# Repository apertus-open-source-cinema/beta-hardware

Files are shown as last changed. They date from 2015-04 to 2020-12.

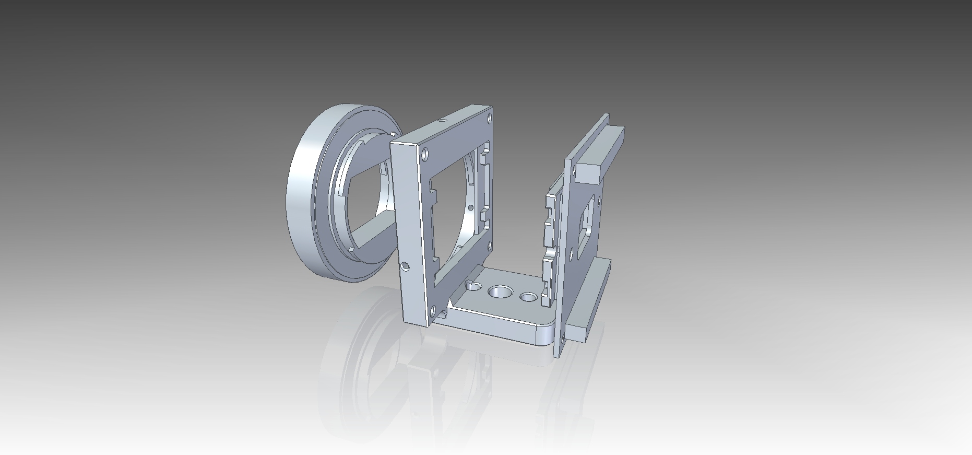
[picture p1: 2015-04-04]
Enclosure/Skeleton_E-mount/CMV12000_E-Mount_03.jpg

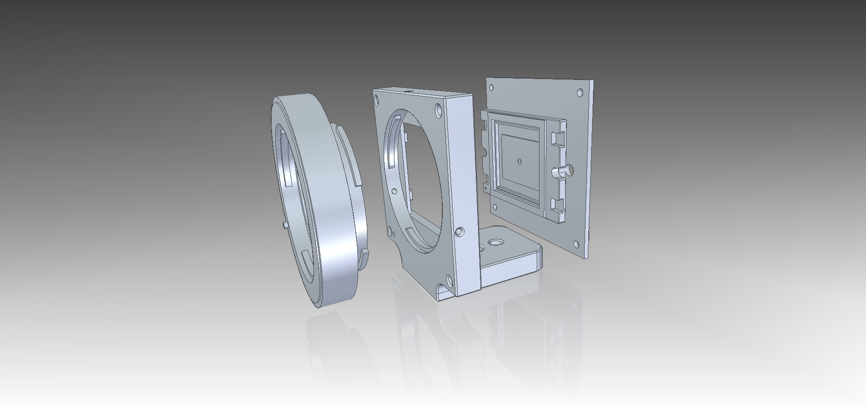
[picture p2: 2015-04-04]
Enclosure/Skeleton_E-mount/CMV12000_E-Mount_02.jpg

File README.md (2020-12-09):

View this project on [CADLAB.io](https://cadlab.io/project/23633). 

# AXIOM Beta Hardware
axiom beta enclosure concept art

This repository contains all the information and files related to the hardware of the AXIOM Beta.

The [AXIOM Beta](https://www.apertus.org/axiom-beta) is an open source, open hardware, professional-grade digital film camera made by [apertus°](https://www.apertus.org/). It is designed to be modular e.g. interchangeable sensor front end etc. and supports recording at 4K resolution.

Introduction to [camera structure](https://www.apertus.org/axiom-beta-modularity).

## Contributing
If you would like to participate in this project, please see the following links:

[apertus° Labs](https://lab.apertus.org/project/view/4/) - Tasks, discussions, etc.
Project [Wiki](https://wiki.apertus.org/index.php/Main_Page) - User manuals, BOMs etc.
Programming languages and contact [methods](https://wiki.apertus.org/index.php/How_to_Contribute).
Useful [Links](https://wiki.apertus.org/index.php/Useful_Links).

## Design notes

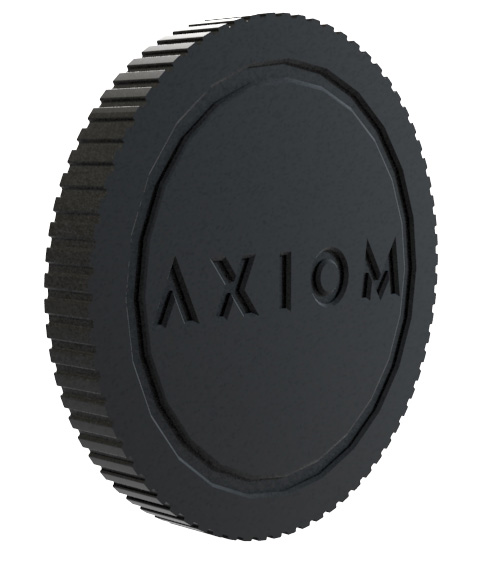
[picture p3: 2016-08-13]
E-Mount Cap/AXIOM E-Mount Cap V01 R01.jpg

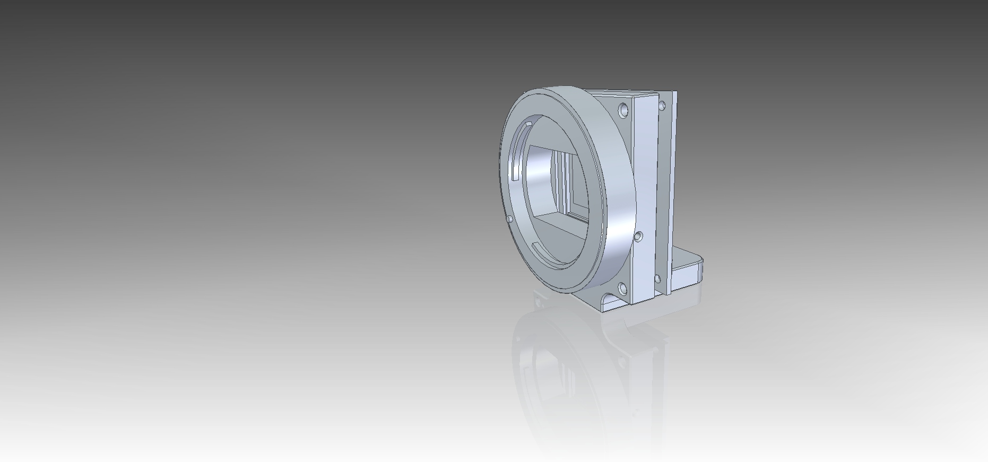
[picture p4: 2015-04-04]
Enclosure/Skeleton_E-mount/CMV12000_E-Mount_01.jpg

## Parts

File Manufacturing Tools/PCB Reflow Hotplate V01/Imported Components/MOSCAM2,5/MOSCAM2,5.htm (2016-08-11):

Autodesk Inventor Translation Report | Donnerstag, 11. August 2016 ( 20:25)
Source File: | C:\Users\spichelh\Documents\GitHub\beta-hardware\Manufacturing Tools\PCB Reflow Hotplate V01\MOSCAM2,5.SLDPRT
Translator Type: | SolidWorks | Sending System: | SolidWorks 2013
Author: |  | Translation Time: | 00:00:00
Options
Import Type: | N/A
Entity Types to Import: | Solids, Surfaces, Wires
Import into Repair Environment: | Yes
Import Assembly as Single Part: | No
Create Surfaces As: | Single Composite Feature
Check Parts during Load: | No
Auto Stitch: | No
Enable Advanced Healing: | N/A
+/- | Name | Inventor File | Status
[ ] | MOSCAM2,5.ipt | C:\Users\spichelh\Documents\GitHub\beta-hardware\Manufacturing Tools\PCB Reflow Hotplate V01\Imported Components\MOSCAM2,5\MOSCAM2,5.ipt | Successful

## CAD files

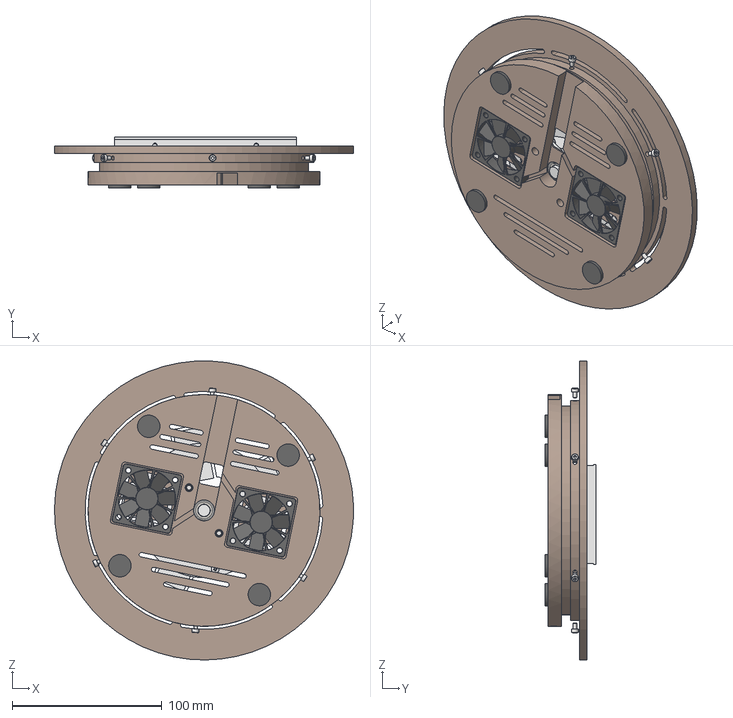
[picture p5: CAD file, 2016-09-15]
Manufacturing Tools/PCB Reflow Hotplate V01/Hotplate Assembly V01 02.stp
199.9 x 34.0 x 199.9 mm

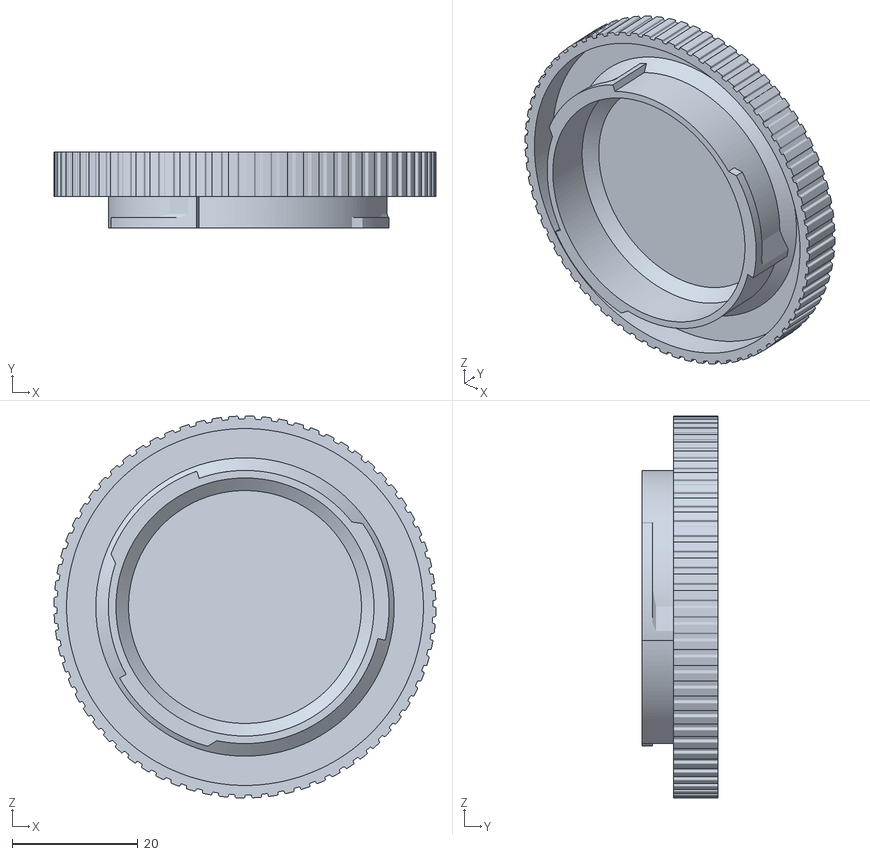
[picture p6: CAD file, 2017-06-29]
E-Mount Cap/AXIOM E-Mount Cap V01 R02.stl
60.7 x 12.0 x 60.7

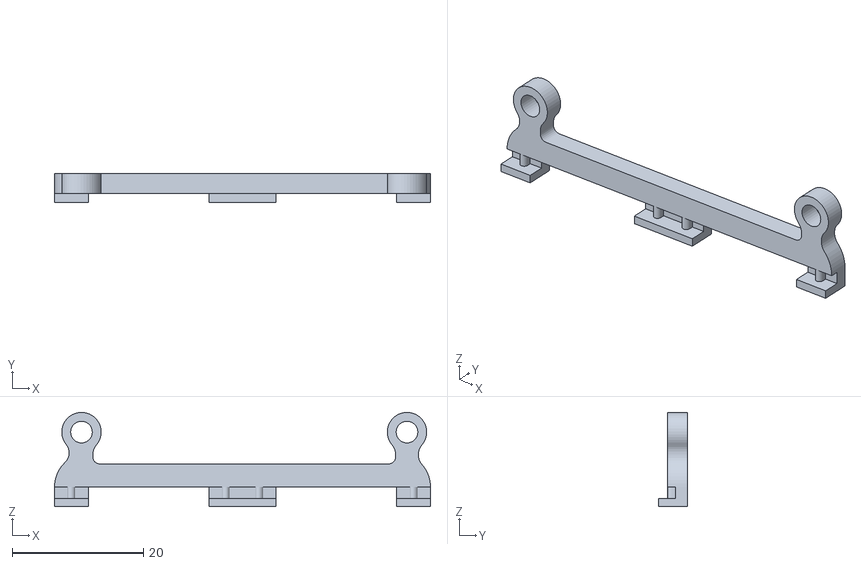
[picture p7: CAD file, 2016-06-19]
Enclosure/3D-Print-Parts/HDMIPluginModuleHolder04.stl
57.2 x 4.37 x 14.3

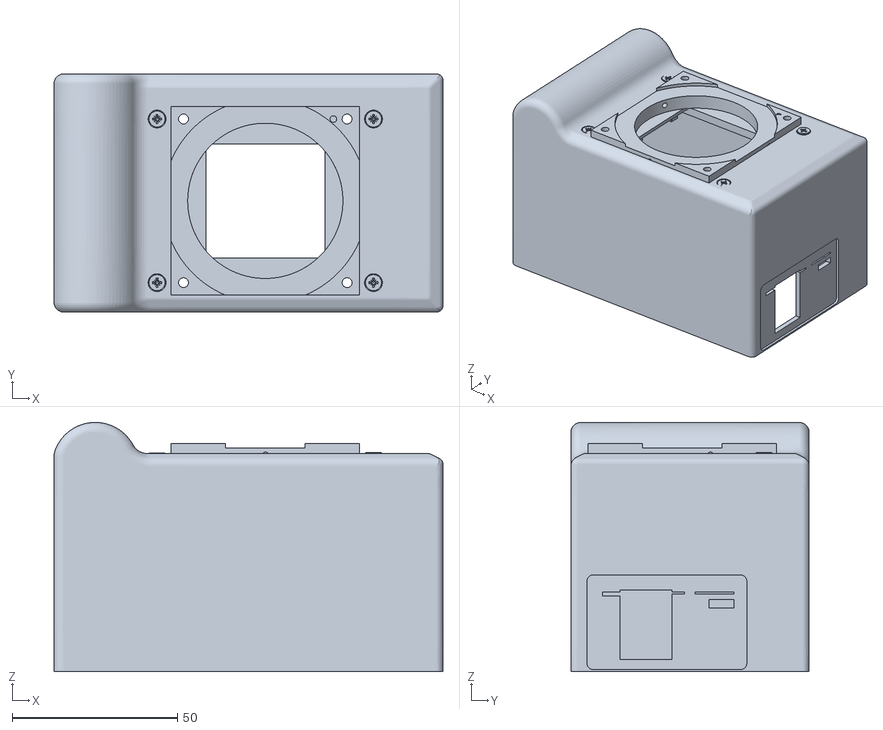
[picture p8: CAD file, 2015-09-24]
Enclosure/SimpleDesign01/SimpleDesignV2 - 01.stl
117.8 x 72.2 x 75.4

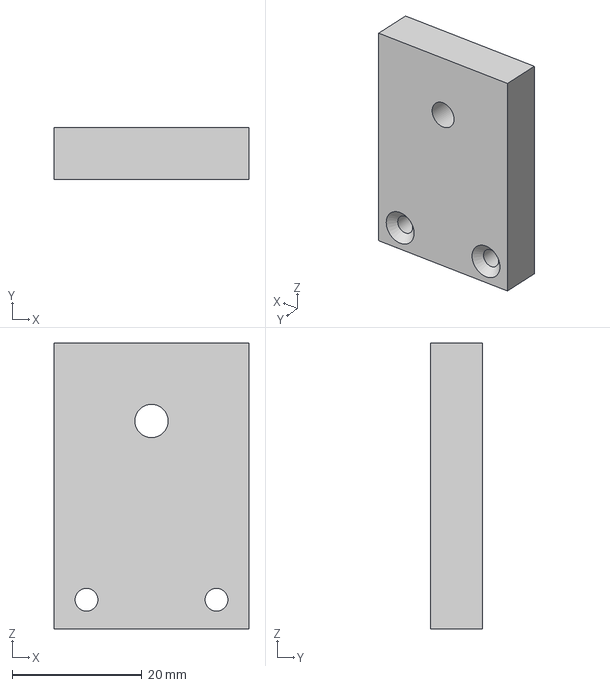
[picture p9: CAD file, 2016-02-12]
Enclosure/Skeleton_E-mount/tripod_foot_plate_150928.step
30.0 x 8.00 x 44.0 mm

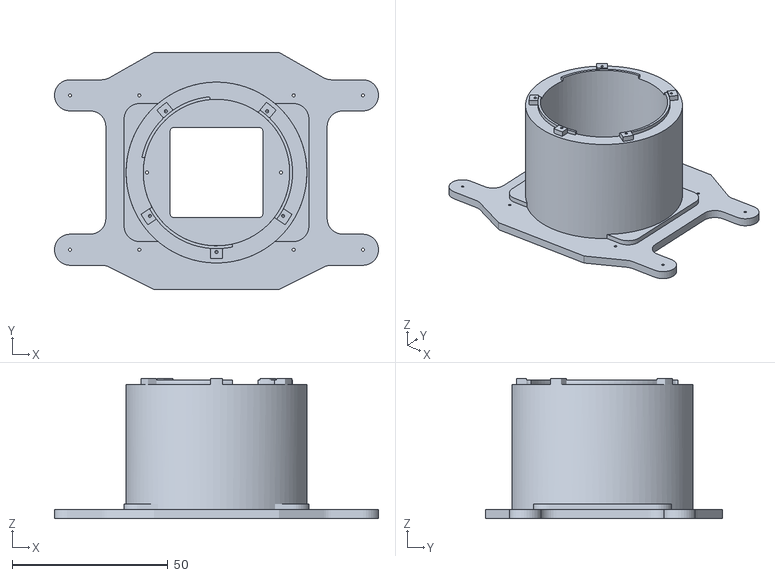
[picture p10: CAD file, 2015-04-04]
Enclosure/SkeletonV03/Skeleton V03fix-rotated.stl
103.9 x 76.1 x 45.0

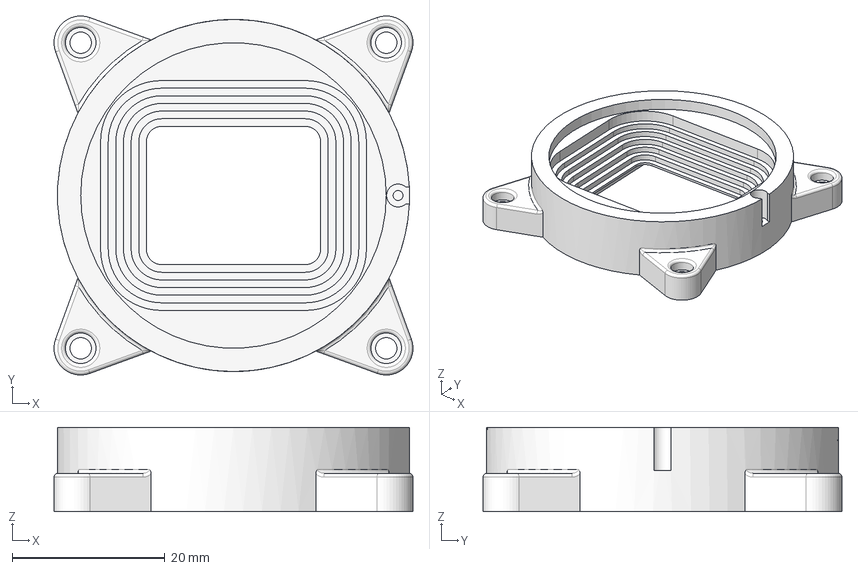
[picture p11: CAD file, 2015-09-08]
Enclosure/Version 002/E Mount.stp
47.0 x 47.0 x 11.0 mm

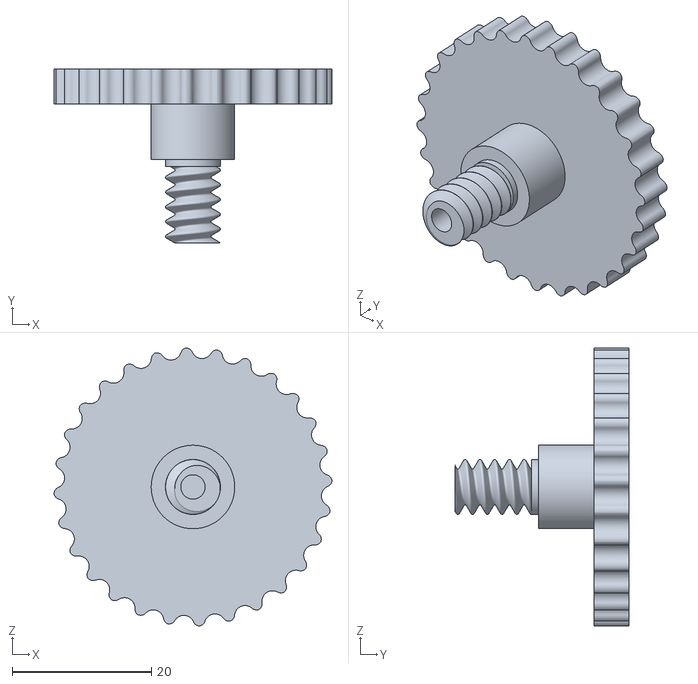
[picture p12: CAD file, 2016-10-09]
Manufacturing Tools/CMV12000 Extraction Tool V01/3d print/Knob02.stl
40.0 x 25.0 x 40.0

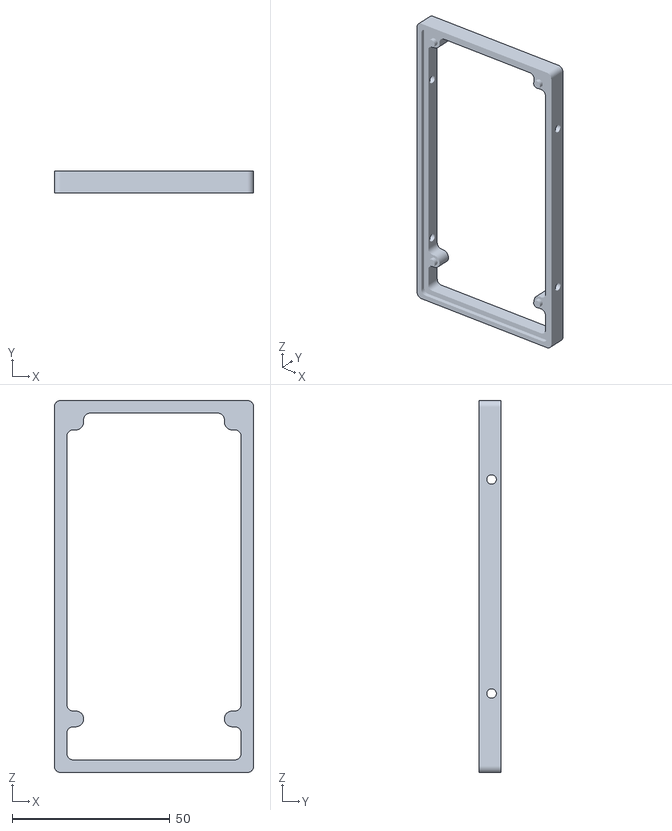
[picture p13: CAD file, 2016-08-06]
Manufacturing Tools/PCB Reflow Bracket V01/Bracket_BOT_V05.stl
63.2 x 7.00 x 117.8

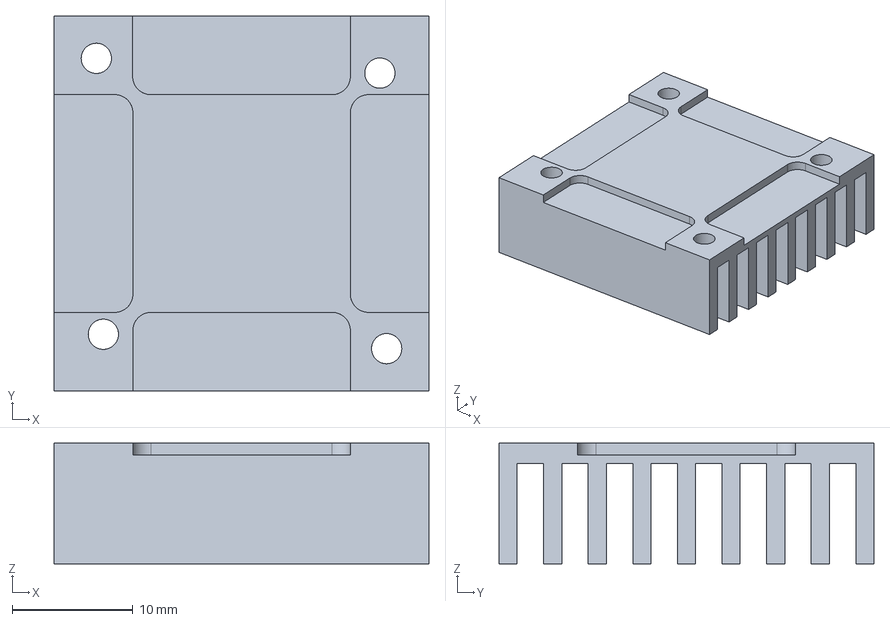
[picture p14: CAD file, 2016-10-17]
Microzed-Heatsink/Heatsink_31x31x10.stp
31.0 x 31.0 x 10.0 mm

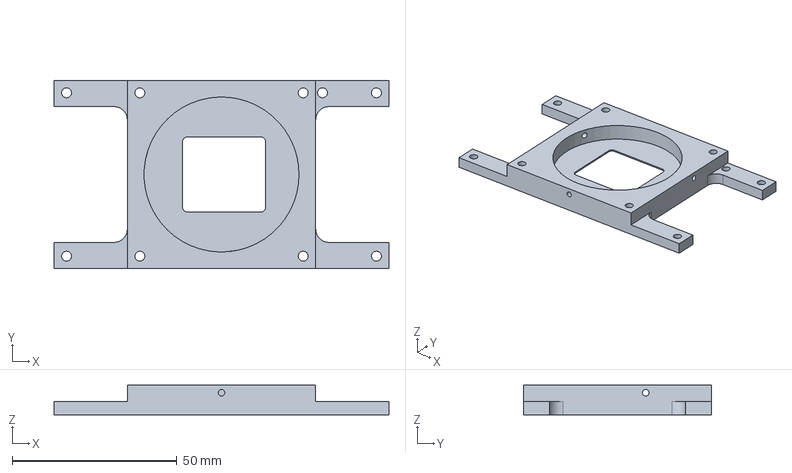
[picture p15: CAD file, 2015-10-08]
Enclosure/Skeleton_E-mount/Skeleton-Emount.stp
101.6 x 57.2 x 9.00 mm

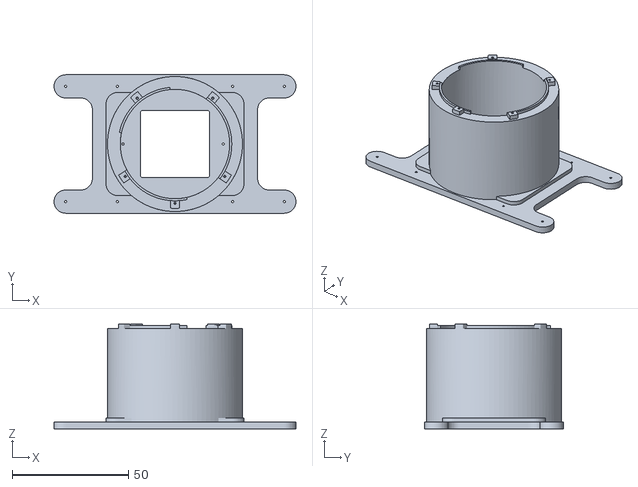
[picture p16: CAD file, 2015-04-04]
Enclosure/SkeletonV03/Skeleton V03fix-nose-cut.stl
104.0 x 59.5 x 45.0

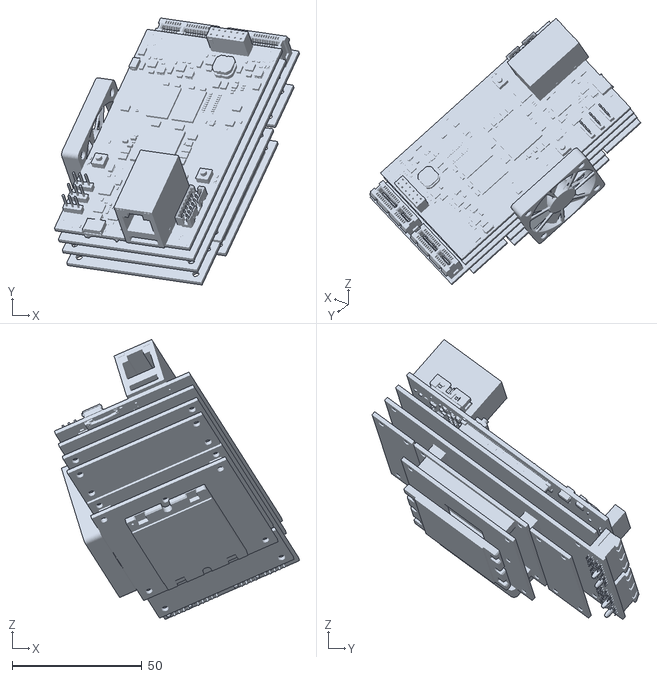
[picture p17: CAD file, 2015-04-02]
Enclosure/Version 002/PCB Stack Concept V03 02.stl
94.6 x 103.0 x 108.0

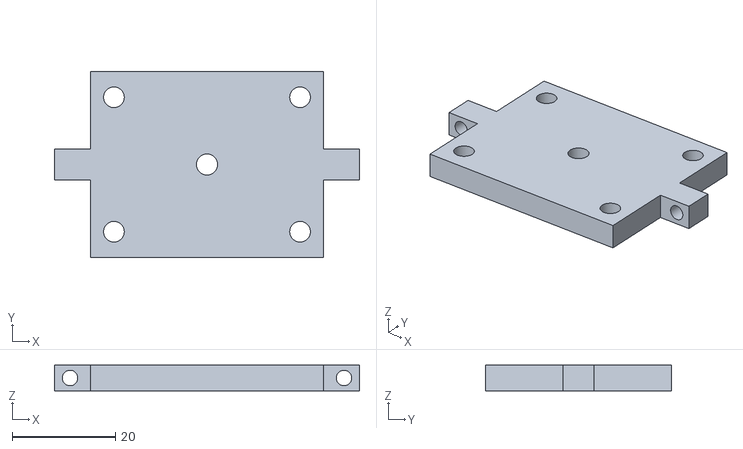
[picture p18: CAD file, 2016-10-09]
Manufacturing Tools/CMV12000 Extraction Tool V01/3d print/mover02.stl
59.0 x 35.9 x 5.00

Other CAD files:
Enclosure/SimpleDesign02/HDMI Plugin Module-Export1.dwg
E-Mount Cap/AXIOM E-Mount Cap V01 R01.step
Enclosure/3D-Print-Parts/HDMIPluginModuleHolder03.stl
Enclosure/SimpleDesign02/HDMI Plugin Module-1.dwg
E-Mount Cap/AXIOM E-Mount Cap V01 R01.3dm
E-Mount Cap/AXIOM E-Mount Cap V01 R01.sldprt
E-Mount Cap/AXIOM E-Mount Cap V01 R01.stl
E-Mount Cap/AXIOM E-Mount Cap V01 R01.x_t
Enclosure/3D-Print-Parts/Archived/HDMIPluginModuleHolder01.stl
Enclosure/3D-Print-Parts/Archived/SimpleDesignV2-R01-Back.stl
Enclosure/3D-Print-Parts/Archived/SimpleDesignV2-R01-Front.stl
Enclosure/3D-Print-Parts/HDMIPluginModuleHolder01.stl
Enclosure/3D-Print-Parts/HDMIPluginModuleHolder02.stl
Enclosure/3D-Print-Parts/PCB-Separator-Tool-V01.stl
Enclosure/3D-Print-Parts/SimpleDesignV2 - Front.stl
Enclosure/3D-Print-Parts/SimpleDesignV2-R02-Back.stl
Enclosure/3D-Print-Parts/SimpleDesignV2-R02-Front.stl
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

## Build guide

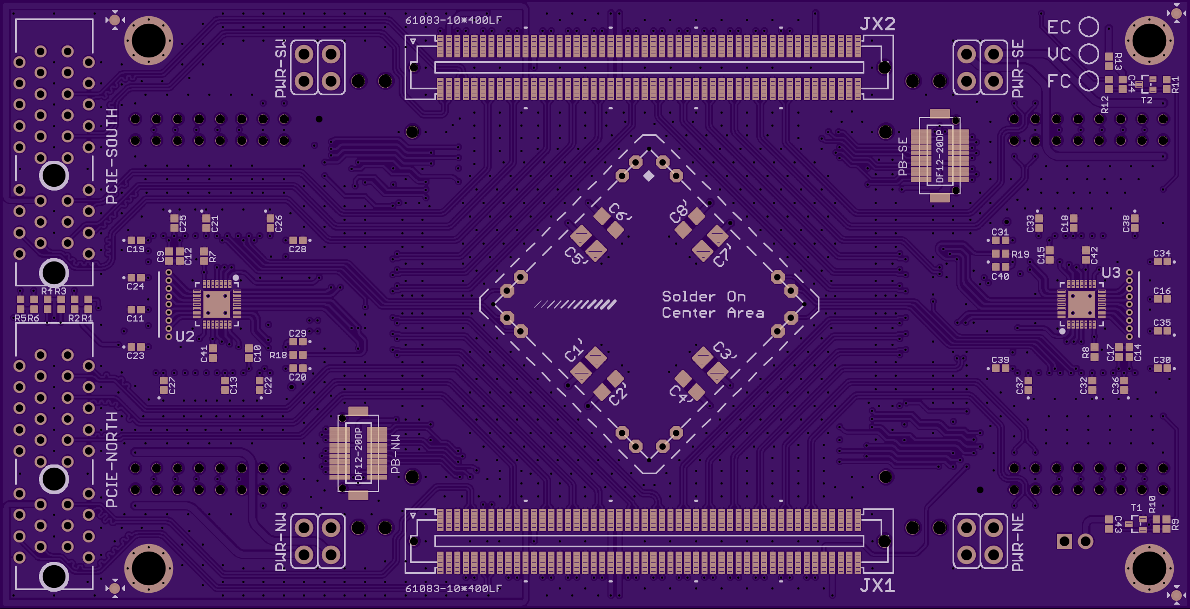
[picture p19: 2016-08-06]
Manufacturing Tools/PCB Reflow Bracket V01/Top.png

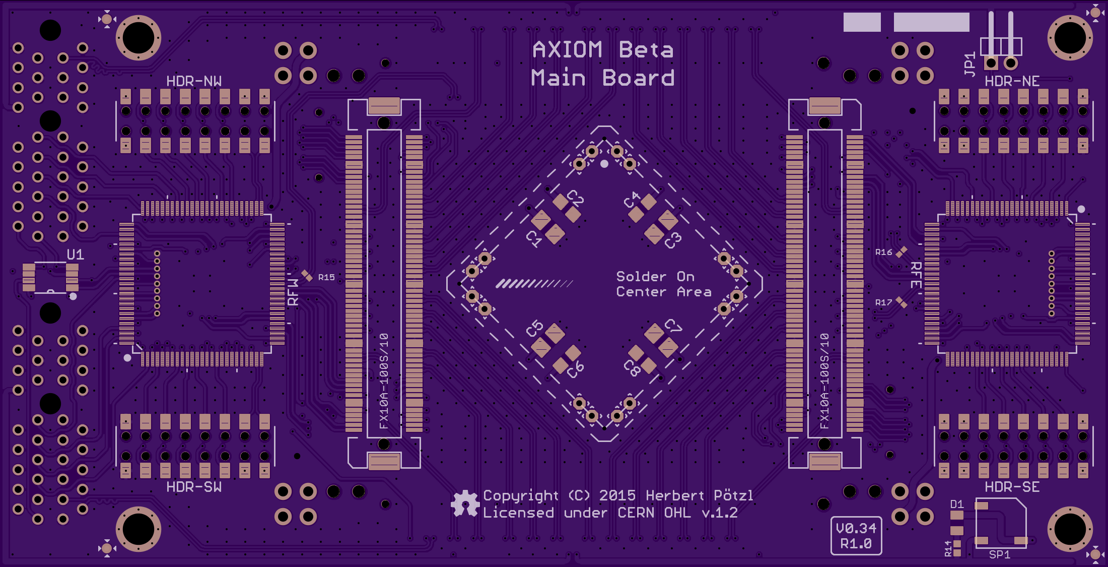
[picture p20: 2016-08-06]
Manufacturing Tools/PCB Reflow Bracket V01/Bottom.png

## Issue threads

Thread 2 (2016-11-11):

Scematics and Board Layout files are missing

jatha, 2016-11-11:

sp-apertus, 2016-11-11:
collect and commit them to github from here: https://wiki.apertus.org/index.php/AXIOM_Beta/AXIOM_Beta_Hardware#Printed_Circuit_Boards

davidak, 2017-11-12:
@herbertp will do it: https://lab.apertus.org/T827

jatha, 2017-11-13:
moved to the lab

Closed 2017-11-13.

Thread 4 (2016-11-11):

Split repository up

jatha, 2016-11-11:
Maybe it would be better to have more small repositorys with a single part instead of one big.
For examlpe an extra repo for the Lenscap, one for the Enclosure and so on...

sp-apertus, 2016-11-11:
I think it would negatively affect overview.

jatha, 2017-11-12:
ok

Closed 2017-11-12.

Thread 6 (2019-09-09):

Any interest in providing FreeCAD files?

luzpaz, 2019-09-09:
I do reach out for the FreeCAD community. In the past we've helped Open Source projects with their CAD design. Would you be interested in such a thing? It would also provide a good exercise for folks who want to learn how to use FC to create FreeCAD files for you. Let me know if you're interested?

Cheers

luzpaz, 2019-09-09:
Example: https://forum.freecadweb.org/viewtopic.php?f=8&t=38643

sp-apertus, 2019-09-10:
Hi there

I am currently doing most CAD work in the project in onshape so a FOSS alternative would be great indeed, I tried FreeCAD already for a bit but without someone helping/answering questions I did not get far unfortunately. So any help on this front would be much appreciated, I can dedicate some, not a whole lot of time to this but it would be great to get more people from our community and maybe even the outside interested.

Regards Sebastian

luzpaz, 2019-09-10:
@sp-apertus Nice! Please feel free to post on our forum when you feel ready. If you can provide proper measurements and non-proprietary files (that we can open and inspect) that would definitely facilitate the process, for sure!

sp-apertus, 2019-09-16:
What file format do you recommend?

luzpaz, 2019-09-16:
@sp-apertus well for the measurements maybe a screenshot of the technical drawings ? I recommend asking on the forum.

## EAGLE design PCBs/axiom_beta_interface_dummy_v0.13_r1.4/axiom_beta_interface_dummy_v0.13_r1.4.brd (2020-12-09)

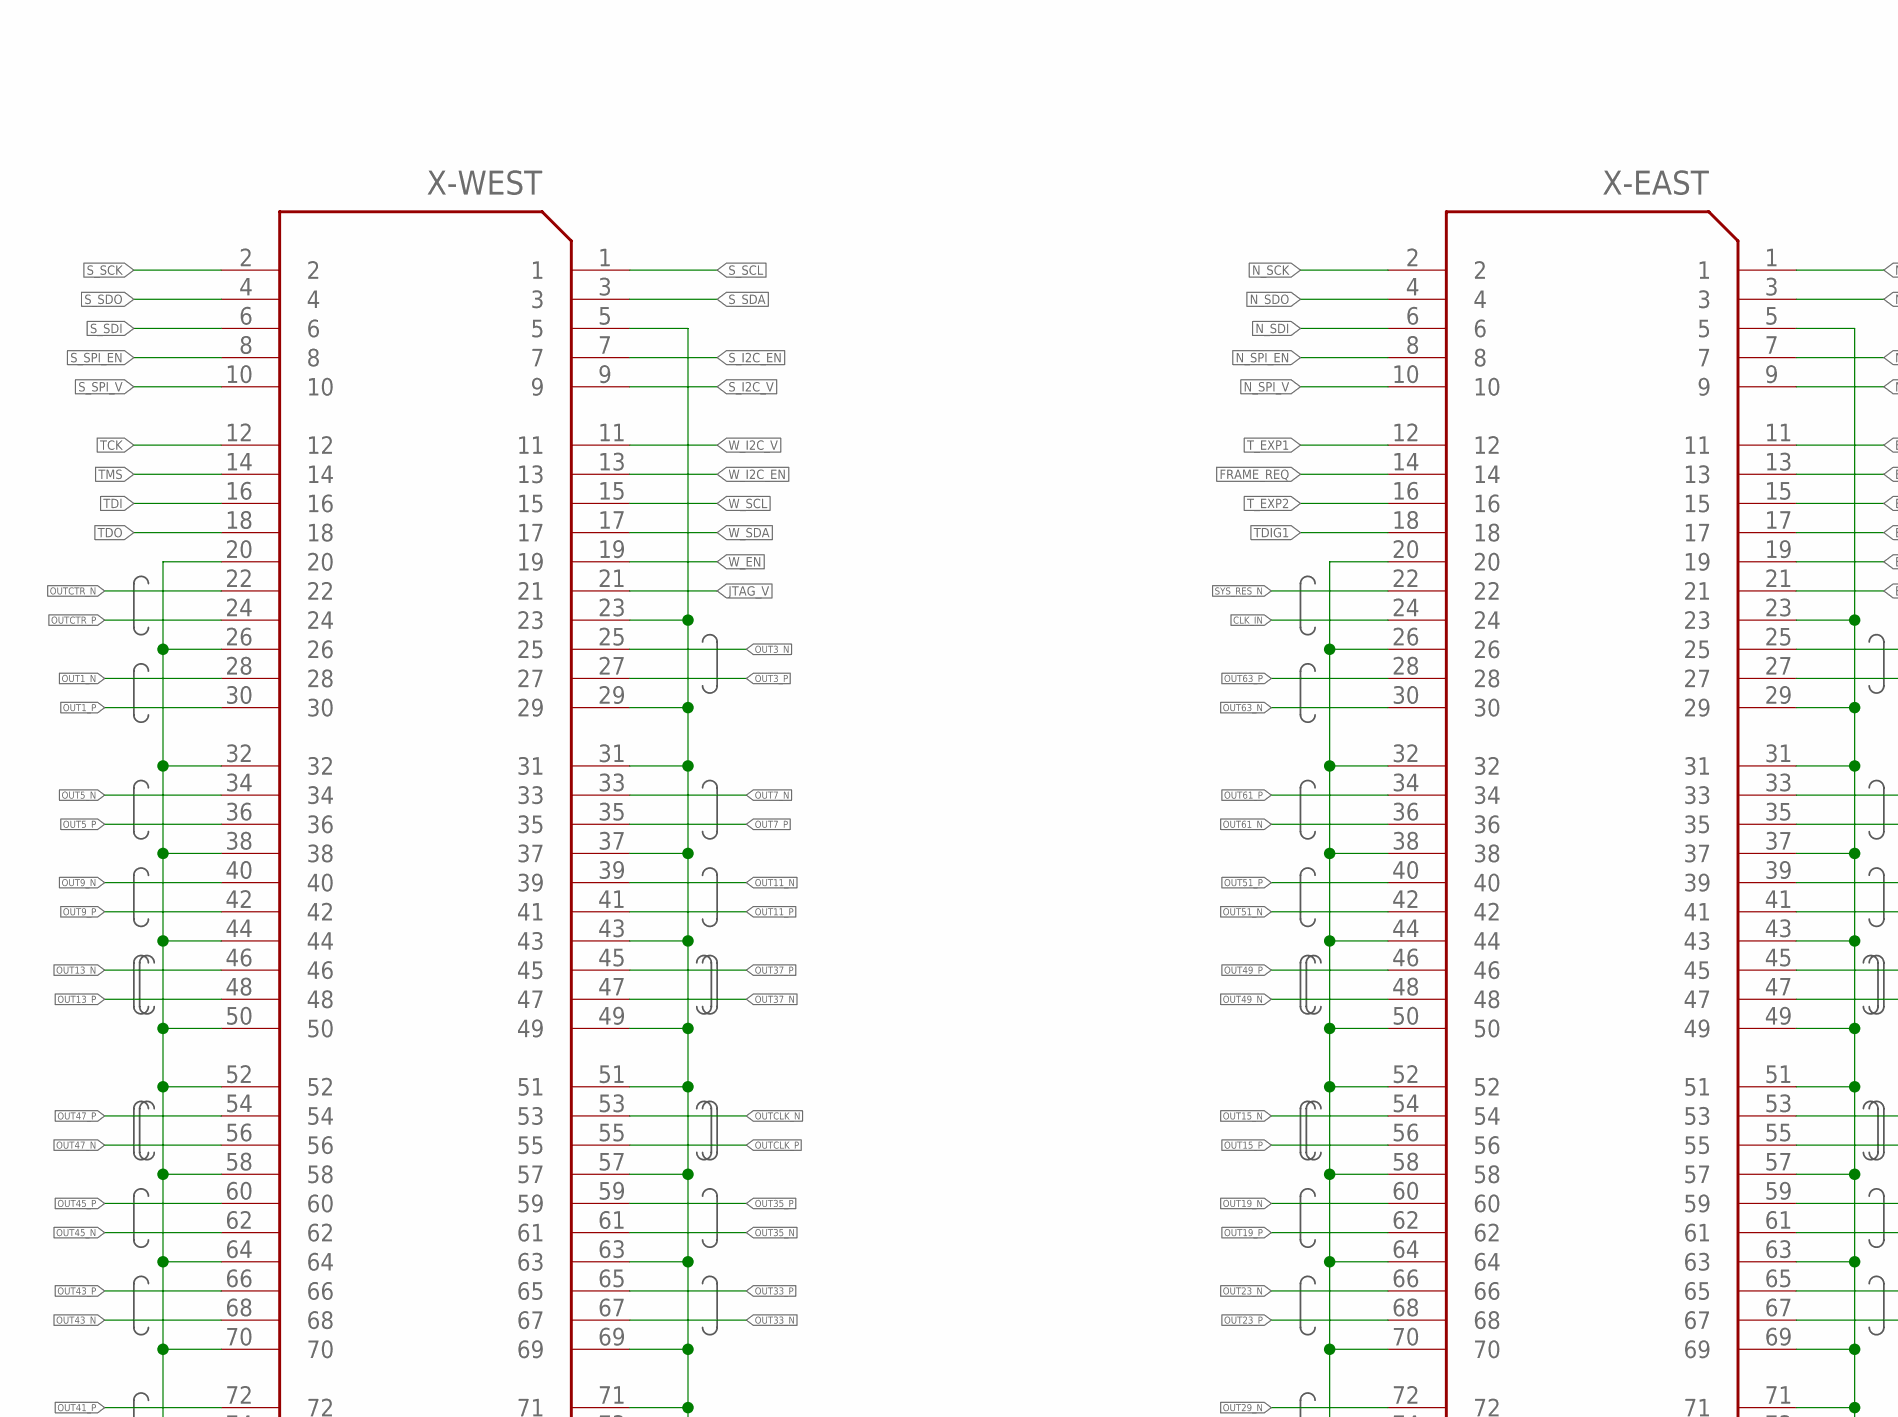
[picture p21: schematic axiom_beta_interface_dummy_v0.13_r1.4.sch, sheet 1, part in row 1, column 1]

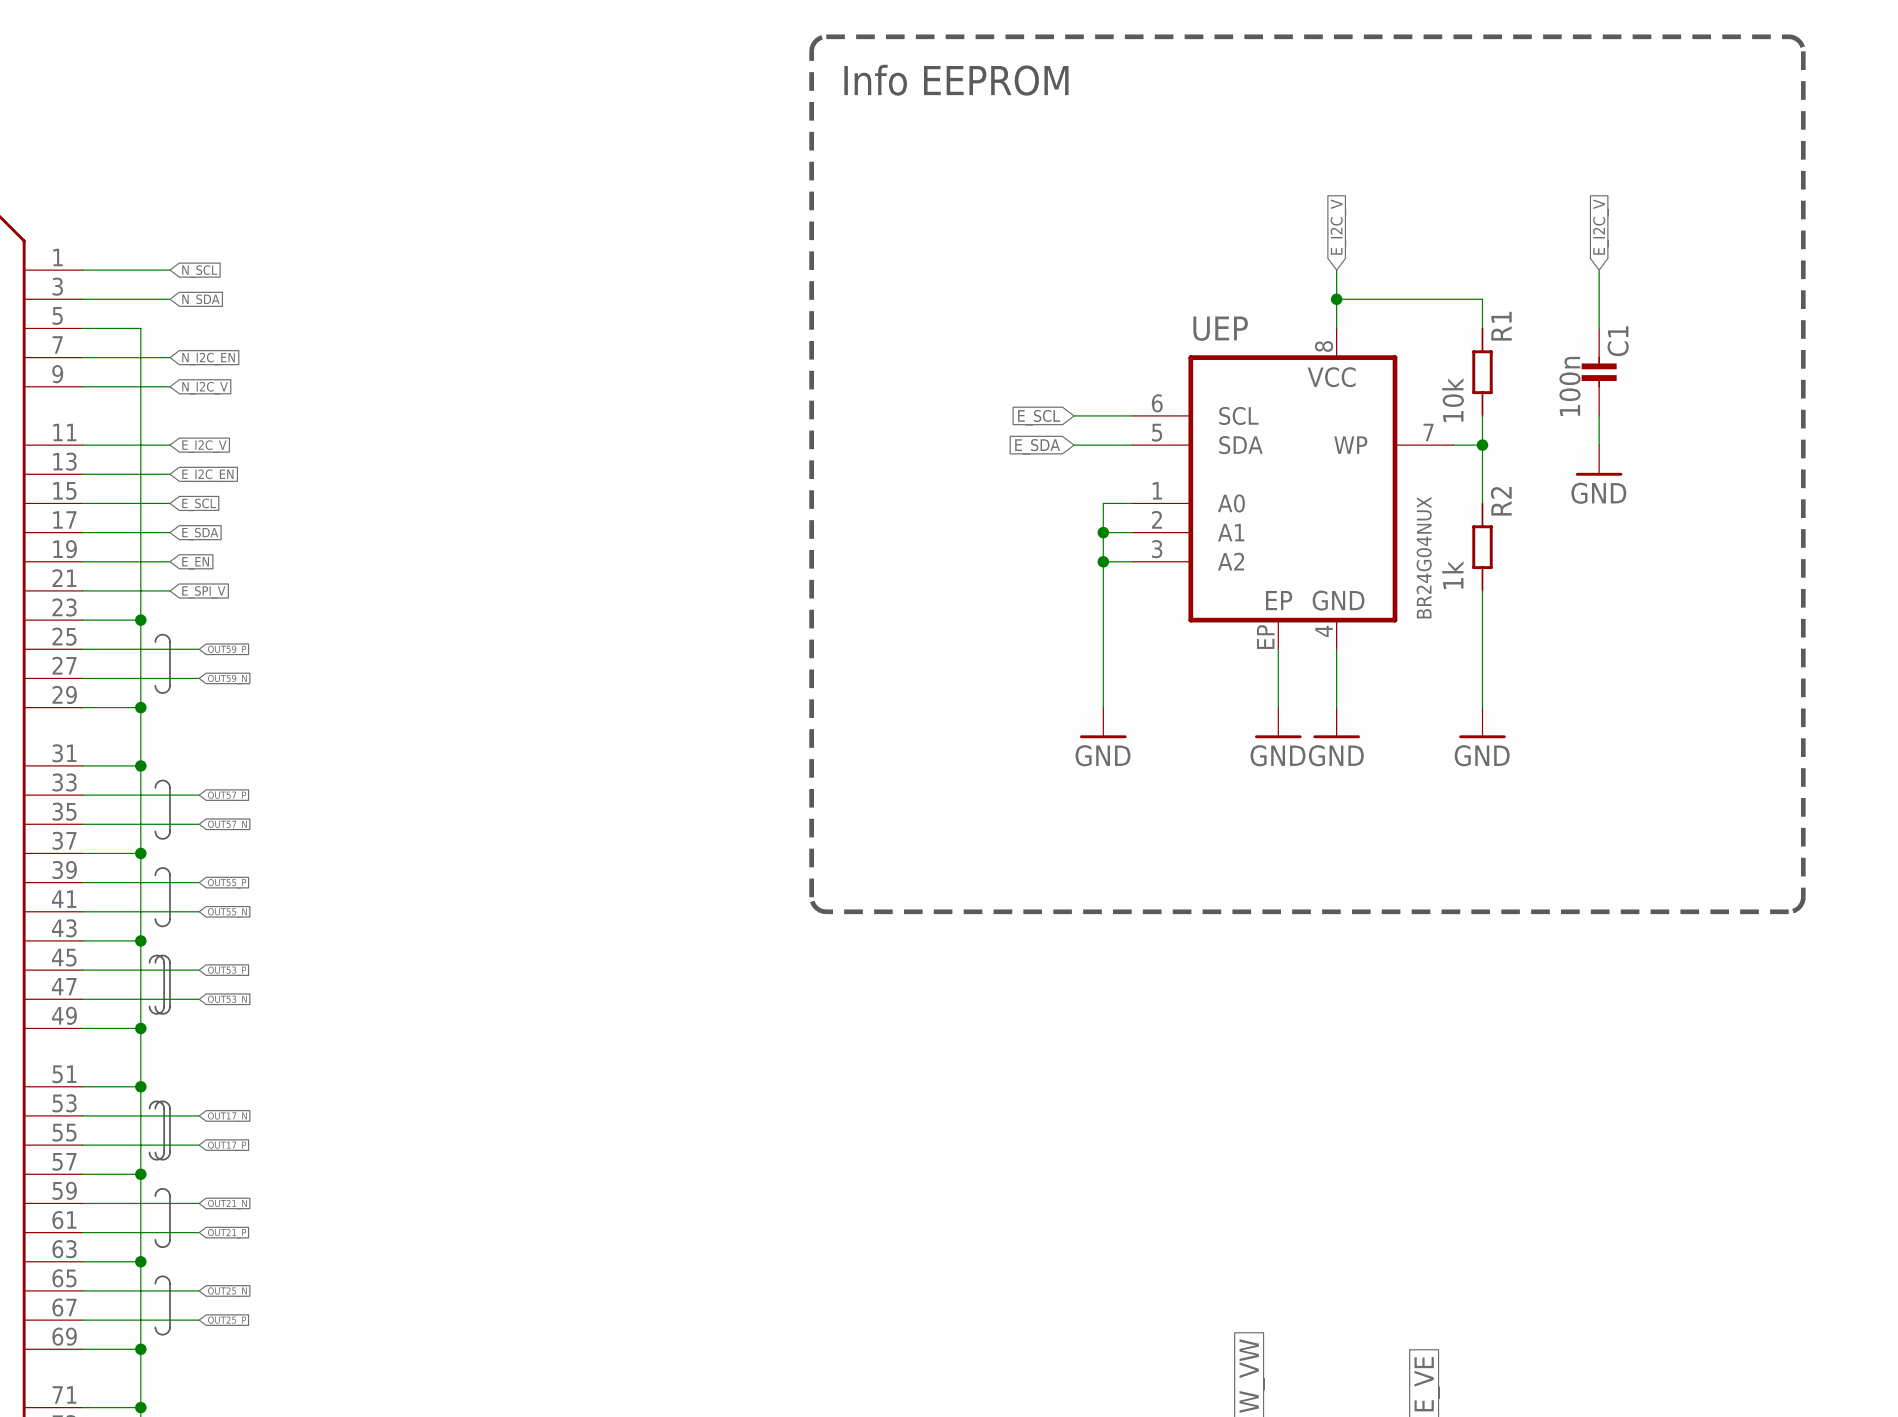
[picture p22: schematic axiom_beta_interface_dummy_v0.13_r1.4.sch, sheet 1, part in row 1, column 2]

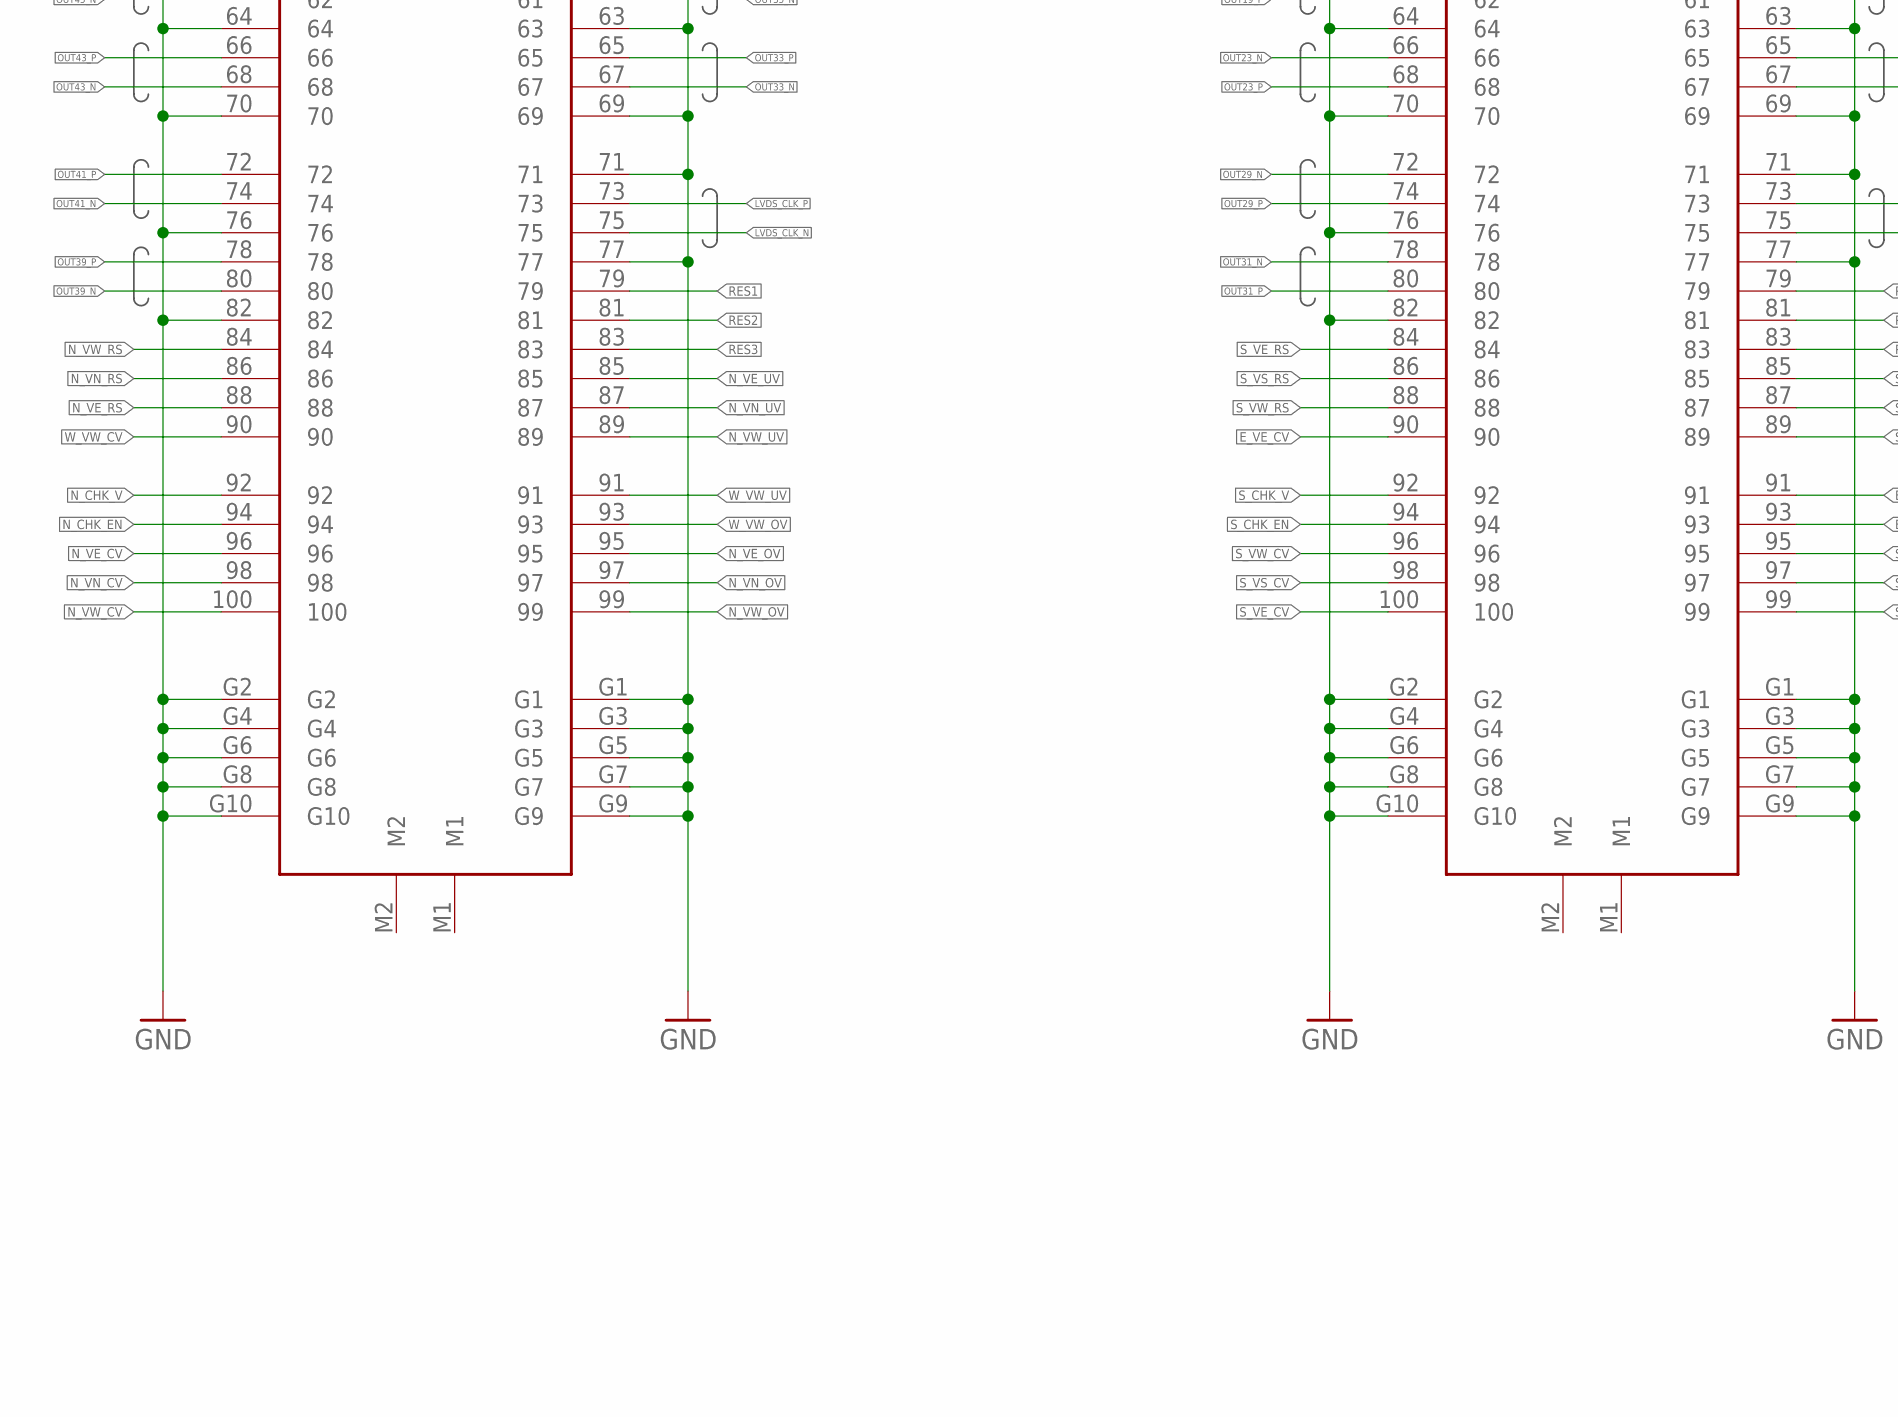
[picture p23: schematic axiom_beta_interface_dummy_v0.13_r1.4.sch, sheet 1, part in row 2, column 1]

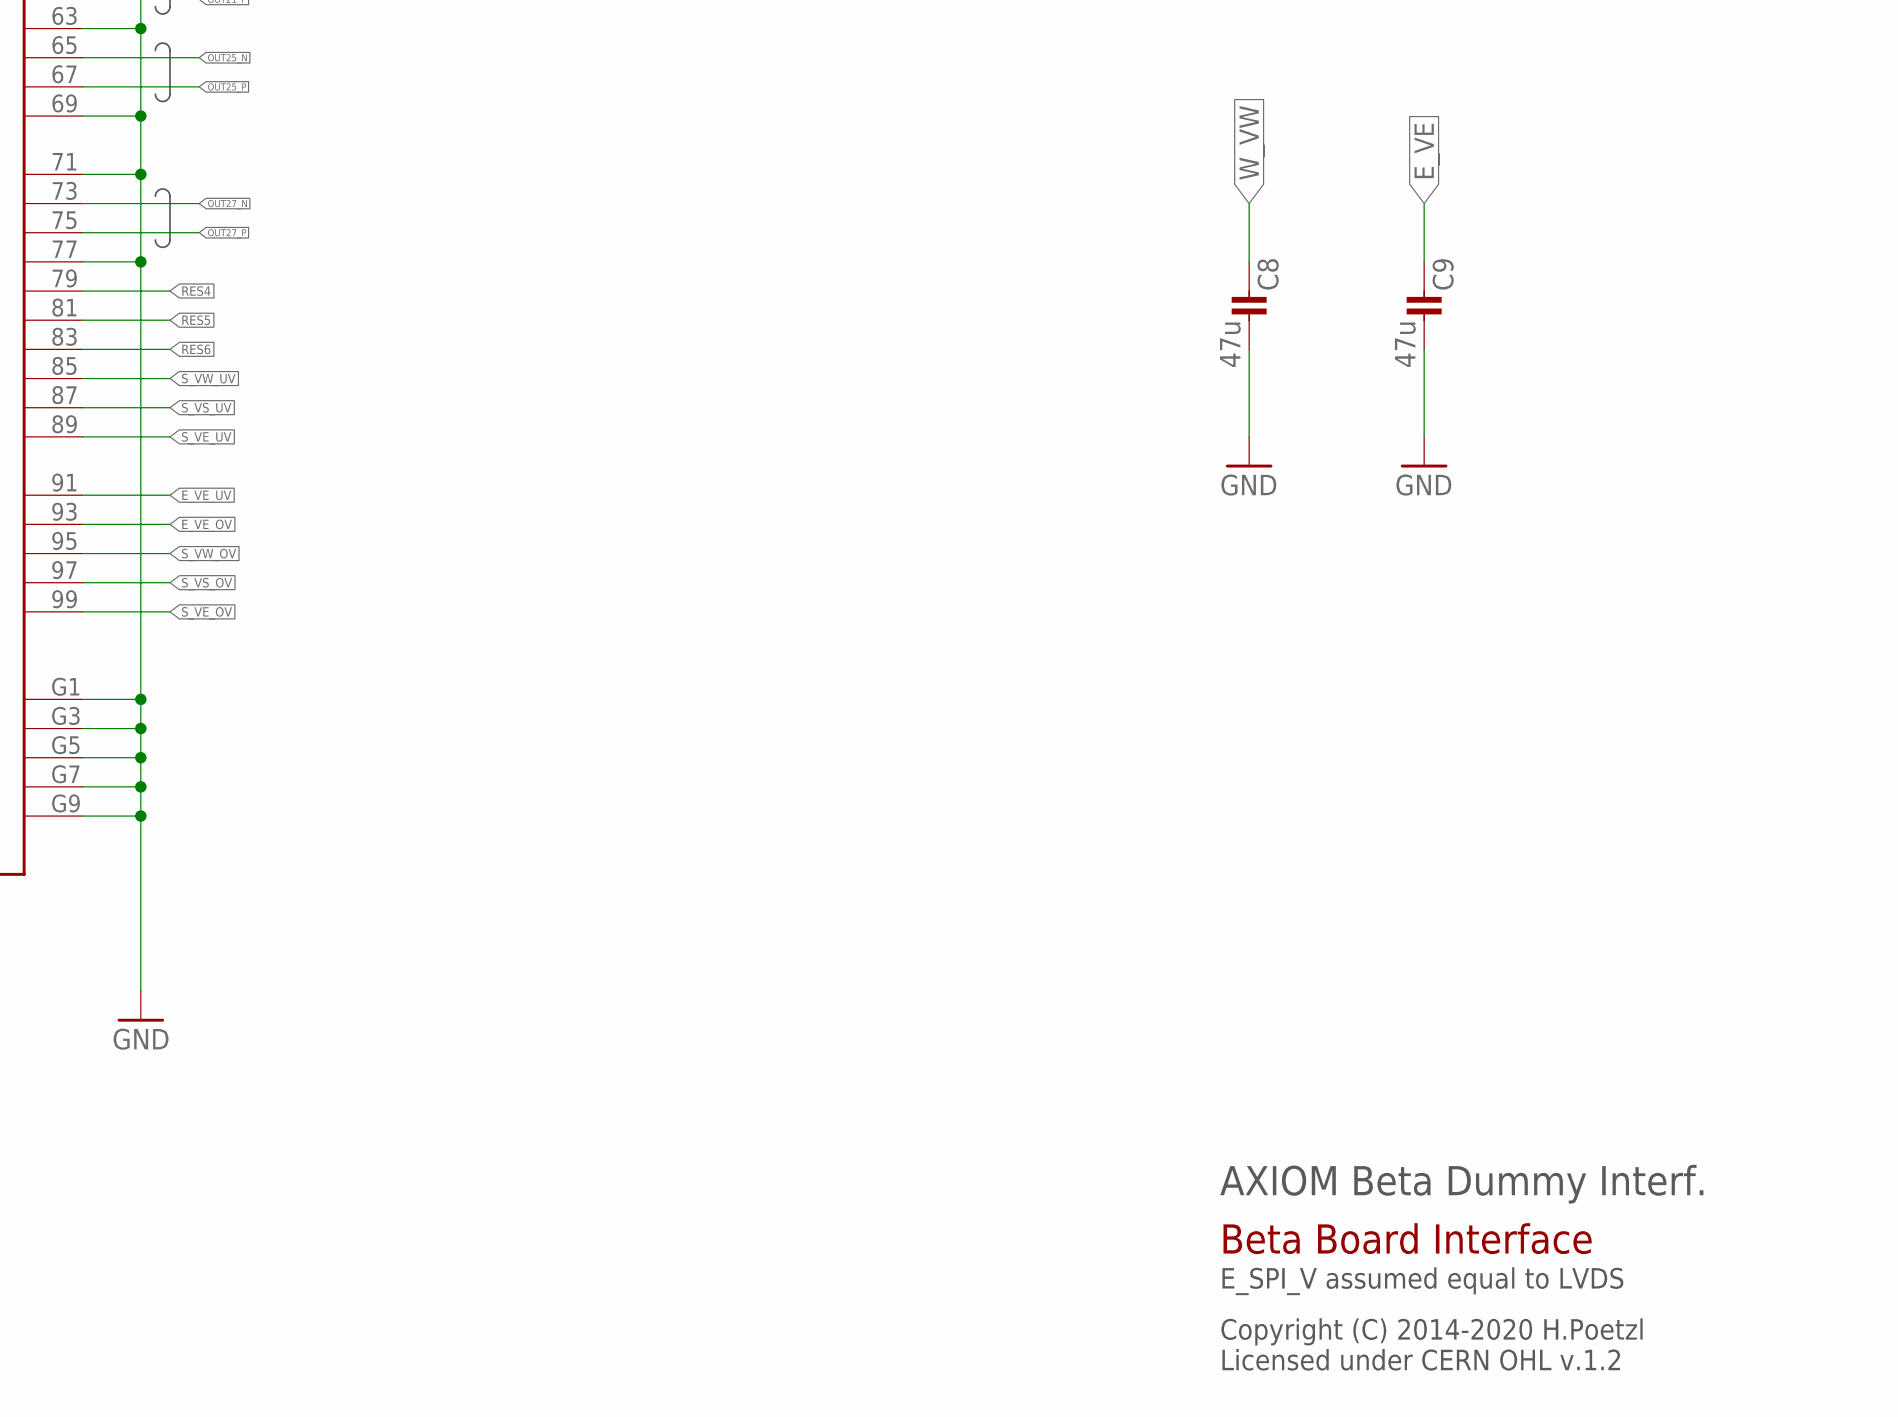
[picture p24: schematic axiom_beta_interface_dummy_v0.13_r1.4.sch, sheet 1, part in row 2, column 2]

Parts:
C1: 100n; 0402-B
C8, C9: 47u; 0805-B
R1: 10k; 0402-B
R2: 1k; 0402-B
UEP: BR24G04NUX; DFN200X300X100-9N
X-EAST: FX10-100/10P; FX10A-100P/10
X-WEST: FX10-100/10P; FX10A-100P/10

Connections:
CLK_IN: X-EAST.24; also elsewhere on the board
E_EN: X-EAST.19
E_I2C_EN: X-EAST.13
E_I2C_V: C1.1, R1.1, UEP.8 (VCC), X-EAST.11
E_SCL: UEP.6 (SCL), X-EAST.15
E_SDA: UEP.5 (SDA), X-EAST.17
E_SPI_V: X-EAST.21
E_VE: C9.1; also elsewhere on the board
E_VE_CV: X-EAST.90
E_VE_OV: X-EAST.93
E_VE_UV: X-EAST.91
FRAME_REQ: X-EAST.14; also elsewhere on the board
GND: C1.2, C8.2, C9.2, R2.2, UEP.1 (A0), UEP.2 (A1), UEP.3 (A2), UEP.4 (GND), UEP.EP, X-EAST.5, X-EAST.20, X-EAST.23, X-EAST.26, X-EAST.29, X-EAST.31, X-EAST.32, X-EAST.37, X-EAST.38, X-EAST.43, X-EAST.44, X-EAST.49, X-EAST.50, X-EAST.51, X-EAST.52, X-EAST.57, X-EAST.58, X-EAST.63, X-EAST.64, X-EAST.69, X-EAST.70, X-EAST.71, X-EAST.76, X-EAST.77, X-EAST.82, X-EAST.G1, X-EAST.G2, X-EAST.G3, X-EAST.G4, X-EAST.G5, X-EAST.G6, X-EAST.G7, X-EAST.G8, X-EAST.G9, X-EAST.G10, X-WEST.5, X-WEST.20, X-WEST.23, X-WEST.26, X-WEST.29, X-WEST.31, X-WEST.32, X-WEST.37, X-WEST.38, X-WEST.43, X-WEST.44, X-WEST.49, X-WEST.50, X-WEST.51, X-WEST.52, X-WEST.57, X-WEST.58, X-WEST.63, X-WEST.64, X-WEST.69, X-WEST.70, X-WEST.71, X-WEST.76, X-WEST.77, X-WEST.82, X-WEST.G1, X-WEST.G2, X-WEST.G3, X-WEST.G4, X-WEST.G5, X-WEST.G6, X-WEST.G7, X-WEST.G8, X-WEST.G9, X-WEST.G10; also elsewhere on the board
JTAG_V: X-WEST.21
LVDS_CLK_N: X-WEST.75; also elsewhere on the board
LVDS_CLK_P: X-WEST.73; also elsewhere on the board
unnamed: R1.2, R2.1, UEP.7 (WP)
N_CHK_EN: X-WEST.94; also elsewhere on the board
N_CHK_V: X-WEST.92; also elsewhere on the board
N_I2C_EN: X-EAST.7; also elsewhere on the board
N_I2C_V: X-EAST.9; also elsewhere on the board
N_SCK: X-EAST.2; also elsewhere on the board
N_SCL: X-EAST.1; also elsewhere on the board
N_SDA: X-EAST.3; also elsewhere on the board
N_SDI: X-EAST.6; also elsewhere on the board
N_SDO: X-EAST.4; also elsewhere on the board
N_SPI_EN: X-EAST.8; also elsewhere on the board
N_SPI_V: X-EAST.10; also elsewhere on the board
N_VE_CV: X-WEST.96; also elsewhere on the board
N_VE_OV: X-WEST.95; also elsewhere on the board
N_VE_RS: X-WEST.88; also elsewhere on the board
N_VE_UV: X-WEST.85; also elsewhere on the board
N_VN_CV: X-WEST.98; also elsewhere on the board
N_VN_OV: X-WEST.97; also elsewhere on the board
N_VN_RS: X-WEST.86; also elsewhere on the board
N_VN_UV: X-WEST.87; also elsewhere on the board
N_VW_CV: X-WEST.100; also elsewhere on the board
N_VW_OV: X-WEST.99; also elsewhere on the board
N_VW_RS: X-WEST.84; also elsewhere on the board
N_VW_UV: X-WEST.89; also elsewhere on the board
OUT1_N: X-WEST.28; also elsewhere on the board
OUT1_P: X-WEST.30; also elsewhere on the board
OUT3_N: X-WEST.25; also elsewhere on the board
OUT3_P: X-WEST.27; also elsewhere on the board
OUT5_N: X-WEST.34; also elsewhere on the board
OUT5_P: X-WEST.36; also elsewhere on the board
OUT7_N: X-WEST.33; also elsewhere on the board
OUT7_P: X-WEST.35; also elsewhere on the board
OUT9_N: X-WEST.40; also elsewhere on the board
OUT9_P: X-WEST.42; also elsewhere on the board
OUT11_N: X-WEST.39; also elsewhere on the board
OUT11_P: X-WEST.41; also elsewhere on the board
OUT13_N: X-WEST.46; also elsewhere on the board
OUT13_P: X-WEST.48; also elsewhere on the board
OUT15_N: X-EAST.54; also elsewhere on the board
OUT15_P: X-EAST.56; also elsewhere on the board
OUT17_N: X-EAST.53; also elsewhere on the board
OUT17_P: X-EAST.55; also elsewhere on the board
OUT19_N: X-EAST.60; also elsewhere on the board
OUT19_P: X-EAST.62; also elsewhere on the board
OUT21_N: X-EAST.59; also elsewhere on the board
OUT21_P: X-EAST.61; also elsewhere on the board
OUT23_N: X-EAST.66; also elsewhere on the board
OUT23_P: X-EAST.68; also elsewhere on the board
OUT25_N: X-EAST.65; also elsewhere on the board
OUT25_P: X-EAST.67; also elsewhere on the board
OUT27_N: X-EAST.73; also elsewhere on the board
OUT27_P: X-EAST.75; also elsewhere on the board
OUT29_N: X-EAST.72; also elsewhere on the board
OUT29_P: X-EAST.74; also elsewhere on the board
OUT31_N: X-EAST.78; also elsewhere on the board
OUT31_P: X-EAST.80; also elsewhere on the board
OUT33_N: X-WEST.67; also elsewhere on the board
OUT33_P: X-WEST.65; also elsewhere on the board
OUT35_N: X-WEST.61; also elsewhere on the board
OUT35_P: X-WEST.59; also elsewhere on the board
OUT37_N: X-WEST.47; also elsewhere on the board
OUT37_P: X-WEST.45; also elsewhere on the board
OUT39_N: X-WEST.80; also elsewhere on the board
OUT39_P: X-WEST.78; also elsewhere on the board
OUT41_N: X-WEST.74; also elsewhere on the board
OUT41_P: X-WEST.72; also elsewhere on the board
OUT43_N: X-WEST.68; also elsewhere on the board
OUT43_P: X-WEST.66; also elsewhere on the board
OUT45_N: X-WEST.62; also elsewhere on the board
OUT45_P: X-WEST.60; also elsewhere on the board
OUT47_N: X-WEST.56; also elsewhere on the board
OUT47_P: X-WEST.54; also elsewhere on the board
OUT49_N: X-EAST.48; also elsewhere on the board
OUT49_P: X-EAST.46; also elsewhere on the board
OUT51_N: X-EAST.42; also elsewhere on the board
OUT51_P: X-EAST.40; also elsewhere on the board
OUT53_N: X-EAST.47; also elsewhere on the board
OUT53_P: X-EAST.45; also elsewhere on the board
OUT55_N: X-EAST.41; also elsewhere on the board
OUT55_P: X-EAST.39; also elsewhere on the board
OUT57_N: X-EAST.35; also elsewhere on the board
OUT57_P: X-EAST.33; also elsewhere on the board
OUT59_N: X-EAST.27; also elsewhere on the board
OUT59_P: X-EAST.25; also elsewhere on the board
OUT61_N: X-EAST.36; also elsewhere on the board
OUT61_P: X-EAST.34; also elsewhere on the board
OUT63_N: X-EAST.30; also elsewhere on the board
OUT63_P: X-EAST.28; also elsewhere on the board
OUTCLK_N: X-WEST.53; also elsewhere on the board
OUTCLK_P: X-WEST.55; also elsewhere on the board
OUTCTR_N: X-WEST.22; also elsewhere on the board
OUTCTR_P: X-WEST.24; also elsewhere on the board
RES1: X-WEST.79
RES2: X-WEST.81
RES3: X-WEST.83
RES4: X-EAST.79
RES5: X-EAST.81
RES6: X-EAST.83
SYS_RES_N: X-EAST.22; also elsewhere on the board
S_CHK_EN: X-EAST.94; also elsewhere on the board
S_CHK_V: X-EAST.92; also elsewhere on the board
S_I2C_EN: X-WEST.7; also elsewhere on the board
S_I2C_V: X-WEST.9; also elsewhere on the board
S_SCK: X-WEST.2; also elsewhere on the board
S_SCL: X-WEST.1; also elsewhere on the board
S_SDA: X-WEST.3; also elsewhere on the board
S_SDI: X-WEST.6; also elsewhere on the board
S_SDO: X-WEST.4; also elsewhere on the board
S_SPI_EN: X-WEST.8; also elsewhere on the board
S_SPI_V: X-WEST.10; also elsewhere on the board
S_VE_CV: X-EAST.100; also elsewhere on the board
S_VE_OV: X-EAST.99; also elsewhere on the board
S_VE_RS: X-EAST.84; also elsewhere on the board
S_VE_UV: X-EAST.89; also elsewhere on the board
S_VS_CV: X-EAST.98; also elsewhere on the board
S_VS_OV: X-EAST.97; also elsewhere on the board
S_VS_RS: X-EAST.86; also elsewhere on the board
S_VS_UV: X-EAST.87; also elsewhere on the board
S_VW_CV: X-EAST.96; also elsewhere on the board
S_VW_OV: X-EAST.95; also elsewhere on the board
S_VW_RS: X-EAST.88; also elsewhere on the board
S_VW_UV: X-EAST.85; also elsewhere on the board
TCK: X-WEST.12
TDI: X-WEST.16
TDIG1: X-EAST.18; also elsewhere on the board
TDO: X-WEST.18
TMS: X-WEST.14
T_EXP1: X-EAST.12; also elsewhere on the board
T_EXP2: X-EAST.16; also elsewhere on the board
W_EN: X-WEST.19
W_I2C_EN: X-WEST.13
W_I2C_V: X-WEST.11
W_SCL: X-WEST.15
W_SDA: X-WEST.17
W_VW: C8.1; also elsewhere on the board
W_VW_CV: X-WEST.90
W_VW_OV: X-WEST.93
W_VW_UV: X-WEST.91

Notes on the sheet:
Info EEPROM
AXIOM Beta Dummy Interf.
Copyright (C) 2014-2020 H.Poetzl Licensed under CERN OHL v.1.2
Beta Board Interface
E_SPI_V assumed equal to LVDS

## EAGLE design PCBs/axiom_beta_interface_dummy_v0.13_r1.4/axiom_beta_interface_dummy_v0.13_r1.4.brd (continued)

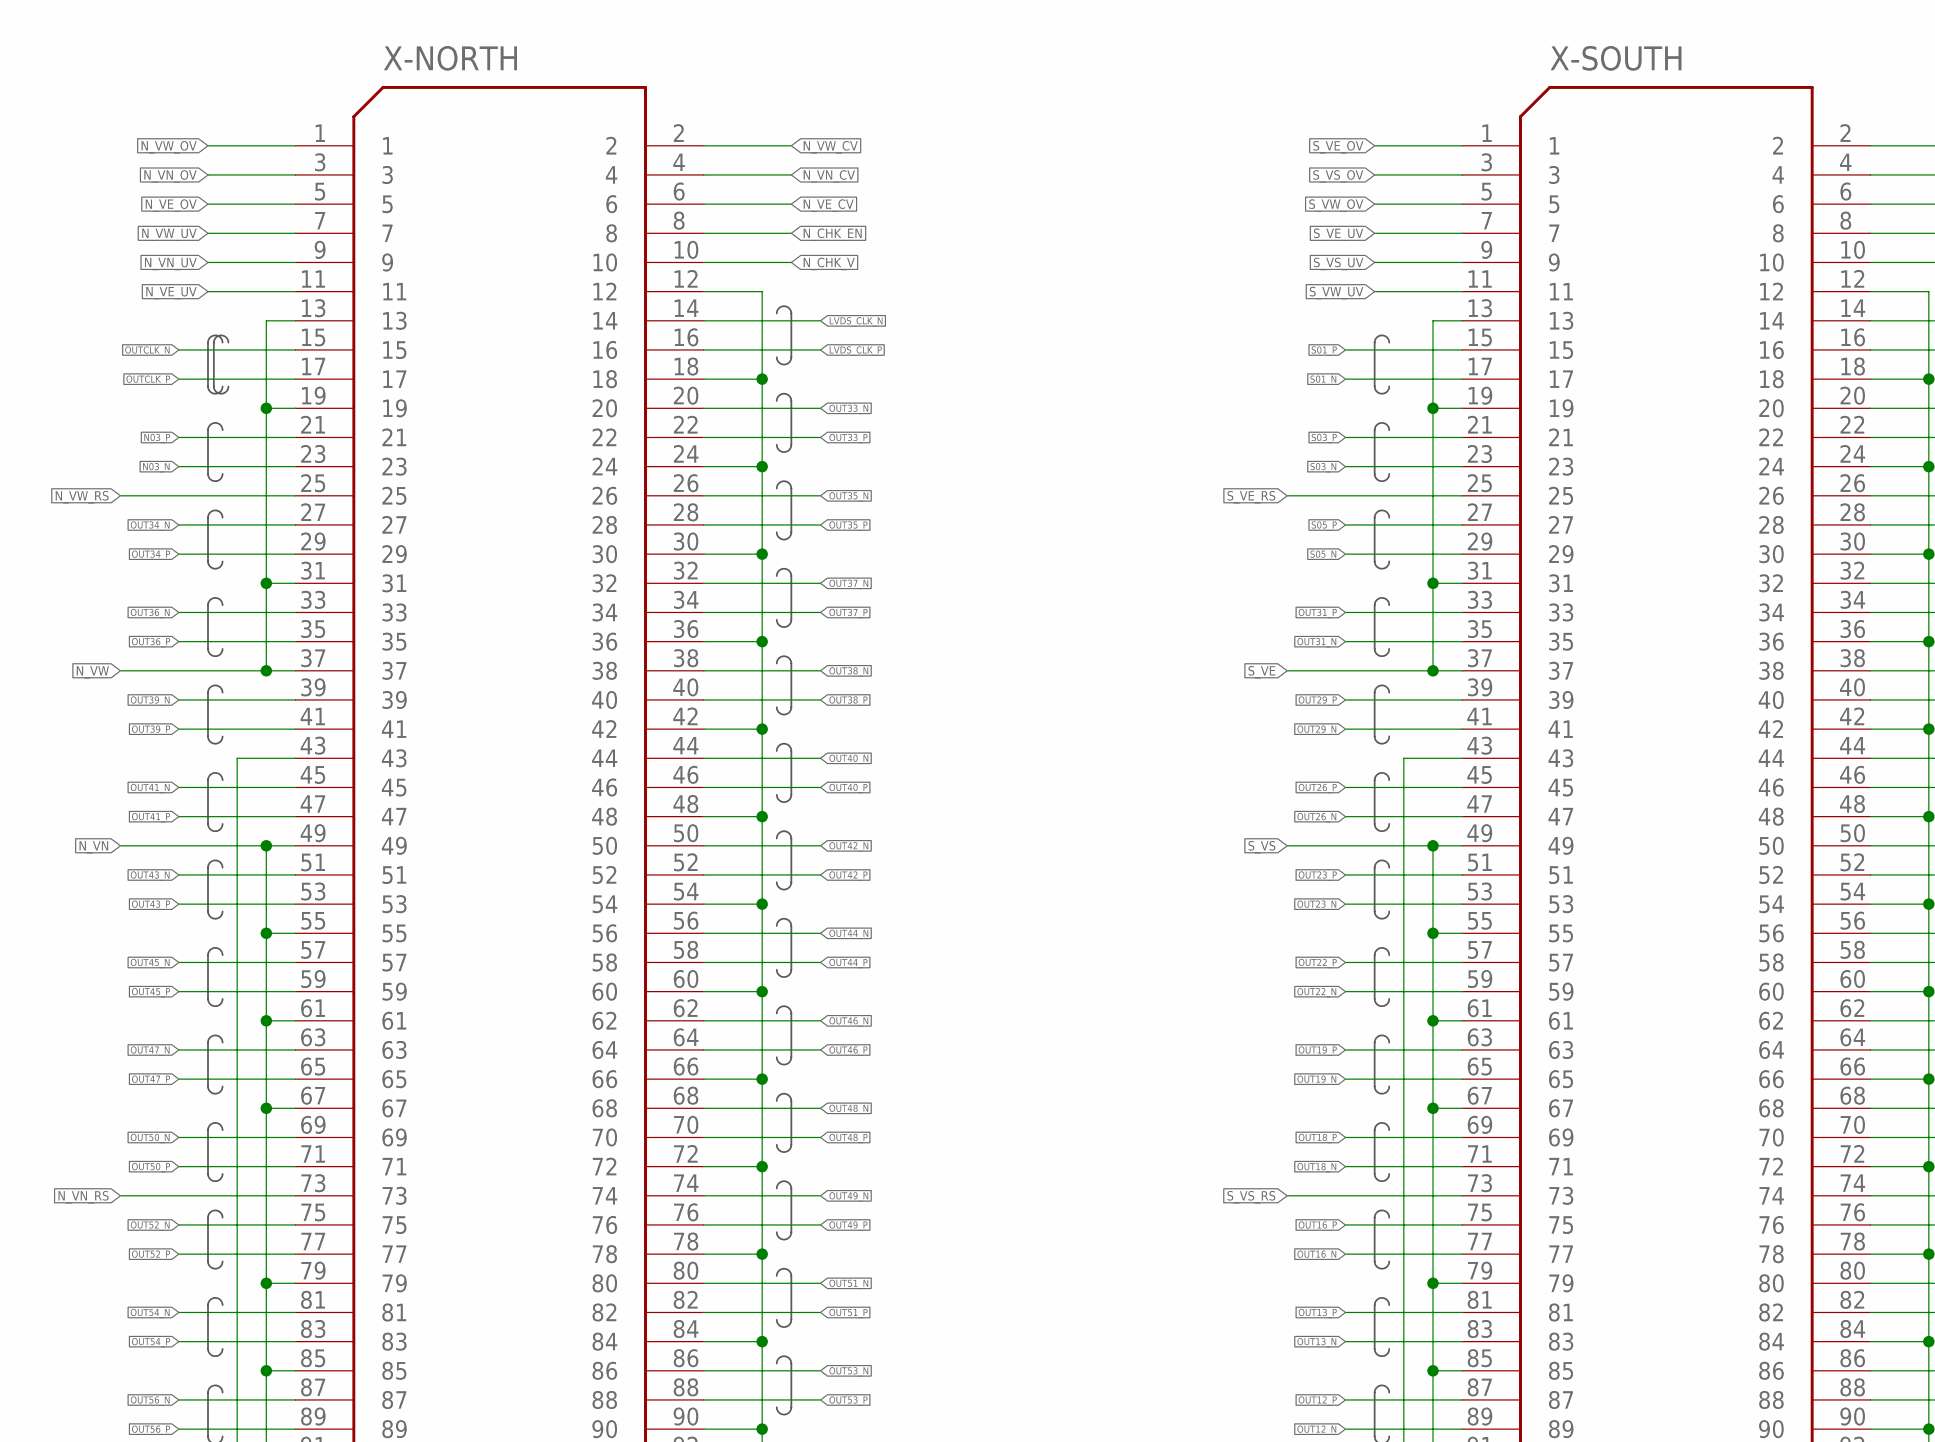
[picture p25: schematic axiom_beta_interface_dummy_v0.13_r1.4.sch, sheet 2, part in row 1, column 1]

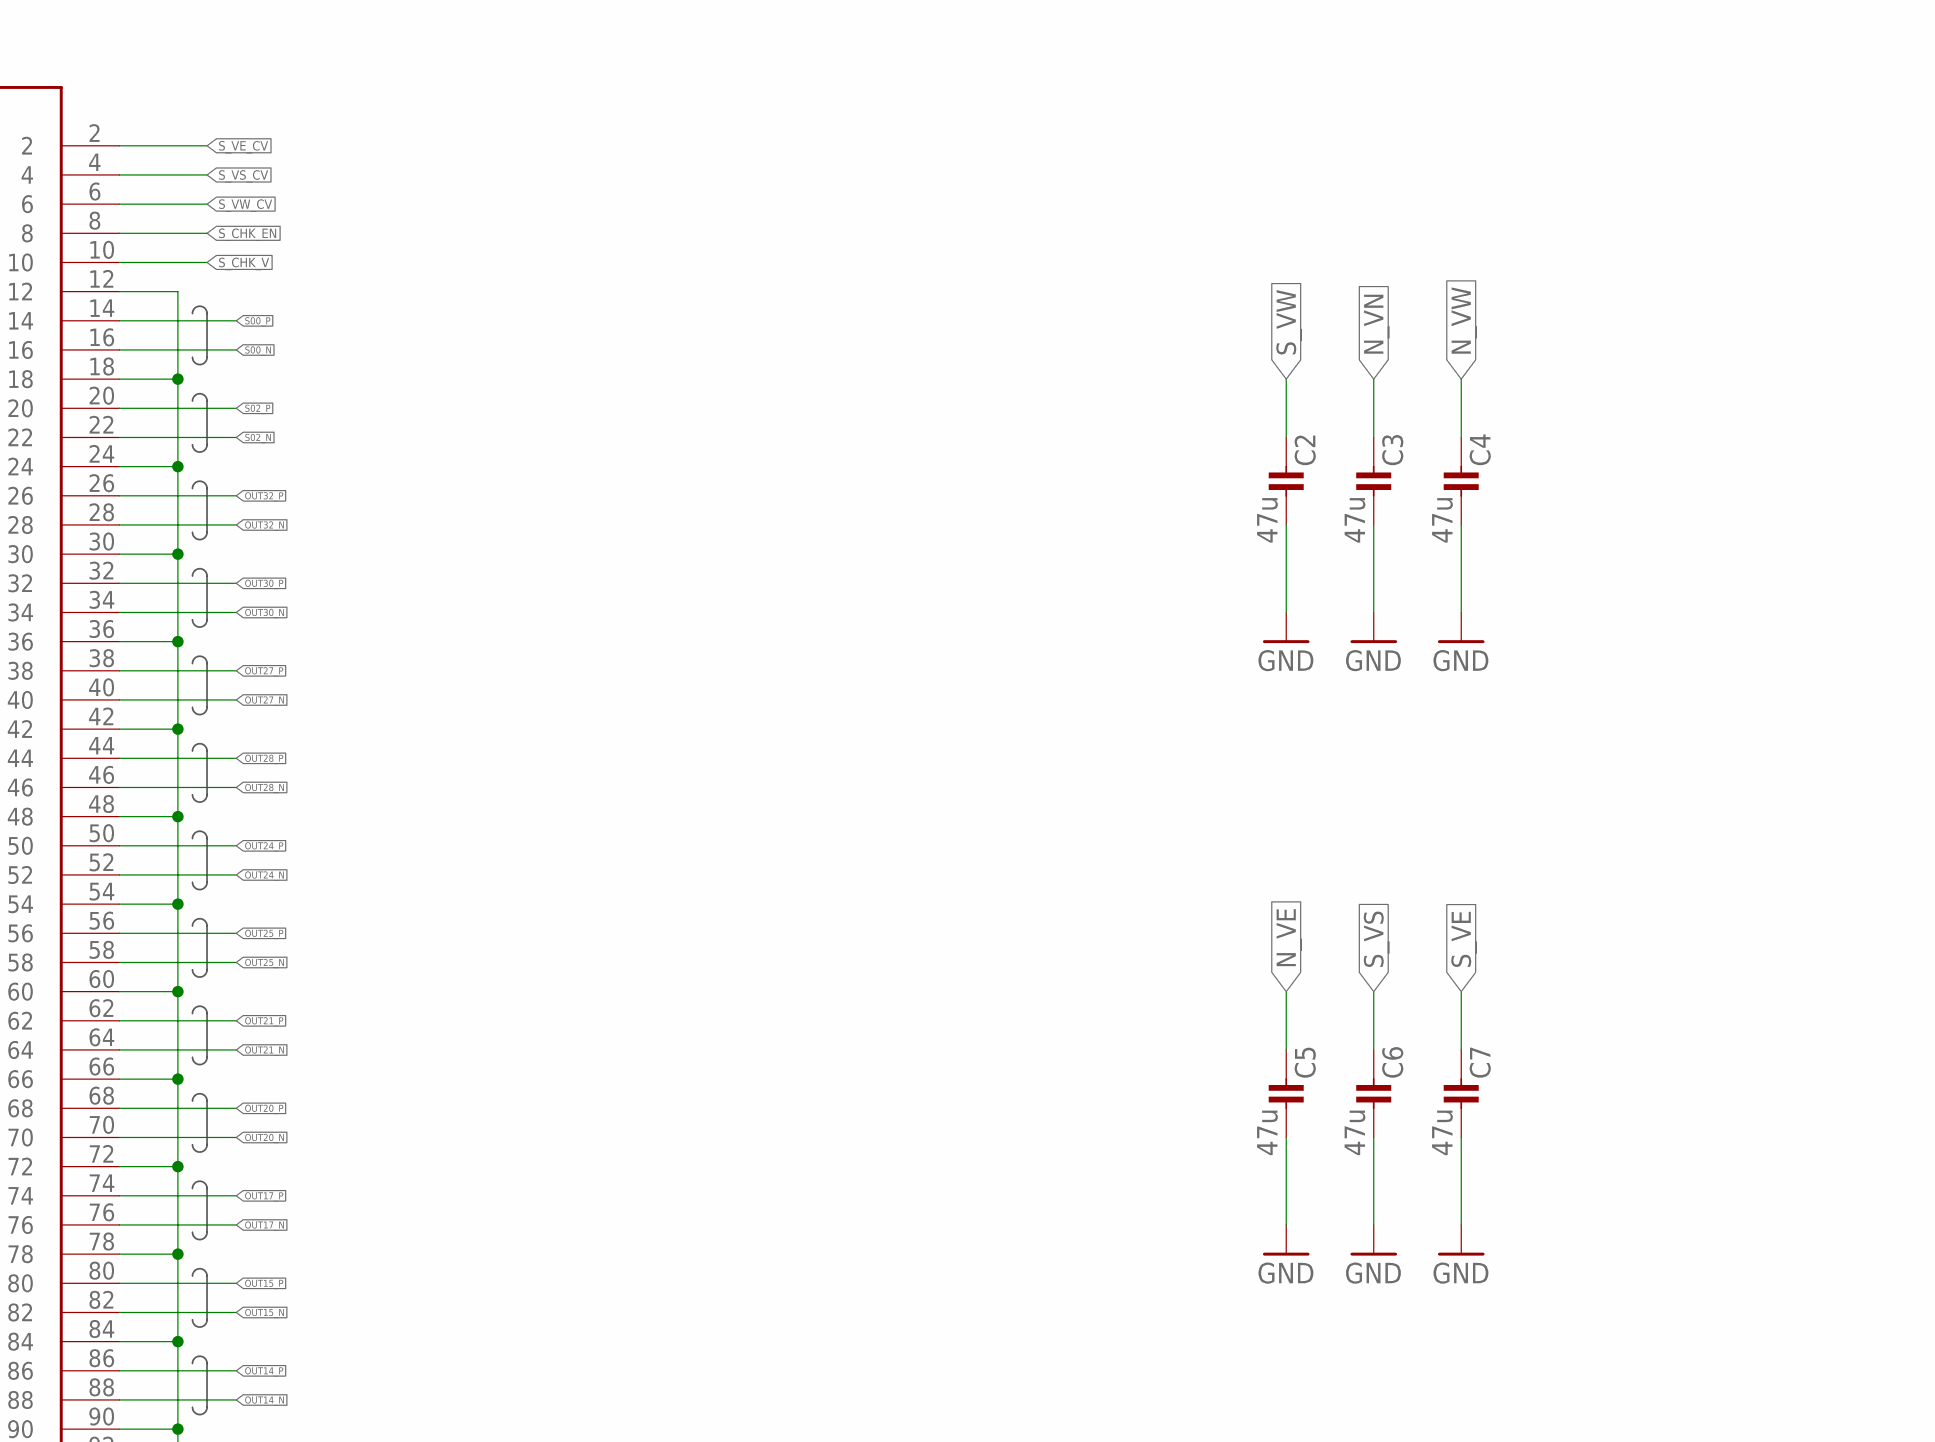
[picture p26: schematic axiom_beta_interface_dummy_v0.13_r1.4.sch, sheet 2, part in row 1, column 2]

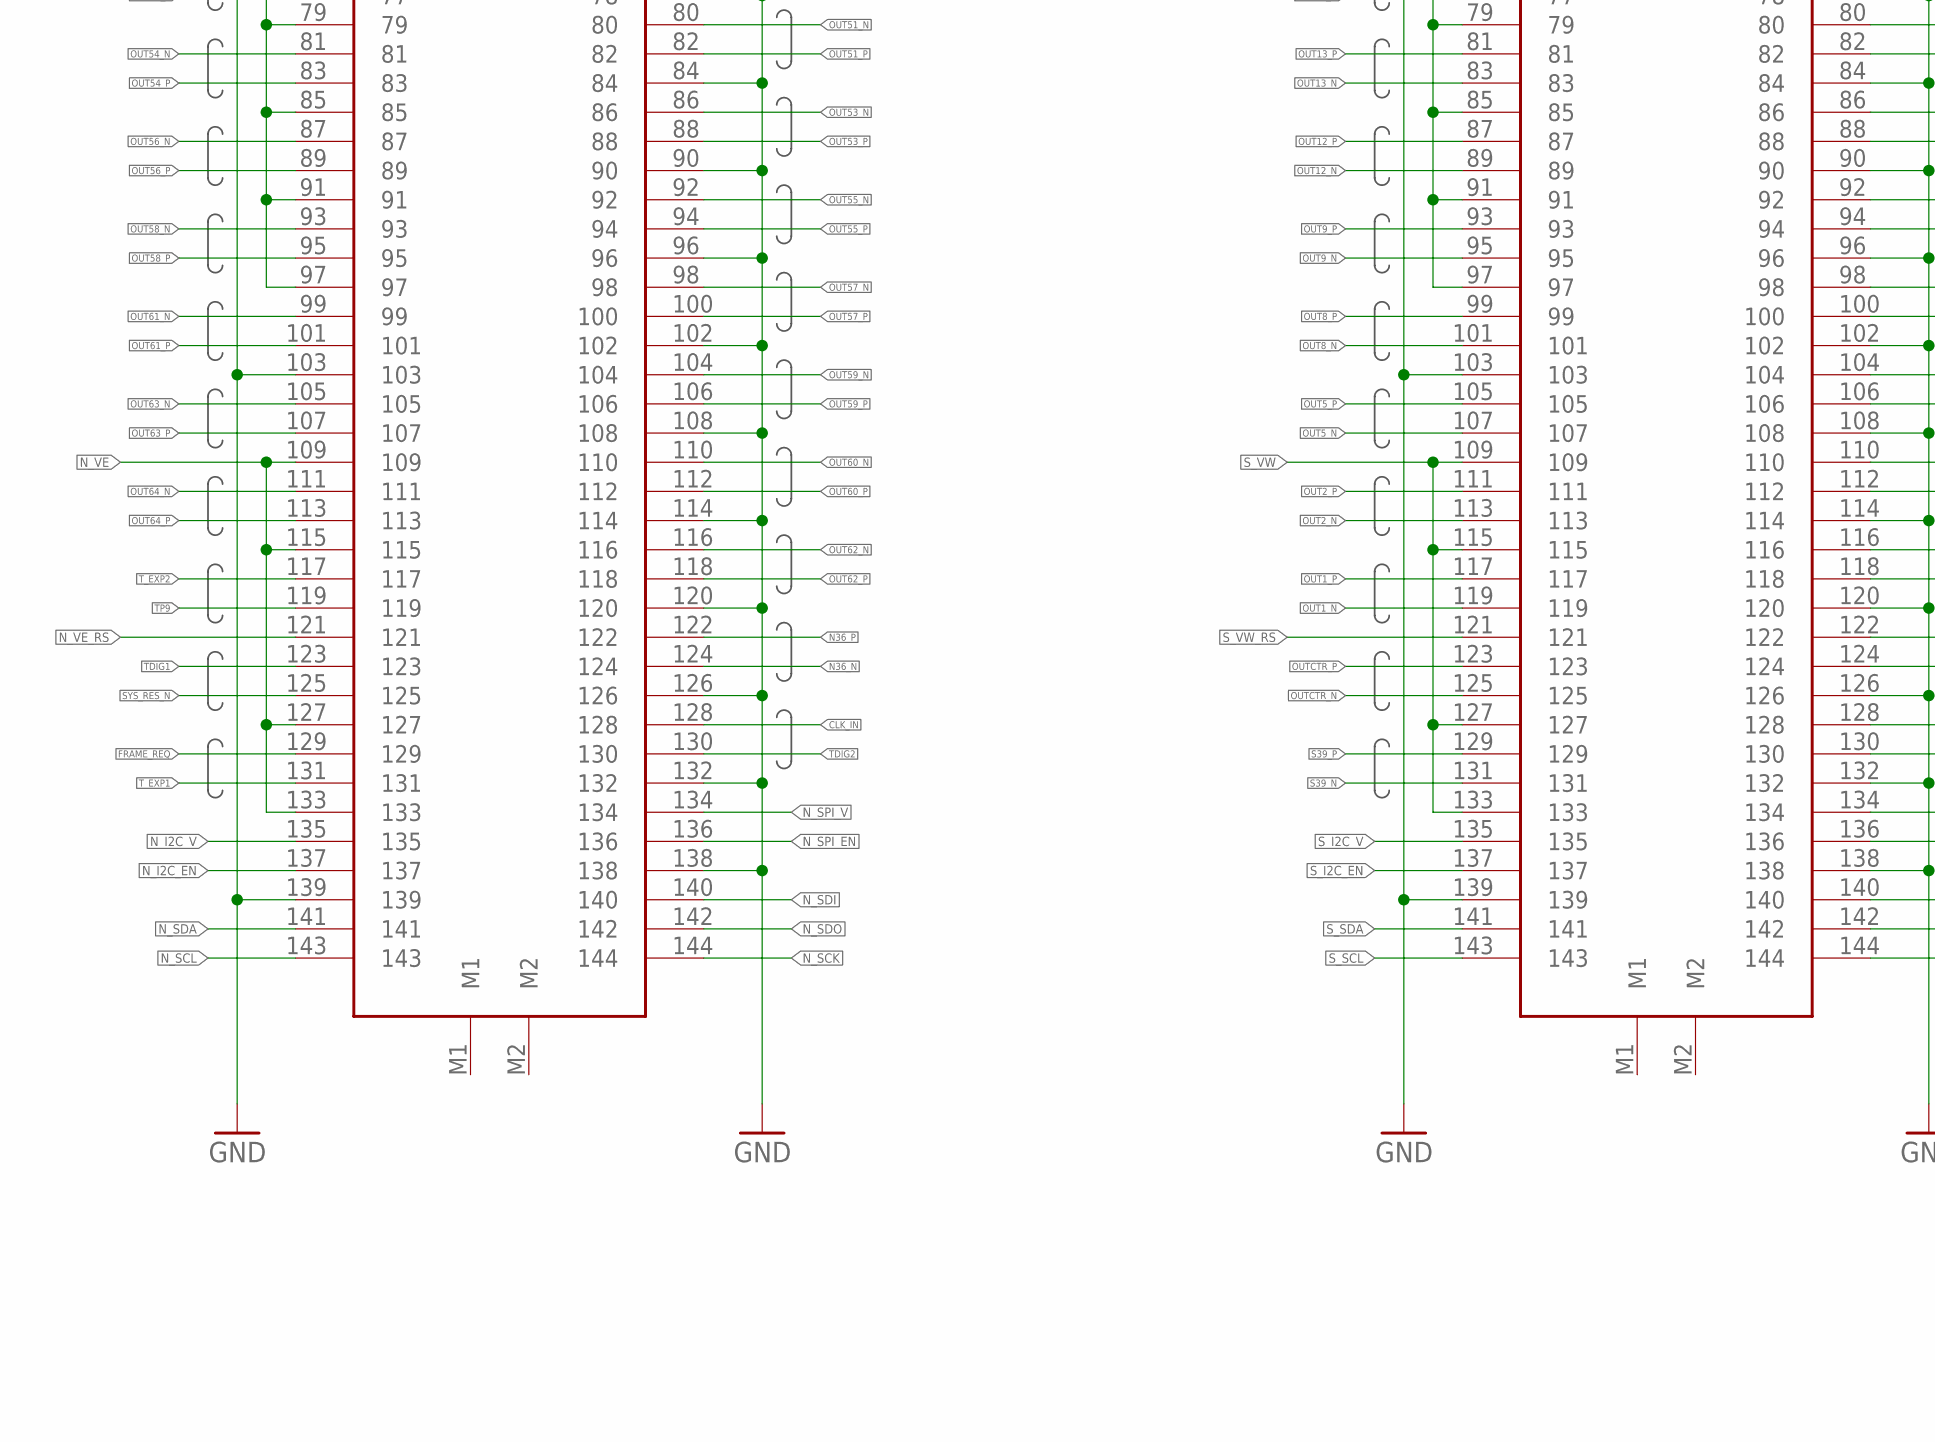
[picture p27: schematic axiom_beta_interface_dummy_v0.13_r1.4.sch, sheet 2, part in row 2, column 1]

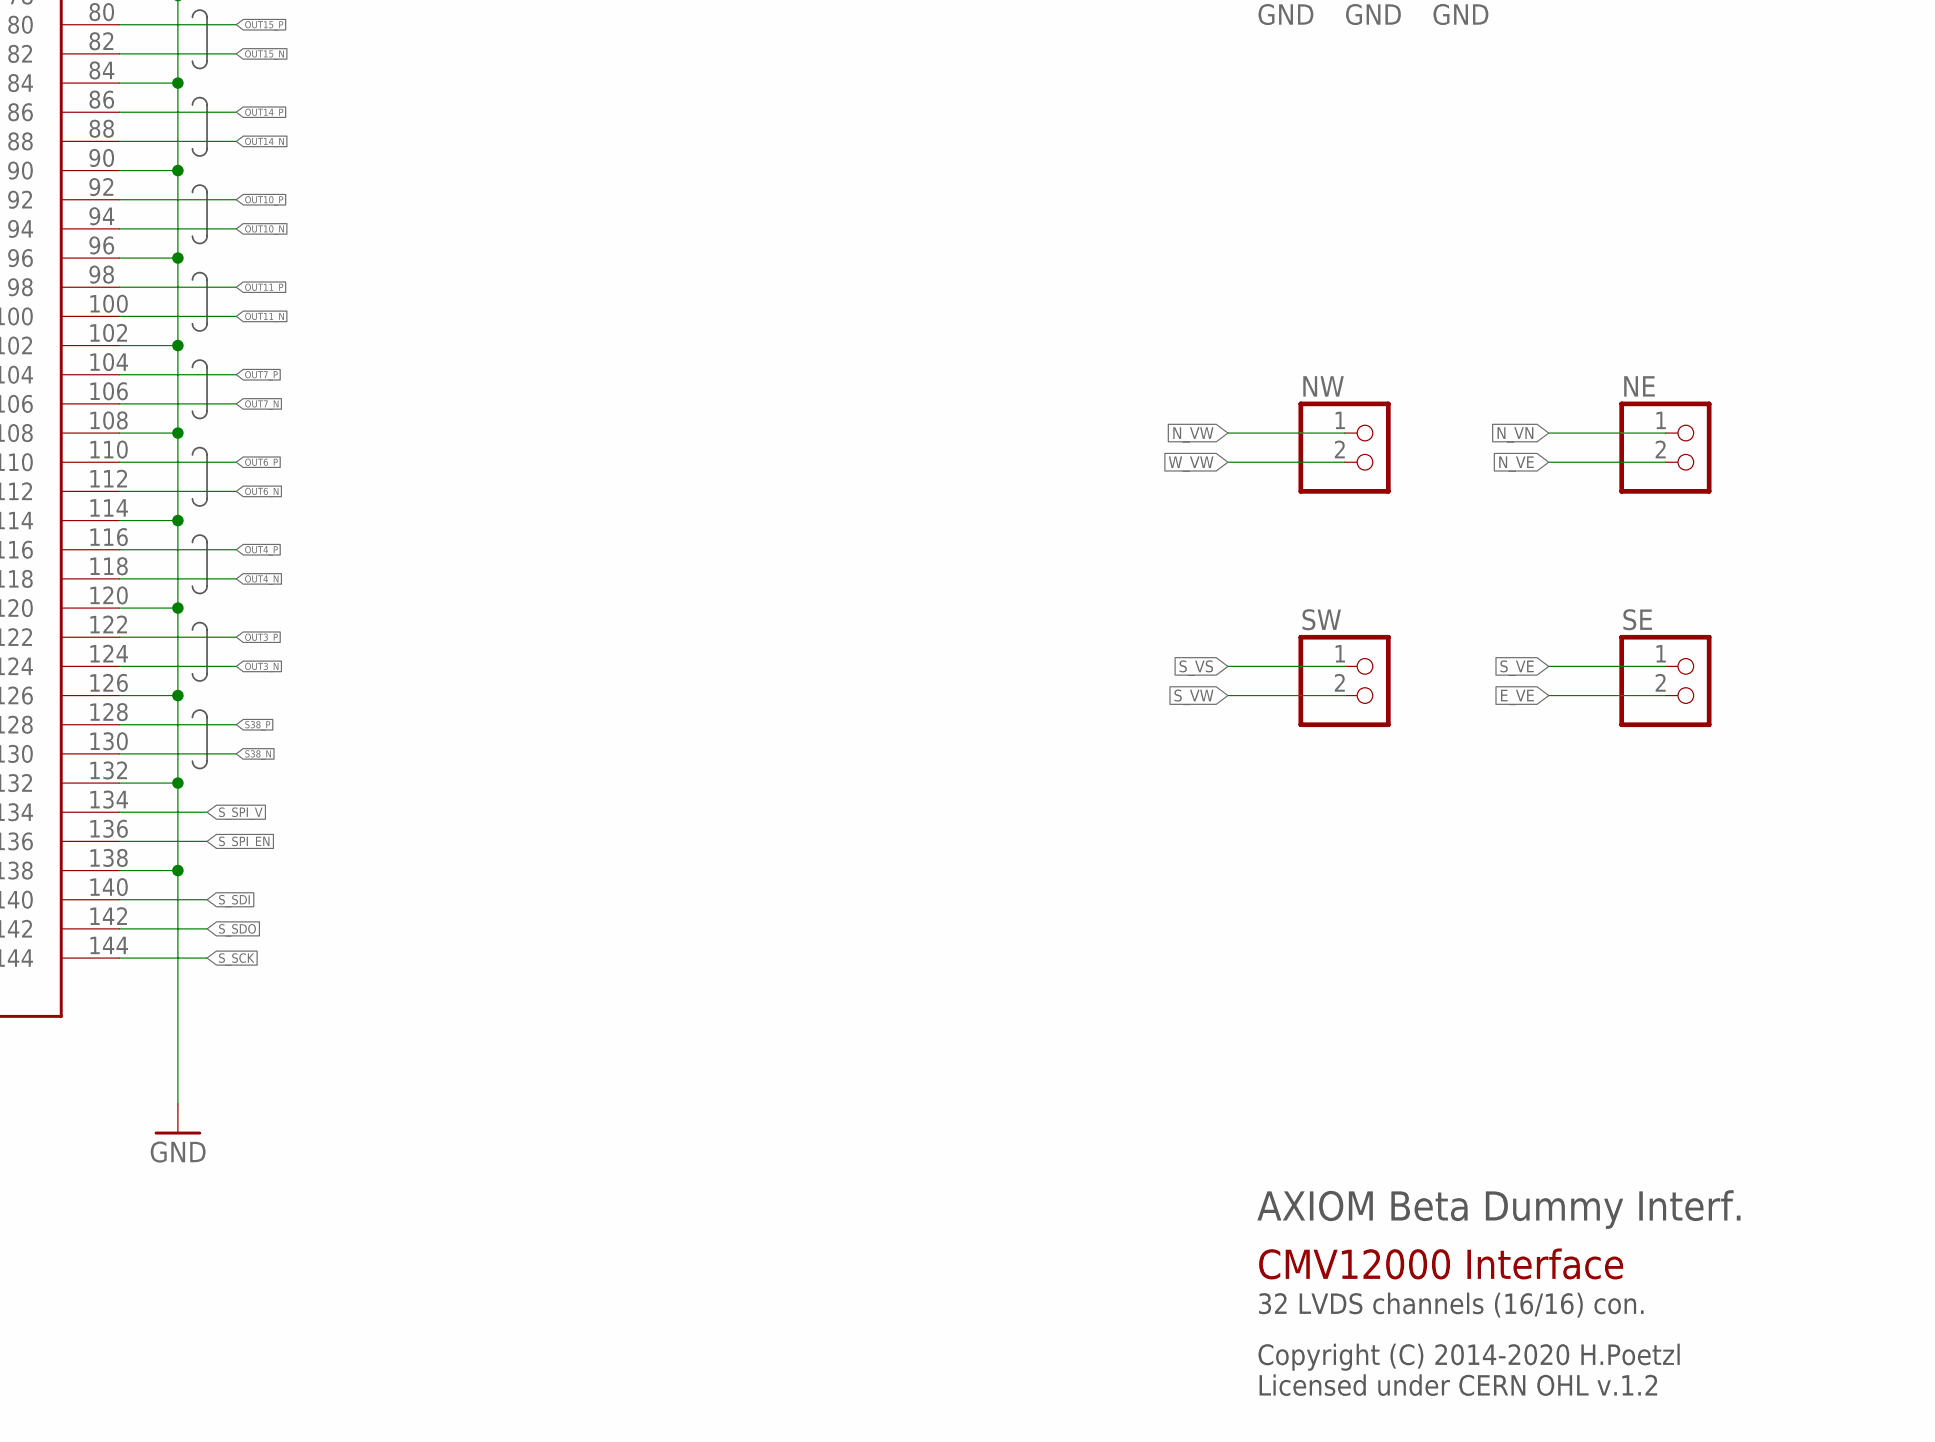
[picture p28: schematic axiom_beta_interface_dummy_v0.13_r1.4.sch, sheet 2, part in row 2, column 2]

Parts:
C2, C3, C4, C5, C6, C7: 47u; 0805-B
NE: PINHD-1X02_2.54; 1X02
NW: PINHD-1X02_2.54; 1X02
SE: PINHD-1X02_2.54; 1X02
SW: PINHD-1X02_2.54; 1X02
X-NORTH: FX10-144S; FX10A-144S
X-SOUTH: FX10-144S; FX10A-144S

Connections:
CLK_IN: X-NORTH.128; also elsewhere on the board
E_VE: SE.2; also elsewhere on the board
FRAME_REQ: X-NORTH.129; also elsewhere on the board
GND: C2.2, C3.2, C4.2, C5.2, C6.2, C7.2, X-NORTH.12, X-NORTH.18, X-NORTH.24, X-NORTH.30, X-NORTH.36, X-NORTH.42, X-NORTH.43, X-NORTH.48, X-NORTH.54, X-NORTH.60, X-NORTH.66, X-NORTH.72, X-NORTH.78, X-NORTH.84, X-NORTH.90, X-NORTH.96, X-NORTH.102, X-NORTH.103, X-NORTH.108, X-NORTH.114, X-NORTH.120, X-NORTH.126, X-NORTH.132, X-NORTH.138, X-NORTH.139, X-SOUTH.12, X-SOUTH.18, X-SOUTH.24, X-SOUTH.30, X-SOUTH.36, X-SOUTH.42, X-SOUTH.43, X-SOUTH.48, X-SOUTH.54, X-SOUTH.60, X-SOUTH.66, X-SOUTH.72, X-SOUTH.78, X-SOUTH.84, X-SOUTH.90, X-SOUTH.96, X-SOUTH.102, X-SOUTH.103, X-SOUTH.108, X-SOUTH.114, X-SOUTH.120, X-SOUTH.126, X-SOUTH.132, X-SOUTH.138, X-SOUTH.139; also elsewhere on the board
LVDS_CLK_N: X-NORTH.14; also elsewhere on the board
LVDS_CLK_P: X-NORTH.16; also elsewhere on the board
N03_N: X-NORTH.23
N03_P: X-NORTH.21
N36_N: X-NORTH.124
N36_P: X-NORTH.122
N_CHK_EN: X-NORTH.8; also elsewhere on the board
N_CHK_V: X-NORTH.10; also elsewhere on the board
N_I2C_EN: X-NORTH.137; also elsewhere on the board
N_I2C_V: X-NORTH.135; also elsewhere on the board
N_SCK: X-NORTH.144; also elsewhere on the board
N_SCL: X-NORTH.143; also elsewhere on the board
N_SDA: X-NORTH.141; also elsewhere on the board
N_SDI: X-NORTH.140; also elsewhere on the board
N_SDO: X-NORTH.142; also elsewhere on the board
N_SPI_EN: X-NORTH.136; also elsewhere on the board
N_SPI_V: X-NORTH.134; also elsewhere on the board
N_VE: C5.1, NE.2, X-NORTH.109, X-NORTH.115, X-NORTH.127, X-NORTH.133
N_VE_CV: X-NORTH.6; also elsewhere on the board
N_VE_OV: X-NORTH.5; also elsewhere on the board
N_VE_RS: X-NORTH.121; also elsewhere on the board
N_VE_UV: X-NORTH.11; also elsewhere on the board
N_VN: C3.1, NE.1, X-NORTH.49, X-NORTH.55, X-NORTH.61, X-NORTH.67, X-NORTH.79, X-NORTH.85, X-NORTH.91, X-NORTH.97
N_VN_CV: X-NORTH.4; also elsewhere on the board
N_VN_OV: X-NORTH.3; also elsewhere on the board
N_VN_RS: X-NORTH.73; also elsewhere on the board
N_VN_UV: X-NORTH.9; also elsewhere on the board
N_VW: C4.1, NW.1, X-NORTH.13, X-NORTH.19, X-NORTH.31, X-NORTH.37
N_VW_CV: X-NORTH.2; also elsewhere on the board
N_VW_OV: X-NORTH.1; also elsewhere on the board
N_VW_RS: X-NORTH.25; also elsewhere on the board
N_VW_UV: X-NORTH.7; also elsewhere on the board
OUT1_N: X-SOUTH.119; also elsewhere on the board
OUT1_P: X-SOUTH.117; also elsewhere on the board
OUT2_N: X-SOUTH.113
OUT2_P: X-SOUTH.111
OUT3_N: X-SOUTH.124; also elsewhere on the board
OUT3_P: X-SOUTH.122; also elsewhere on the board
OUT4_N: X-SOUTH.118
OUT4_P: X-SOUTH.116
OUT5_N: X-SOUTH.107; also elsewhere on the board
OUT5_P: X-SOUTH.105; also elsewhere on the board
OUT6_N: X-SOUTH.112
OUT6_P: X-SOUTH.110
OUT7_N: X-SOUTH.106; also elsewhere on the board
OUT7_P: X-SOUTH.104; also elsewhere on the board
OUT8_N: X-SOUTH.101
OUT8_P: X-SOUTH.99
OUT9_N: X-SOUTH.95; also elsewhere on the board
OUT9_P: X-SOUTH.93; also elsewhere on the board
OUT10_N: X-SOUTH.94
OUT10_P: X-SOUTH.92
OUT11_N: X-SOUTH.100; also elsewhere on the board
OUT11_P: X-SOUTH.98; also elsewhere on the board
OUT12_N: X-SOUTH.89
OUT12_P: X-SOUTH.87
OUT13_N: X-SOUTH.83; also elsewhere on the board
OUT13_P: X-SOUTH.81; also elsewhere on the board
OUT14_N: X-SOUTH.88
OUT14_P: X-SOUTH.86
OUT15_N: X-SOUTH.82; also elsewhere on the board
OUT15_P: X-SOUTH.80; also elsewhere on the board
OUT16_N: X-SOUTH.77
OUT16_P: X-SOUTH.75
OUT17_N: X-SOUTH.76; also elsewhere on the board
OUT17_P: X-SOUTH.74; also elsewhere on the board
OUT18_N: X-SOUTH.71
OUT18_P: X-SOUTH.69
OUT19_N: X-SOUTH.65; also elsewhere on the board
OUT19_P: X-SOUTH.63; also elsewhere on the board
OUT20_N: X-SOUTH.70
OUT20_P: X-SOUTH.68
OUT21_N: X-SOUTH.64; also elsewhere on the board
OUT21_P: X-SOUTH.62; also elsewhere on the board
OUT22_N: X-SOUTH.59
OUT22_P: X-SOUTH.57
OUT23_N: X-SOUTH.53; also elsewhere on the board
OUT23_P: X-SOUTH.51; also elsewhere on the board
OUT24_N: X-SOUTH.52
OUT24_P: X-SOUTH.50
OUT25_N: X-SOUTH.58; also elsewhere on the board
OUT25_P: X-SOUTH.56; also elsewhere on the board
OUT26_N: X-SOUTH.47
OUT26_P: X-SOUTH.45
OUT27_N: X-SOUTH.40; also elsewhere on the board
OUT27_P: X-SOUTH.38; also elsewhere on the board
OUT28_N: X-SOUTH.46
OUT28_P: X-SOUTH.44
OUT29_N: X-SOUTH.41; also elsewhere on the board
OUT29_P: X-SOUTH.39; also elsewhere on the board
OUT30_N: X-SOUTH.34
OUT30_P: X-SOUTH.32
OUT31_N: X-SOUTH.35; also elsewhere on the board
OUT31_P: X-SOUTH.33; also elsewhere on the board
OUT32_N: X-SOUTH.28
OUT32_P: X-SOUTH.26
OUT33_N: X-NORTH.20; also elsewhere on the board
OUT33_P: X-NORTH.22; also elsewhere on the board
OUT34_N: X-NORTH.27
OUT34_P: X-NORTH.29
OUT35_N: X-NORTH.26; also elsewhere on the board
OUT35_P: X-NORTH.28; also elsewhere on the board
OUT36_N: X-NORTH.33
OUT36_P: X-NORTH.35
OUT37_N: X-NORTH.32; also elsewhere on the board
OUT37_P: X-NORTH.34; also elsewhere on the board
OUT38_N: X-NORTH.38
OUT38_P: X-NORTH.40
OUT39_N: X-NORTH.39; also elsewhere on the board
OUT39_P: X-NORTH.41; also elsewhere on the board
OUT40_N: X-NORTH.44
OUT40_P: X-NORTH.46
OUT41_N: X-NORTH.45; also elsewhere on the board
OUT41_P: X-NORTH.47; also elsewhere on the board
OUT42_N: X-NORTH.50
OUT42_P: X-NORTH.52
OUT43_N: X-NORTH.51; also elsewhere on the board
OUT43_P: X-NORTH.53; also elsewhere on the board
OUT44_N: X-NORTH.56
OUT44_P: X-NORTH.58
OUT45_N: X-NORTH.57; also elsewhere on the board
OUT45_P: X-NORTH.59; also elsewhere on the board
OUT46_N: X-NORTH.62
OUT46_P: X-NORTH.64
OUT47_N: X-NORTH.63; also elsewhere on the board
OUT47_P: X-NORTH.65; also elsewhere on the board
OUT48_N: X-NORTH.68
OUT48_P: X-NORTH.70
OUT49_N: X-NORTH.74; also elsewhere on the board
OUT49_P: X-NORTH.76; also elsewhere on the board
OUT50_N: X-NORTH.69
OUT50_P: X-NORTH.71
OUT51_N: X-NORTH.80; also elsewhere on the board
OUT51_P: X-NORTH.82; also elsewhere on the board
OUT52_N: X-NORTH.75
OUT52_P: X-NORTH.77
OUT53_N: X-NORTH.86; also elsewhere on the board
OUT53_P: X-NORTH.88; also elsewhere on the board
OUT54_N: X-NORTH.81
OUT54_P: X-NORTH.83
OUT55_N: X-NORTH.92; also elsewhere on the board
OUT55_P: X-NORTH.94; also elsewhere on the board
OUT56_N: X-NORTH.87
OUT56_P: X-NORTH.89
OUT57_N: X-NORTH.98; also elsewhere on the board
OUT57_P: X-NORTH.100; also elsewhere on the board
OUT58_N: X-NORTH.93
OUT58_P: X-NORTH.95
OUT59_N: X-NORTH.104; also elsewhere on the board
OUT59_P: X-NORTH.106; also elsewhere on the board
OUT60_N: X-NORTH.110
OUT60_P: X-NORTH.112
OUT61_N: X-NORTH.99; also elsewhere on the board
OUT61_P: X-NORTH.101; also elsewhere on the board
OUT62_N: X-NORTH.116
OUT62_P: X-NORTH.118
OUT63_N: X-NORTH.105; also elsewhere on the board
OUT63_P: X-NORTH.107; also elsewhere on the board
OUT64_N: X-NORTH.111
OUT64_P: X-NORTH.113
OUTCLK_N: X-NORTH.15; also elsewhere on the board
OUTCLK_P: X-NORTH.17; also elsewhere on the board
OUTCTR_N: X-SOUTH.125; also elsewhere on the board
OUTCTR_P: X-SOUTH.123; also elsewhere on the board
S00_N: X-SOUTH.16
S00_P: X-SOUTH.14
S01_N: X-SOUTH.17
S01_P: X-SOUTH.15
S02_N: X-SOUTH.22
S02_P: X-SOUTH.20
S03_N: X-SOUTH.23
S03_P: X-SOUTH.21
S05_N: X-SOUTH.29
S05_P: X-SOUTH.27
S38_N: X-SOUTH.130
S38_P: X-SOUTH.128
S39_N: X-SOUTH.131
S39_P: X-SOUTH.129
SYS_RES_N: X-NORTH.125; also elsewhere on the board
S_CHK_EN: X-SOUTH.8; also elsewhere on the board
S_CHK_V: X-SOUTH.10; also elsewhere on the board
S_I2C_EN: X-SOUTH.137; also elsewhere on the board
S_I2C_V: X-SOUTH.135; also elsewhere on the board
S_SCK: X-SOUTH.144; also elsewhere on the board
S_SCL: X-SOUTH.143; also elsewhere on the board
S_SDA: X-SOUTH.141; also elsewhere on the board
S_SDI: X-SOUTH.140; also elsewhere on the board
S_SDO: X-SOUTH.142; also elsewhere on the board
S_SPI_EN: X-SOUTH.136; also elsewhere on the board
S_SPI_V: X-SOUTH.134; also elsewhere on the board
S_VE: C7.1, SE.1, X-SOUTH.13, X-SOUTH.19, X-SOUTH.31, X-SOUTH.37
S_VE_CV: X-SOUTH.2; also elsewhere on the board
S_VE_OV: X-SOUTH.1; also elsewhere on the board
S_VE_RS: X-SOUTH.25; also elsewhere on the board
S_VE_UV: X-SOUTH.7; also elsewhere on the board
S_VS: C6.1, SW.1, X-SOUTH.49, X-SOUTH.55, X-SOUTH.61, X-SOUTH.67, X-SOUTH.79, X-SOUTH.85, X-SOUTH.91, X-SOUTH.97
S_VS_CV: X-SOUTH.4; also elsewhere on the board
S_VS_OV: X-SOUTH.3; also elsewhere on the board
S_VS_RS: X-SOUTH.73; also elsewhere on the board
S_VS_UV: X-SOUTH.9; also elsewhere on the board
S_VW: C2.1, SW.2, X-SOUTH.109, X-SOUTH.115, X-SOUTH.127, X-SOUTH.133
S_VW_CV: X-SOUTH.6; also elsewhere on the board
S_VW_OV: X-SOUTH.5; also elsewhere on the board
S_VW_RS: X-SOUTH.121; also elsewhere on the board
S_VW_UV: X-SOUTH.11; also elsewhere on the board
TDIG1: X-NORTH.123; also elsewhere on the board
TDIG2: X-NORTH.130
TP9: X-NORTH.119
T_EXP1: X-NORTH.131; also elsewhere on the board
T_EXP2: X-NORTH.117; also elsewhere on the board
W_VW: NW.2; also elsewhere on the board

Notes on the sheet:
AXIOM Beta Dummy Interf.
Copyright (C) 2014-2020 H.Poetzl Licensed under CERN OHL v.1.2
CMV12000 Interface
32 LVDS channels (16/16) con.

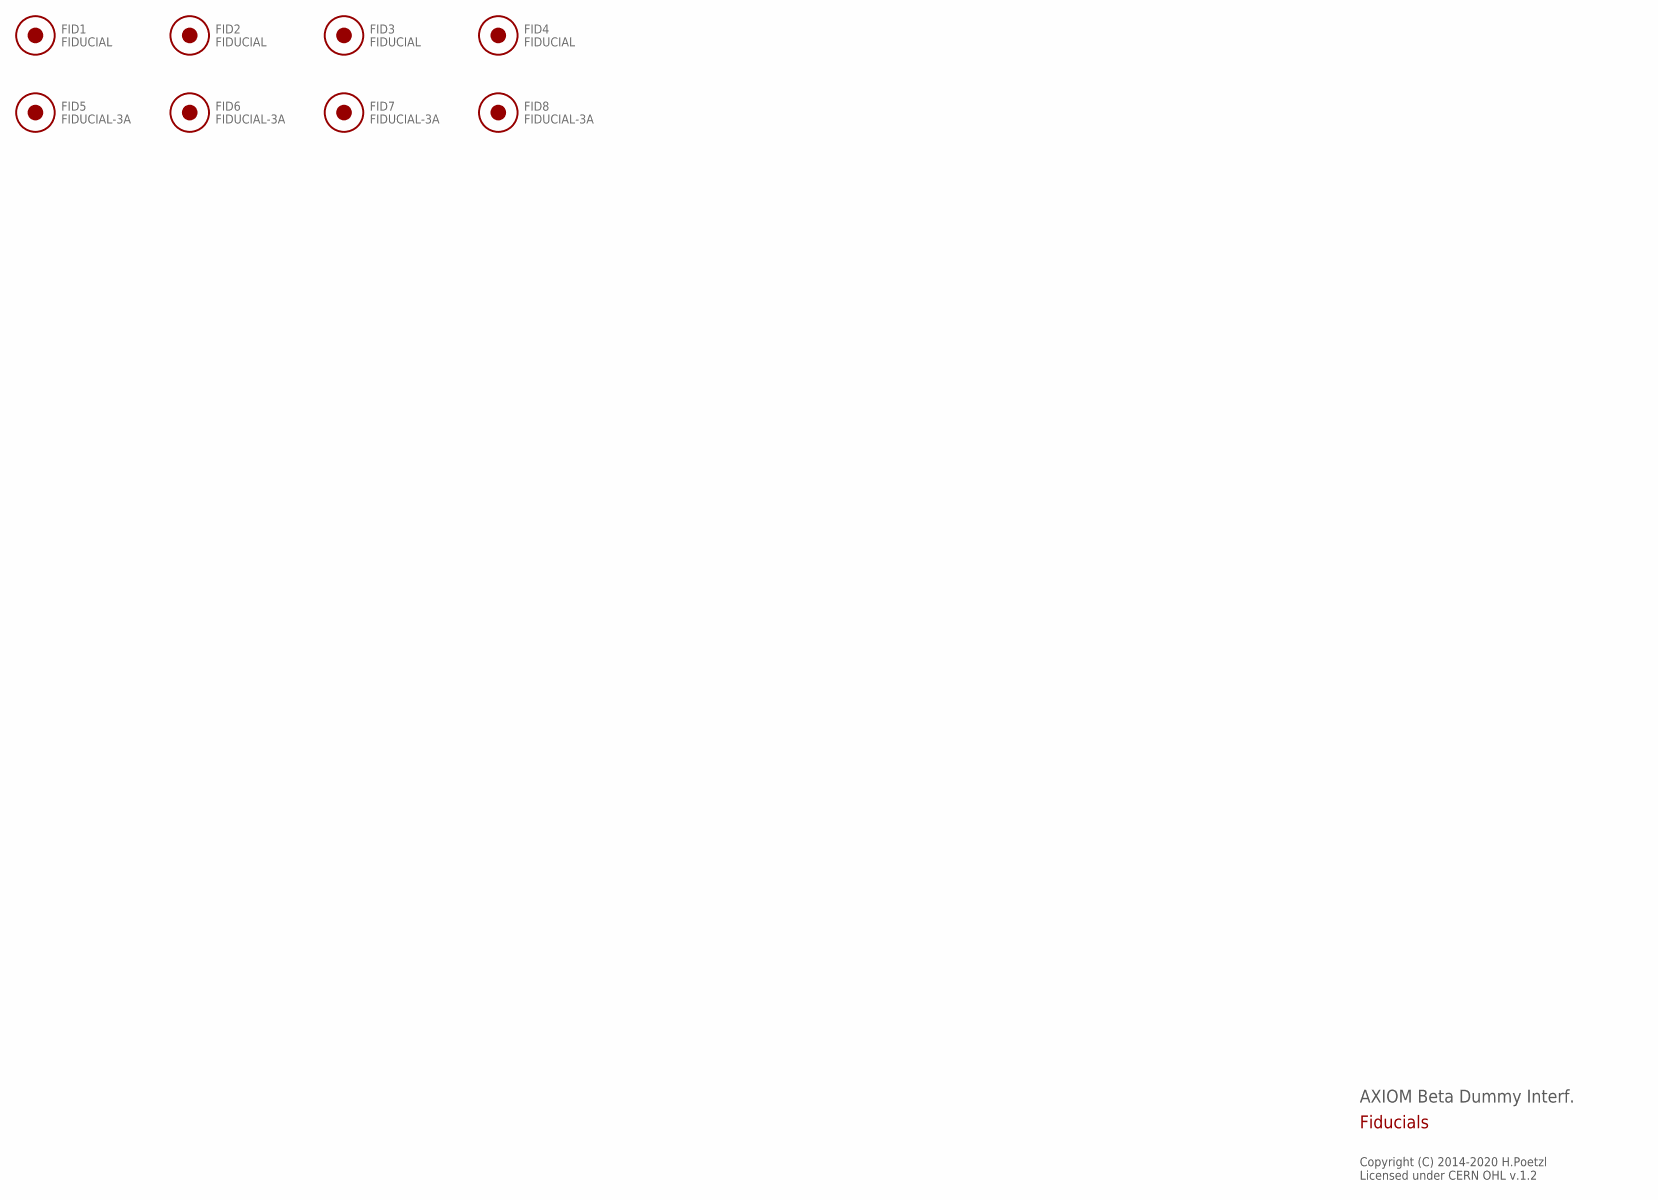
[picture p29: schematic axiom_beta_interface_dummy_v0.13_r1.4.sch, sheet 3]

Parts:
FID1, FID2, FID3, FID4: FIDUCIAL; FID_ARROW
FID5, FID6, FID7, FID8: FIDUCIAL-3A; FID_3ARROW

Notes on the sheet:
AXIOM Beta Dummy Interf.
Copyright (C) 2014-2020 H.Poetzl Licensed under CERN OHL v.1.2
Fiducials

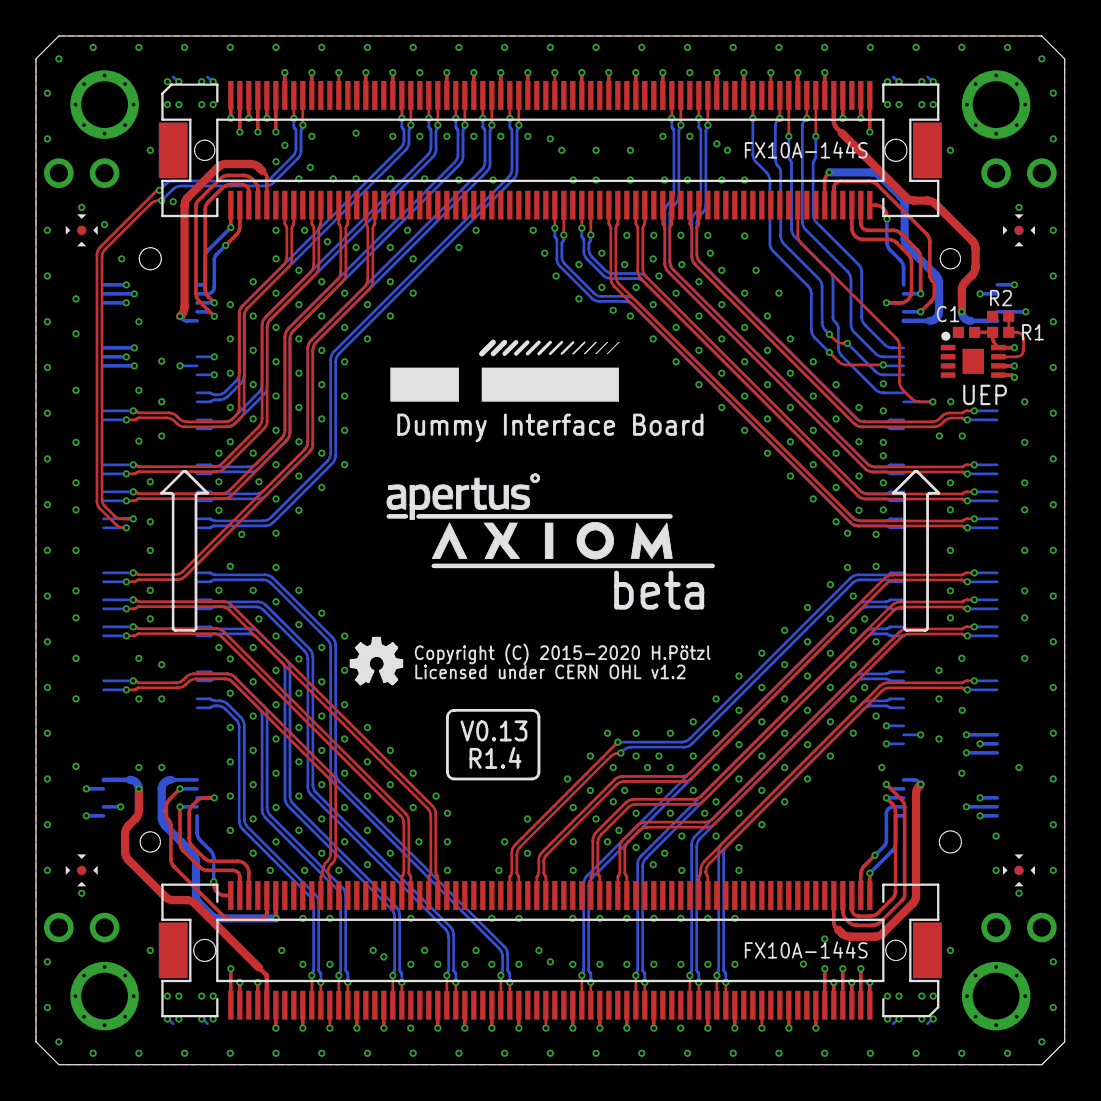
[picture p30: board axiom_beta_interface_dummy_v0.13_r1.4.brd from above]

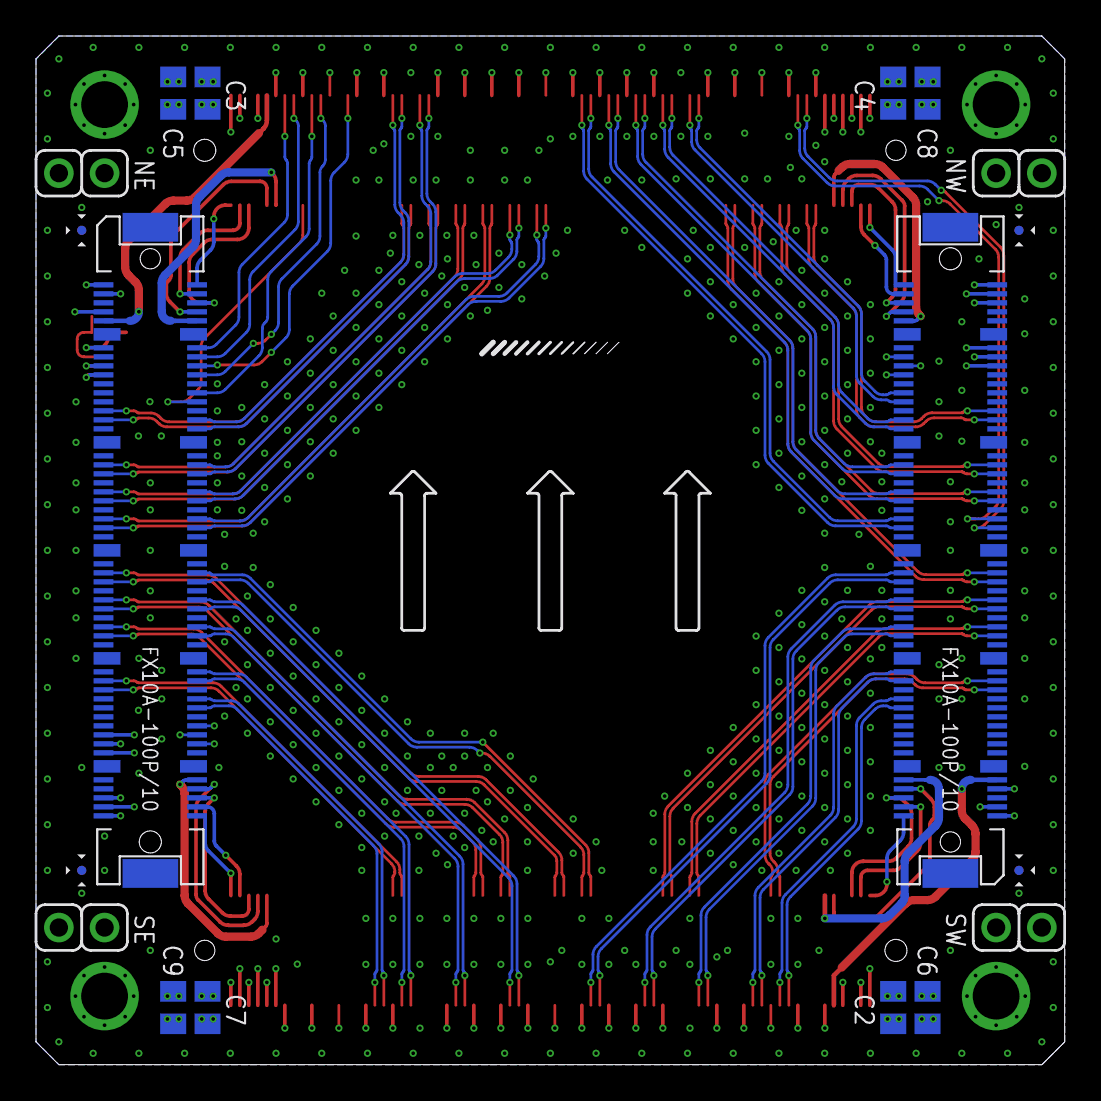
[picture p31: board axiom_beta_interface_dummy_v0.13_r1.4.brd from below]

Board: 4 copper layers, 57.1 x 57.1 mm, 33 parts (18 on the bottom side), 135 nets.

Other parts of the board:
LOGO1: OSHW_LOGO_FILLX0100-NT; OSHW_FILLX100_NOTEXT
PARALLELLA: PARALLELLA-FRAME
U$1: µZ-FRAME
U$2: APERTUS_LOGO334X100; APERTUS_LOGO_334X100
U$3: AXIOM_LOGO525X80; AXIOM_LOGO_525X80

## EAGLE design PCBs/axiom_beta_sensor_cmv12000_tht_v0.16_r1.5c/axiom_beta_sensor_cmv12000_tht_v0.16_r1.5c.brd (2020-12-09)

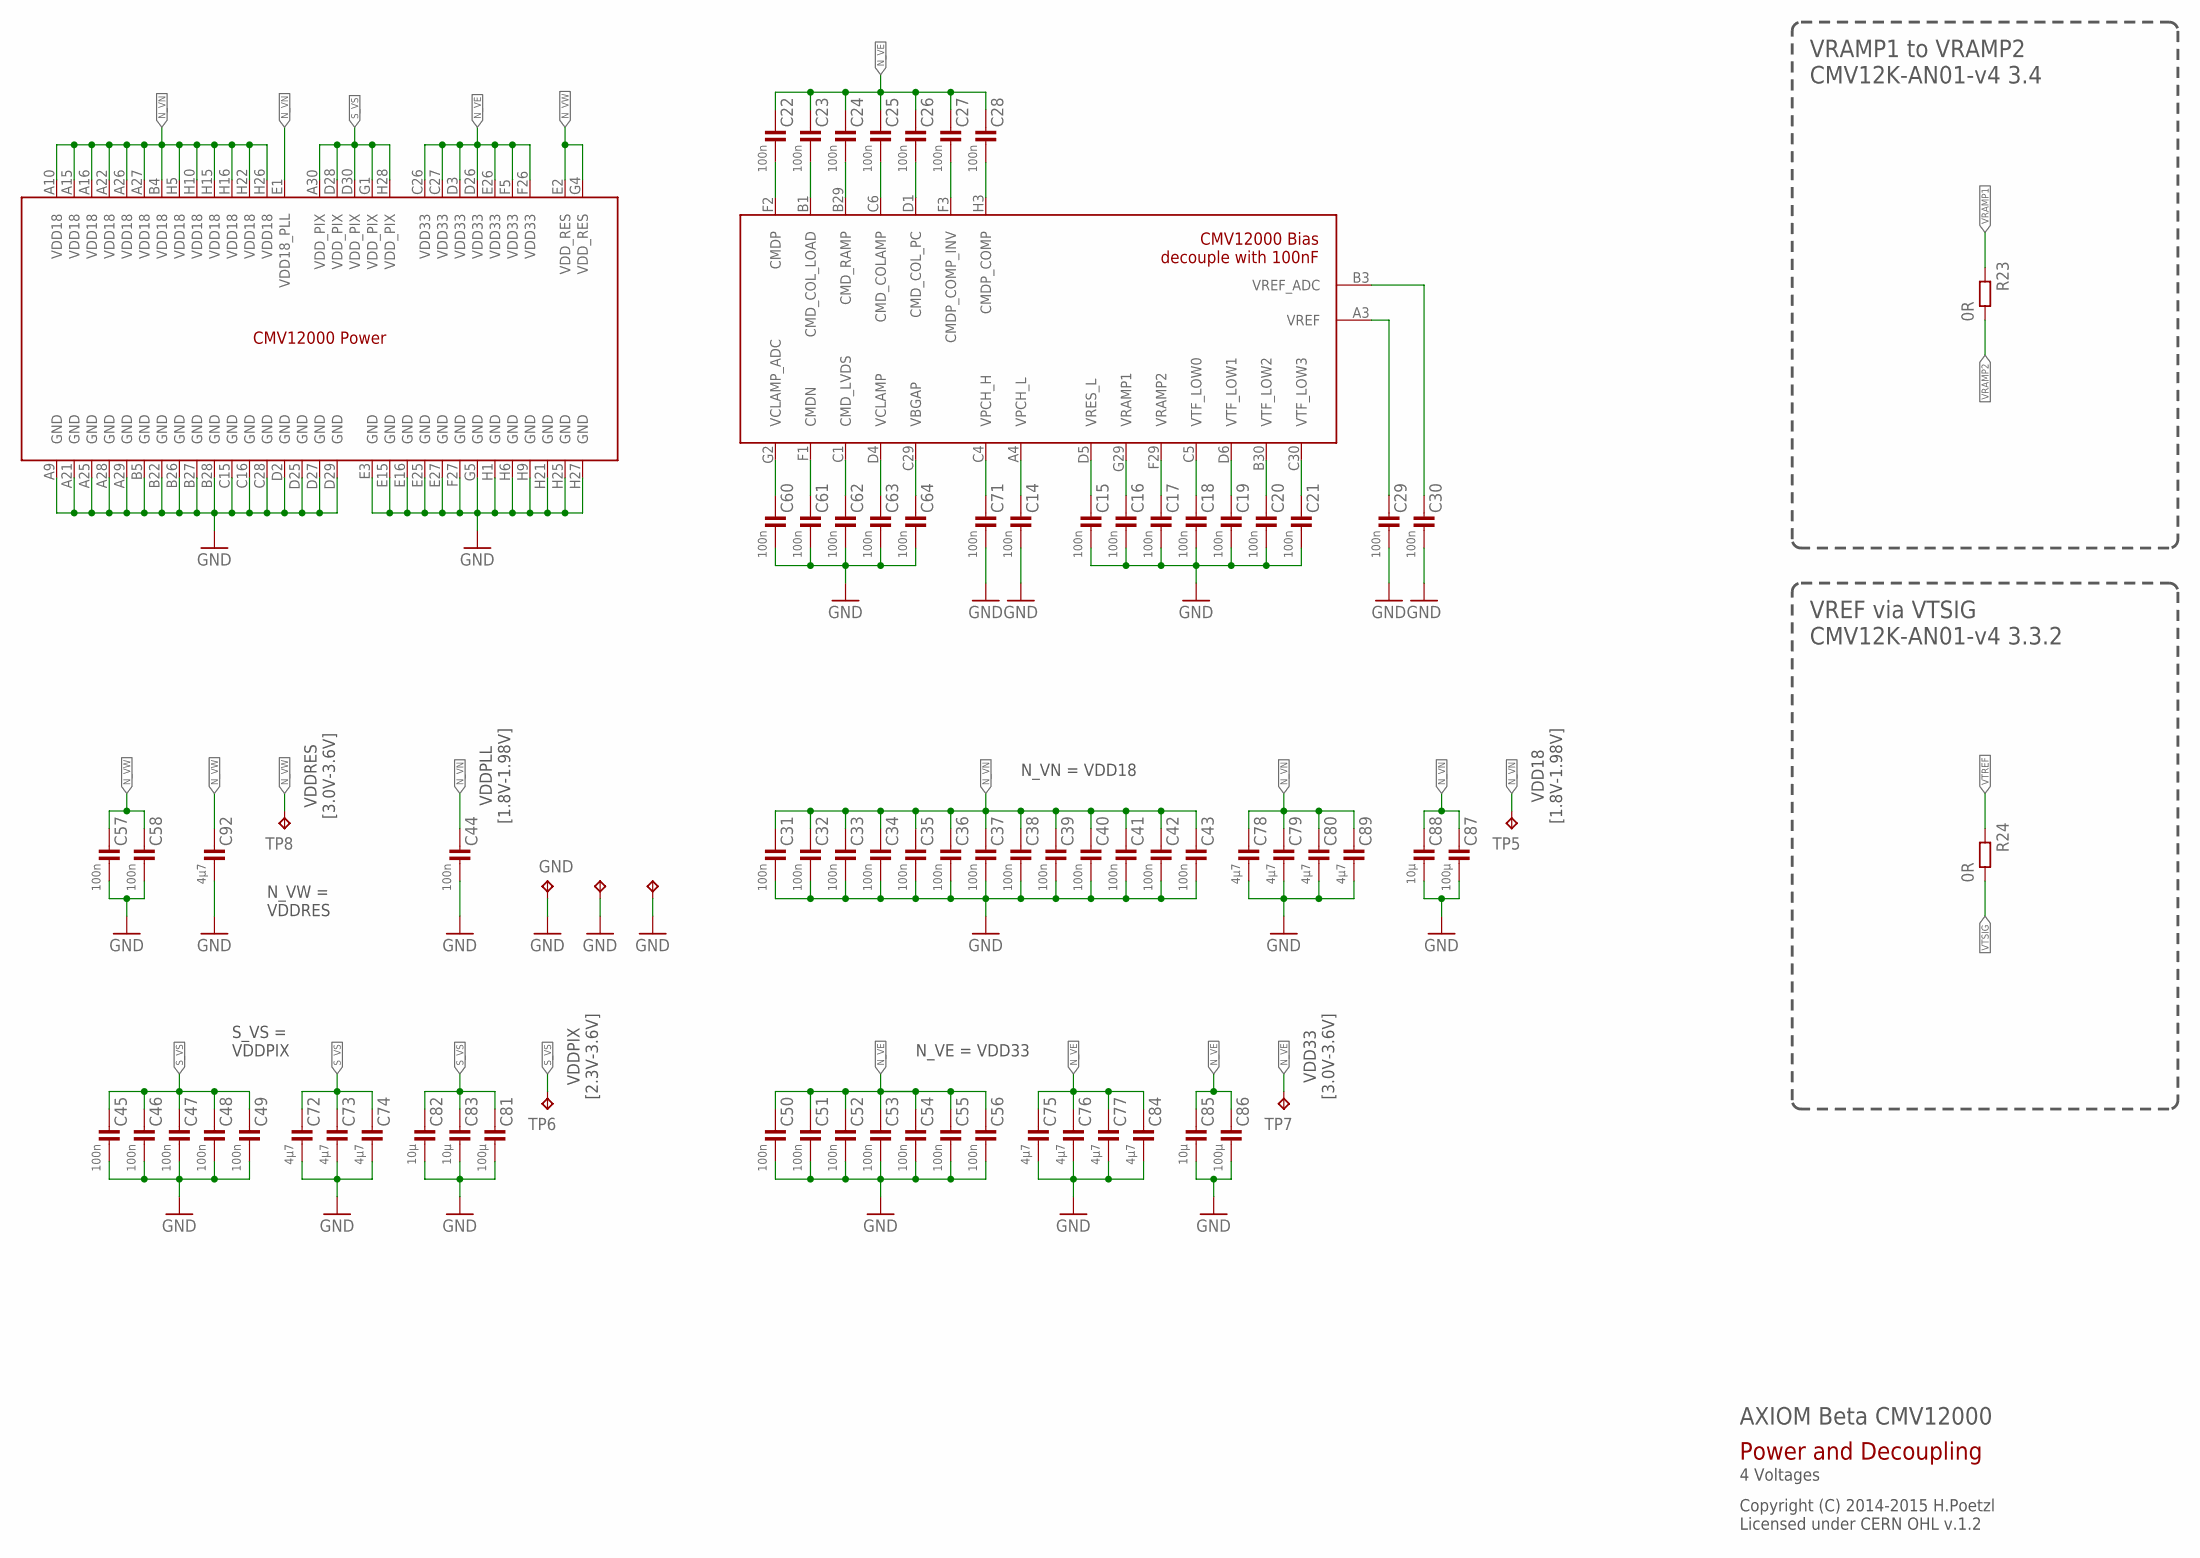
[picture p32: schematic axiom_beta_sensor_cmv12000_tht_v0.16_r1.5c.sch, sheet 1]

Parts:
C14, C15, C16, C17, C18, C19, C20, C21, C22, C23, C24, C25, C26, C27, C28, C29, C30, C31, C32, C33, C34, C35, C36, C37, C38, C39, C40, C41, C42, C43, C44, C45, C46, C47, C48, C49, C50, C51, C52, C53, C54, C55, C56, C57, C58, C60, C61, C62, C63, C64, C71: 100n; 0402-C
C72, C77, C78: 4µ7; 0402-B
C73, C74, C75, C76, C79, C80, C84, C89, C92: 4µ7; 0402-C
C81, C86, C87: 100µ; 1206-B
C82, C83, C85, C88: 10µ; 0603-C
GND, GND75, GND77: TPTP10R; TP10R
R23, R24: 0R; 0402-C
SENSOR: CMV12000ANDON; 10-30-07-237-400T4
TP5, TP6, TP7, TP8: TPTP10R; TP10R

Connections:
GND: C14.2, C15.2, C16.2, C17.2, C18.2, C19.2, C20.2, C21.2, C29.2, C30.2, C31.2, C32.2, C33.2, C34.2, C35.2, C36.2, C37.2, C38.2, C39.2, C40.2, C41.2, C42.2, C43.2, C44.2, C45.2, C46.2, C47.2, C48.2, C49.2, C50.2, C51.2, C52.2, C53.2, C54.2, C55.2, C56.2, C57.2, C58.2, C60.2, C61.2, C62.2, C63.2, C64.2, C71.2, C72.2, C73.2, C74.2, C75.2, C76.2, C77.2, C78.2, C79.2, C80.2, C81.2, C82.2, C83.2, C84.2, C85.2, C86.2, C87.2, C88.2, C89.2, C92.2, GND.TP, GND75.TP, GND77.TP, SENSOR.A9 (GND), SENSOR.A21 (GND), SENSOR.A25 (GND), SENSOR.A28 (GND), SENSOR.A29 (GND), SENSOR.B5 (GND), SENSOR.B22 (GND), SENSOR.B26 (GND), SENSOR.B27 (GND), SENSOR.B28 (GND), SENSOR.C15 (GND), SENSOR.C16 (GND), SENSOR.C28 (GND), SENSOR.D2 (GND), SENSOR.D25 (GND), SENSOR.D27 (GND), SENSOR.D29 (GND), SENSOR.E3 (GND), SENSOR.E15 (GND), SENSOR.E16 (GND), SENSOR.E25 (GND), SENSOR.E27 (GND), SENSOR.F27 (GND), SENSOR.G5 (GND), SENSOR.H1 (GND), SENSOR.H6 (GND), SENSOR.H9 (GND), SENSOR.H21 (GND), SENSOR.H25 (GND), SENSOR.H27 (GND); also elsewhere on the board
unnamed: C60.1, SENSOR.G2 (VCLAMP_ADC)
unnamed: C61.1, SENSOR.F1 (CMDN)
unnamed: C62.1, SENSOR.C1 (CMD_LVDS)
unnamed: C63.1, SENSOR.D4 (VCLAMP)
unnamed: C64.1, SENSOR.C29 (VBGAP)
unnamed: C71.1, SENSOR.C4 (VPCH_H)
unnamed: C14.1, SENSOR.A4 (VPCH_L)
unnamed: C15.1, SENSOR.D5 (VRES_L)
unnamed: C18.1, SENSOR.C5 (VTF_LOW0)
unnamed: C19.1, SENSOR.D6 (VTF_LOW1)
unnamed: C20.1, SENSOR.B30 (VTF_LOW2)
unnamed: C21.1, SENSOR.C30 (VTF_LOW3)
unnamed: C22.2, SENSOR.F2 (CMDP)
unnamed: C23.2, SENSOR.B1 (CMD_COL_LOAD)
unnamed: C24.2, SENSOR.B29 (CMD_RAMP)
unnamed: C25.2, SENSOR.C6 (CMD_COLAMP)
unnamed: C26.2, SENSOR.D1 (CMD_COL_PC)
unnamed: C27.2, SENSOR.F3 (CMDP_COMP_INV)
unnamed: C28.2, SENSOR.H3 (CMDP_COMP)
unnamed: C29.1, SENSOR.A3 (VREF)
unnamed: C30.1, SENSOR.B3 (VREF_ADC)
N_VE: C22.1, C23.1, C24.1, C25.1, C26.1, C27.1, C28.1, C50.1, C51.1, C52.1, C53.1, C54.1, C55.1, C56.1, C75.1, C76.1, C77.1, C84.1, C85.1, C86.1, SENSOR.C26 (VDD33), SENSOR.C27 (VDD33), SENSOR.D3 (VDD33), SENSOR.D26 (VDD33), SENSOR.E26 (VDD33), SENSOR.F5 (VDD33), SENSOR.F26 (VDD33), TP7.TP; also elsewhere on the board
N_VN: C31.1, C32.1, C33.1, C34.1, C35.1, C36.1, C37.1, C38.1, C39.1, C40.1, C41.1, C42.1, C43.1, C44.1, C78.1, C79.1, C80.1, C87.1, C88.1, C89.1, SENSOR.A10 (VDD18), SENSOR.A15 (VDD18), SENSOR.A16 (VDD18), SENSOR.A22 (VDD18), SENSOR.A26 (VDD18), SENSOR.A27 (VDD18), SENSOR.B4 (VDD18), SENSOR.E1 (VDD18_PLL), SENSOR.H5 (VDD18), SENSOR.H10 (VDD18), SENSOR.H15 (VDD18), SENSOR.H16 (VDD18), SENSOR.H22 (VDD18), SENSOR.H26 (VDD18), TP5.TP; also elsewhere on the board
N_VW: C57.1, C58.1, C92.1, SENSOR.E2 (VDD_RES), SENSOR.G4 (VDD_RES), TP8.TP; also elsewhere on the board
S_VS: C45.1, C46.1, C47.1, C48.1, C49.1, C72.1, C73.1, C74.1, C81.1, C82.1, C83.1, SENSOR.A30 (VDD_PIX), SENSOR.D28 (VDD_PIX), SENSOR.D30 (VDD_PIX), SENSOR.G1 (VDD_PIX), SENSOR.H28 (VDD_PIX), TP6.TP; also elsewhere on the board
VRAMP1: C16.1, R23.1, SENSOR.G29 (VRAMP1)
VRAMP2: C17.1, R23.2, SENSOR.F29 (VRAMP2)
VTREF: R24.1; also elsewhere on the board
VTSIG: R24.2; also elsewhere on the board

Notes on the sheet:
N_VN = VDD18
N_VE = VDD33
VDDPIX [2.3V-3.6V]
VDDRES [3.0V-3.6V]
VREF via VTSIG CMV12K-AN01-v4 3.3.2
VRAMP1 to VRAMP2 CMV12K-AN01-v4 3.4
AXIOM Beta CMV12000
Copyright (C) 2014-2015 H.Poetzl Licensed under CERN OHL v.1.2
Power and Decoupling
4 Voltages
VDD18 [1.8V-1.98V]
VDD33 [3.0V-3.6V]
VDDPLL [1.8V-1.98V]
S_VS = VDDPIX
N_VW = VDDRES

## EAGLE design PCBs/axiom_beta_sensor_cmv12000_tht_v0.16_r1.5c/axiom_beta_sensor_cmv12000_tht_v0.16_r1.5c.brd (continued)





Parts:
C1: 100n; 0402-C
C90, C91: 4µ7; 0402-C
R1X, R2X: R0402-C; 0402-C
R21: 5k9; 0402-C
R22: 14k3; 0402-C
U3: MIC47050; MLF-6
UEP: BR24G04NUX; DFN200X300X100-9N
X-NORTH: FX10-144P; FX10A-144P
X-SOUTH: FX10-144P; FX10A-144P

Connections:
GND: C1.2, C90.2, C91.1, R2X.2, R22.1, U3.2 (GND), U3.EP, UEP.1 (A0), UEP.2 (A1), UEP.3 (A2), UEP.4 (GND), UEP.EP, X-NORTH.12, X-NORTH.18, X-NORTH.24, X-NORTH.30, X-NORTH.36, X-NORTH.42, X-NORTH.43, X-NORTH.48, X-NORTH.54, X-NORTH.60, X-NORTH.66, X-NORTH.72, X-NORTH.78, X-NORTH.84, X-NORTH.90, X-NORTH.96, X-NORTH.102, X-NORTH.103, X-NORTH.108, X-NORTH.114, X-NORTH.120, X-NORTH.126, X-NORTH.132, X-NORTH.138, X-NORTH.139, X-SOUTH.12, X-SOUTH.18, X-SOUTH.24, X-SOUTH.30, X-SOUTH.36, X-SOUTH.42, X-SOUTH.43, X-SOUTH.48, X-SOUTH.54, X-SOUTH.60, X-SOUTH.66, X-SOUTH.72, X-SOUTH.78, X-SOUTH.84, X-SOUTH.90, X-SOUTH.96, X-SOUTH.102, X-SOUTH.103, X-SOUTH.108, X-SOUTH.114, X-SOUTH.120, X-SOUTH.126, X-SOUTH.132, X-SOUTH.138, X-SOUTH.139; also elsewhere on the board
N00_N: X-NORTH.16; also elsewhere on the board
N00_P: X-NORTH.14; also elsewhere on the board
N01_N: X-NORTH.17; also elsewhere on the board
N01_P: X-NORTH.15; also elsewhere on the board
N02_N: X-NORTH.22; also elsewhere on the board
N02_P: X-NORTH.20; also elsewhere on the board
N03_N: X-NORTH.23
N03_P: X-NORTH.21
N04_N: X-NORTH.28; also elsewhere on the board
N04_P: X-NORTH.26; also elsewhere on the board
N05_N: X-NORTH.29; also elsewhere on the board
N05_P: X-NORTH.27; also elsewhere on the board
N06_N: X-NORTH.34; also elsewhere on the board
N06_P: X-NORTH.32; also elsewhere on the board
N07_N: X-NORTH.35; also elsewhere on the board
N07_P: X-NORTH.33; also elsewhere on the board
N08_N: X-NORTH.40; also elsewhere on the board
N08_P: X-NORTH.38; also elsewhere on the board
N09_N: X-NORTH.41; also elsewhere on the board
N09_P: X-NORTH.39; also elsewhere on the board
N10_N: X-NORTH.46; also elsewhere on the board
N10_P: X-NORTH.44; also elsewhere on the board
N11_N: X-NORTH.47; also elsewhere on the board
N11_P: X-NORTH.45; also elsewhere on the board
N12_N: X-NORTH.52; also elsewhere on the board
N12_P: X-NORTH.50; also elsewhere on the board
N13_N: X-NORTH.53; also elsewhere on the board
N13_P: X-NORTH.51; also elsewhere on the board
N14_N: X-NORTH.58; also elsewhere on the board
N14_P: X-NORTH.56; also elsewhere on the board
N15_N: X-NORTH.59; also elsewhere on the board
N15_P: X-NORTH.57; also elsewhere on the board
N16_N: X-NORTH.64; also elsewhere on the board
N16_P: X-NORTH.62; also elsewhere on the board
N17_N: X-NORTH.65; also elsewhere on the board
N17_P: X-NORTH.63; also elsewhere on the board
N18_N: X-NORTH.70; also elsewhere on the board
N18_P: X-NORTH.68; also elsewhere on the board
N19_N: X-NORTH.71; also elsewhere on the board
N19_P: X-NORTH.69; also elsewhere on the board
N20_N: X-NORTH.76; also elsewhere on the board
N20_P: X-NORTH.74; also elsewhere on the board
N21_N: X-NORTH.77; also elsewhere on the board
N21_P: X-NORTH.75; also elsewhere on the board
N22_N: X-NORTH.82; also elsewhere on the board
N22_P: X-NORTH.80; also elsewhere on the board
N23_N: X-NORTH.83; also elsewhere on the board
N23_P: X-NORTH.81; also elsewhere on the board
N24_N: X-NORTH.88; also elsewhere on the board
N24_P: X-NORTH.86; also elsewhere on the board
N25_N: X-NORTH.89; also elsewhere on the board
N25_P: X-NORTH.87; also elsewhere on the board
N26_N: X-NORTH.94; also elsewhere on the board
N26_P: X-NORTH.92; also elsewhere on the board
N27_N: X-NORTH.95; also elsewhere on the board
N27_P: X-NORTH.93; also elsewhere on the board
N28_N: X-NORTH.100; also elsewhere on the board
N28_P: X-NORTH.98; also elsewhere on the board
N29_N: X-NORTH.101; also elsewhere on the board
N29_P: X-NORTH.99; also elsewhere on the board
N30_N: X-NORTH.106; also elsewhere on the board
N30_P: X-NORTH.104; also elsewhere on the board
N31_N: X-NORTH.107; also elsewhere on the board
N31_P: X-NORTH.105; also elsewhere on the board
N32_N: X-NORTH.112; also elsewhere on the board
N32_P: X-NORTH.110; also elsewhere on the board
N33_N: X-NORTH.113; also elsewhere on the board
N33_P: X-NORTH.111; also elsewhere on the board
N34_N: X-NORTH.118; also elsewhere on the board
N34_P: X-NORTH.116; also elsewhere on the board
N35_N: X-NORTH.119; also elsewhere on the board
N35_P: X-NORTH.117; also elsewhere on the board
N36_N: X-NORTH.124
N36_P: X-NORTH.122
N37_N: X-NORTH.125; also elsewhere on the board
N37_P: X-NORTH.123; also elsewhere on the board
N38_N: X-NORTH.130; also elsewhere on the board
N38_P: X-NORTH.128; also elsewhere on the board
N39_N: X-NORTH.131; also elsewhere on the board
N39_P: X-NORTH.129; also elsewhere on the board
unnamed: R1X.2, R2X.1, UEP.7 (WP)
unnamed: R21.1, R22.2, U3.5 (ADJ)
N_CHK_EN: X-NORTH.8
N_CHK_V: X-NORTH.10; also elsewhere on the board
N_I2C_EN: X-NORTH.137
N_I2C_V: C1.1, R1X.1, UEP.8 (VCC), X-NORTH.135
N_SCK: X-NORTH.144; also elsewhere on the board
N_SCL: UEP.6 (SCL), X-NORTH.143
N_SDA: UEP.5 (SDA), X-NORTH.141
N_SDI: X-NORTH.140; also elsewhere on the board
N_SDO: X-NORTH.142; also elsewhere on the board
N_SPI_EN: X-NORTH.136; also elsewhere on the board
N_SPI_V: X-NORTH.134; also elsewhere on the board
N_VE: X-NORTH.109, X-NORTH.115, X-NORTH.121, X-NORTH.127, X-NORTH.133; also elsewhere on the board
N_VE_CV: X-NORTH.6; also elsewhere on the board
N_VE_OV: X-NORTH.5; also elsewhere on the board
N_VE_UV: X-NORTH.11; also elsewhere on the board
N_VN: X-NORTH.49, X-NORTH.55, X-NORTH.61, X-NORTH.67, X-NORTH.73, X-NORTH.79, X-NORTH.85, X-NORTH.91, X-NORTH.97; also elsewhere on the board
N_VN_CV: X-NORTH.4; also elsewhere on the board
N_VN_OV: X-NORTH.3; also elsewhere on the board
N_VN_UV: X-NORTH.9; also elsewhere on the board
N_VW: X-NORTH.13, X-NORTH.19, X-NORTH.25, X-NORTH.31, X-NORTH.37; also elsewhere on the board
N_VW_CV: X-NORTH.2; also elsewhere on the board
N_VW_OV: X-NORTH.1; also elsewhere on the board
N_VW_UV: X-NORTH.7; also elsewhere on the board
S00_N: X-SOUTH.16
S00_P: X-SOUTH.14
S01_N: X-SOUTH.17
S01_P: X-SOUTH.15
S02_N: X-SOUTH.22
S02_P: X-SOUTH.20
S03_N: X-SOUTH.23
S03_P: X-SOUTH.21
S04_N: X-SOUTH.28; also elsewhere on the board
S04_P: X-SOUTH.26; also elsewhere on the board
S05_N: X-SOUTH.29
S05_P: X-SOUTH.27
S06_N: X-SOUTH.34; also elsewhere on the board
S06_P: X-SOUTH.32; also elsewhere on the board
S07_N: X-SOUTH.35; also elsewhere on the board
S07_P: X-SOUTH.33; also elsewhere on the board
S08_N: X-SOUTH.40; also elsewhere on the board
S08_P: X-SOUTH.38; also elsewhere on the board
S09_N: X-SOUTH.41; also elsewhere on the board
S09_P: X-SOUTH.39; also elsewhere on the board
S10_N: X-SOUTH.46; also elsewhere on the board
S10_P: X-SOUTH.44; also elsewhere on the board
S11_N: X-SOUTH.47; also elsewhere on the board
S11_P: X-SOUTH.45; also elsewhere on the board
S12_N: X-SOUTH.52; also elsewhere on the board
S12_P: X-SOUTH.50; also elsewhere on the board
S13_N: X-SOUTH.53; also elsewhere on the board
S13_P: X-SOUTH.51; also elsewhere on the board
S14_N: X-SOUTH.58; also elsewhere on the board
S14_P: X-SOUTH.56; also elsewhere on the board
S15_N: X-SOUTH.59; also elsewhere on the board
S15_P: X-SOUTH.57; also elsewhere on the board
S16_N: X-SOUTH.64; also elsewhere on the board
S16_P: X-SOUTH.62; also elsewhere on the board
S17_N: X-SOUTH.65; also elsewhere on the board
S17_P: X-SOUTH.63; also elsewhere on the board
S18_N: X-SOUTH.70; also elsewhere on the board
S18_P: X-SOUTH.68; also elsewhere on the board
S19_N: X-SOUTH.71; also elsewhere on the board
S19_P: X-SOUTH.69; also elsewhere on the board
S20_N: X-SOUTH.76; also elsewhere on the board
S20_P: X-SOUTH.74; also elsewhere on the board
S21_N: X-SOUTH.77; also elsewhere on the board
S21_P: X-SOUTH.75; also elsewhere on the board
S22_N: X-SOUTH.82; also elsewhere on the board
S22_P: X-SOUTH.80; also elsewhere on the board
S23_N: X-SOUTH.83; also elsewhere on the board
S23_P: X-SOUTH.81; also elsewhere on the board
S24_N: X-SOUTH.88; also elsewhere on the board
S24_P: X-SOUTH.86; also elsewhere on the board
S25_N: X-SOUTH.89; also elsewhere on the board
S25_P: X-SOUTH.87; also elsewhere on the board
S26_N: X-SOUTH.94; also elsewhere on the board
S26_P: X-SOUTH.92; also elsewhere on the board
S27_N: X-SOUTH.95; also elsewhere on the board
S27_P: X-SOUTH.93; also elsewhere on the board
S28_N: X-SOUTH.100; also elsewhere on the board
S28_P: X-SOUTH.98; also elsewhere on the board
S29_N: X-SOUTH.101; also elsewhere on the board
S29_P: X-SOUTH.99; also elsewhere on the board
S30_N: X-SOUTH.106; also elsewhere on the board
S30_P: X-SOUTH.104; also elsewhere on the board
S31_N: X-SOUTH.107; also elsewhere on the board
S31_P: X-SOUTH.105; also elsewhere on the board
S32_N: X-SOUTH.112; also elsewhere on the board
S32_P: X-SOUTH.110; also elsewhere on the board
S33_N: X-SOUTH.113; also elsewhere on the board
S33_P: X-SOUTH.111; also elsewhere on the board
S34_N: X-SOUTH.118; also elsewhere on the board
S34_P: X-SOUTH.116; also elsewhere on the board
S35_N: X-SOUTH.119; also elsewhere on the board
S35_P: X-SOUTH.117; also elsewhere on the board
S36_N: X-SOUTH.124; also elsewhere on the board
S36_P: X-SOUTH.122; also elsewhere on the board
S37_N: X-SOUTH.125; also elsewhere on the board
S37_P: X-SOUTH.123; also elsewhere on the board
S38_N: X-SOUTH.130
S38_P: X-SOUTH.128
S39_N: U3.6 (EN), X-SOUTH.131
S39_P: X-SOUTH.129
S_CHK_EN: X-SOUTH.8
S_CHK_V: X-SOUTH.10; also elsewhere on the board
S_I2C_EN: X-SOUTH.137
S_I2C_V: X-SOUTH.135; also elsewhere on the board
S_SCK: X-SOUTH.144
S_SCL: X-SOUTH.143; also elsewhere on the board
S_SDA: X-SOUTH.141; also elsewhere on the board
S_SDI: X-SOUTH.140
S_SDO: X-SOUTH.142
S_SPI_EN: X-SOUTH.136
S_SPI_V: X-SOUTH.134
S_VE: X-SOUTH.13, X-SOUTH.19, X-SOUTH.25, X-SOUTH.31, X-SOUTH.37
S_VE_CV: X-SOUTH.2; also elsewhere on the board
S_VE_OV: X-SOUTH.1; also elsewhere on the board
S_VE_UV: X-SOUTH.7; also elsewhere on the board
S_VS: X-SOUTH.49, X-SOUTH.55, X-SOUTH.61, X-SOUTH.67, X-SOUTH.73, X-SOUTH.79, X-SOUTH.85, X-SOUTH.91, X-SOUTH.97; also elsewhere on the board
S_VS_CV: X-SOUTH.4; also elsewhere on the board
S_VS_OV: X-SOUTH.3; also elsewhere on the board
S_VS_UV: X-SOUTH.9; also elsewhere on the board
S_VW: C90.1, U3.1 (BIAS), U3.3 (IN), X-SOUTH.109, X-SOUTH.115, X-SOUTH.121, X-SOUTH.127, X-SOUTH.133
S_VW_CV: X-SOUTH.6; also elsewhere on the board
S_VW_OV: X-SOUTH.5; also elsewhere on the board
S_VW_UV: X-SOUTH.11; also elsewhere on the board
VTREF: C91.2, R21.2, U3.4 (OUT); also elsewhere on the board

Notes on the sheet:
Info EEPROM
VREF External Supply CMV12K-AN01-v4 3.3.1
AXIOM Beta CMV12000
Copyright (C) 2014-2015 H.Poetzl Licensed under CERN OHL v.1.2
Interface, Info and VREF
Optional VREF Supply


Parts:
C2, C3, C4, C5, C6, C7: 100n; 0402-C
C8, C9, C10, C11, C12, C13: 1µ; 0402-C
R1, R7: 28k7; 0402-C
R2, R8: 3k32; 0402-C
R3, R9, R15, R18: 16k9; 0402-C
R4: 15k4; 0402-C
R5: 3k09; 0402-C
R6: 30k9; 0402-C
R10, R11, R12: R0402-C; 0402-C
R13: 22k6; 0402-C
R14: 9k53; 0402-C
R16: 18k7; 0402-C
R17: 13k3; 0402-C
R19, R20: 18k; 0402-C
TP1, TP2, TP3, TP4: TPTP10R; TP10R
U1, U2: TLV431DCK; SOT65P210X110-6N
UNE: TS332IQ2T; DFN200X200X100-9N
UNN: TS332IQ2T; DFN200X200X100-9N
UNW: TS332IQ2T; DFN200X200X100-9N
USE: TS332IQ2T; DFN200X200X100-9N
USS: TS332IQ2T; DFN200X200X100-9N
USW: TS332IQ2T; DFN200X200X100-9N

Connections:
GND: C2.2, C3.2, C4.2, C5.2, C6.2, C7.2, C8.2, C9.2, C10.2, C11.2, C12.2, C13.2, R3.2, R6.2, R9.2, R12.2, R15.2, R18.2, U1.6 (ANODE), U2.6 (ANODE), UNE.4 (VSS), UNE.EP, UNN.4 (VSS), UNN.EP, UNW.4 (VSS), UNW.EP, USE.4 (VSS), USE.EP, USS.4 (VSS), USS.EP, USW.4 (VSS), USW.EP; also elsewhere on the board
unnamed: R11.2, R12.1, USE.6 (VINB-)
unnamed: R5.2, R6.1, UNN.6 (VINB-)
unnamed: R8.2, R9.1, UNE.6 (VINB-)
unnamed: R10.2, R11.1, USE.3 (VINA+)
unnamed: R7.2, R8.1, UNE.3 (VINA+)
unnamed: R1.2, R2.1, UNW.3 (VINA+)
unnamed: R2.2, R3.1, UNW.6 (VINB-)
unnamed: R14.2, R15.1, USS.6 (VINB-)
unnamed: R13.2, R14.1, USS.3 (VINA+)
unnamed: R16.2, R17.1, USW.3 (VINA+)
unnamed: R17.2, R18.1, USW.6 (VINB-)
N_CHK_V: C2.1, C3.1, C4.1, R19.1, TP1.TP, UNE.8 (VDD), UNN.8 (VDD), UNW.8 (VDD); also elsewhere on the board
N_REF: R19.2, TP2.TP, U1.1 (CATHODE), U1.3 (REF), UNE.2 (VINA-), UNE.5 (VINB+), UNN.2 (VINA-), UNN.5 (VINB+), UNW.2 (VINA-), UNW.5 (VINB+)
N_VE_CV: C10.1, R7.1; also elsewhere on the board
N_VE_OV: UNE.7 (OUTB); also elsewhere on the board
N_VE_UV: UNE.1 (OUTA); also elsewhere on the board
N_VN_CV: C9.1, R4.1; also elsewhere on the board
N_VN_OV: UNN.7 (OUTB); also elsewhere on the board
N_VN_UV: UNN.1 (OUTA); also elsewhere on the board
N_VW_CV: C8.1, R1.1; also elsewhere on the board
N_VW_OV: UNW.7 (OUTB); also elsewhere on the board
N_VW_UV: UNW.1 (OUTA); also elsewhere on the board
R5: R4.2, R5.1, UNN.3 (VINA+)
S_CHK_V: C5.1, C6.1, C7.1, R20.1, TP3.TP, USE.8 (VDD), USS.8 (VDD), USW.8 (VDD); also elsewhere on the board
S_REF: R20.2, TP4.TP, U2.1 (CATHODE), U2.3 (REF), USE.2 (VINA-), USE.5 (VINB+), USS.2 (VINA-), USS.5 (VINB+), USW.2 (VINA-), USW.5 (VINB+)
S_VE_CV: C11.1, R10.1; also elsewhere on the board
S_VE_OV: USE.7 (OUTB); also elsewhere on the board
S_VE_UV: USE.1 (OUTA); also elsewhere on the board
S_VS_CV: C12.1, R13.1; also elsewhere on the board
S_VS_OV: USS.7 (OUTB); also elsewhere on the board
S_VS_UV: USS.1 (OUTA); also elsewhere on the board
S_VW_CV: C13.1, R16.1; also elsewhere on the board
S_VW_OV: USW.7 (OUTB); also elsewhere on the board
S_VW_UV: USW.1 (OUTA); also elsewhere on the board

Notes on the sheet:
AXIOM Beta CMV12000
Copyright (C) 2014-2020 H.Poetzl Licensed under CERN OHL v.1.2
Over/Under Voltage Check
4/5 Voltages
VDDRES [3.0V-3.6V]
VDD18 [1.8V-1.98V]
VDD33 [3.0V-3.6V]
VDDPIX [2.3V-3.6V]
VTREF Supply [2.0V-3.6V]
Unused [do not populate]

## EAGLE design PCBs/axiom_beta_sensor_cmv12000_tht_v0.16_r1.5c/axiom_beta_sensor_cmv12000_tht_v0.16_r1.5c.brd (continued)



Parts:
C59, C65, C66, C67, C68, C69, C70, C93: 100n; 0402-C
R25: 100R; 0402-C
SENSOR: CMV12000ANDON; 10-30-07-237-400T4
TP9: TPTP10R; TP10R
U4, U5, U6: SN74AVC4T774RSV; QFN40P185X265X55-16N
U7: LM75BGD; SOT996-2/3

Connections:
CLK_IN: SENSOR.E30 (CLK_IN), U6.12 (B1)
FRAME_REQ: SENSOR.G30 (FRAME_REQ), U5.11 (B2)
GND: C59.2, C65.2, C66.2, C67.2, C68.2, C69.2, C70.2, C93.2, SENSOR.E4 (DIO2), SENSOR.F4 (DIO1), SENSOR.G3 (DIO4), SENSOR.H4 (DIO3), U4.7 (!OE), U4.8 (GND), U4.16 (DIR2), U5.6 (DIR4), U5.7 (!OE), U5.8 (GND), U6.7 (!OE), U6.8 (GND), U6.16 (DIR2), U7.4 (GND), U7.5 (A2), U7.6 (A1), U7.7 (A0); also elsewhere on the board
N00_N: R25.2, SENSOR.E6 (LVDS_CLK_P); also elsewhere on the board
N00_P: R25.1, SENSOR.E5 (LVDS_CLK_N); also elsewhere on the board
N01_N: SENSOR.G7 (OUTCLK_P); also elsewhere on the board
N01_P: SENSOR.G6 (OUTCLK_N); also elsewhere on the board
N02_N: SENSOR.F7 (OUT33_P); also elsewhere on the board
N02_P: SENSOR.F6 (OUT33_N); also elsewhere on the board
N04_N: SENSOR.E8 (OUT35_P); also elsewhere on the board
N04_P: SENSOR.E7 (OUT35_N); also elsewhere on the board
N05_N: SENSOR.H8 (OUT34_P); also elsewhere on the board
N05_P: SENSOR.H7 (OUT34_N); also elsewhere on the board
N06_N: SENSOR.F9 (OUT37_P); also elsewhere on the board
N06_P: SENSOR.F8 (OUT37_N); also elsewhere on the board
N07_N: SENSOR.G9 (OUT36_P); also elsewhere on the board
N07_P: SENSOR.G8 (OUT36_N); also elsewhere on the board
N08_N: SENSOR.E10 (OUT38_P); also elsewhere on the board
N08_P: SENSOR.E9 (OUT38_N); also elsewhere on the board
N09_N: SENSOR.G11 (OUT39_P); also elsewhere on the board
N09_P: SENSOR.G10 (OUT39_N); also elsewhere on the board
N10_N: SENSOR.F11 (OUT40_P); also elsewhere on the board
N10_P: SENSOR.F10 (OUT40_N); also elsewhere on the board
N11_N: SENSOR.H12 (OUT41_P); also elsewhere on the board
N11_P: SENSOR.H11 (OUT41_N); also elsewhere on the board
N12_N: SENSOR.E12 (OUT42_P); also elsewhere on the board
N12_P: SENSOR.E11 (OUT42_N); also elsewhere on the board
N13_N: SENSOR.G13 (OUT43_P); also elsewhere on the board
N13_P: SENSOR.G12 (OUT43_N); also elsewhere on the board
N14_N: SENSOR.F13 (OUT44_P); also elsewhere on the board
N14_P: SENSOR.F12 (OUT44_N); also elsewhere on the board
N15_N: SENSOR.H14 (OUT45_P); also elsewhere on the board
N15_P: SENSOR.H13 (OUT45_N); also elsewhere on the board
N16_N: SENSOR.E14 (OUT46_P); also elsewhere on the board
N16_P: SENSOR.E13 (OUT46_N); also elsewhere on the board
N17_N: SENSOR.G15 (OUT47_P); also elsewhere on the board
N17_P: SENSOR.G14 (OUT47_N); also elsewhere on the board
N18_N: SENSOR.F15 (OUT48_P); also elsewhere on the board
N18_P: SENSOR.F14 (OUT48_N); also elsewhere on the board
N19_N: SENSOR.G17 (OUT50_P); also elsewhere on the board
N19_P: SENSOR.G16 (OUT50_N); also elsewhere on the board
N20_N: SENSOR.F17 (OUT49_P); also elsewhere on the board
N20_P: SENSOR.F16 (OUT49_N); also elsewhere on the board
N21_N: SENSOR.H18 (OUT52_P); also elsewhere on the board
N21_P: SENSOR.H17 (OUT52_N); also elsewhere on the board
N22_N: SENSOR.E18 (OUT51_P); also elsewhere on the board
N22_P: SENSOR.E17 (OUT51_N); also elsewhere on the board
N23_N: SENSOR.G19 (OUT54_P); also elsewhere on the board
N23_P: SENSOR.G18 (OUT54_N); also elsewhere on the board
N24_N: SENSOR.F19 (OUT53_P); also elsewhere on the board
N24_P: SENSOR.F18 (OUT53_N); also elsewhere on the board
N25_N: SENSOR.H20 (OUT56_P); also elsewhere on the board
N25_P: SENSOR.H19 (OUT56_N); also elsewhere on the board
N26_N: SENSOR.E20 (OUT55_P); also elsewhere on the board
N26_P: SENSOR.E19 (OUT55_N); also elsewhere on the board
N27_N: SENSOR.G21 (OUT58_P); also elsewhere on the board
N27_P: SENSOR.G20 (OUT58_N); also elsewhere on the board
N28_N: SENSOR.F21 (OUT57_P); also elsewhere on the board
N28_P: SENSOR.F20 (OUT57_N); also elsewhere on the board
N29_N: SENSOR.G23 (OUT61_P); also elsewhere on the board
N29_P: SENSOR.G22 (OUT61_N); also elsewhere on the board
N30_N: SENSOR.E22 (OUT59_P); also elsewhere on the board
N30_P: SENSOR.E21 (OUT59_N); also elsewhere on the board
N31_N: SENSOR.H24 (OUT63_P); also elsewhere on the board
N31_P: SENSOR.H23 (OUT63_N); also elsewhere on the board
N32_N: SENSOR.F23 (OUT60_P); also elsewhere on the board
N32_P: SENSOR.F22 (OUT60_N); also elsewhere on the board
N33_N: SENSOR.G25 (OUT64_P); also elsewhere on the board
N33_P: SENSOR.G24 (OUT64_N); also elsewhere on the board
N34_N: SENSOR.E24 (OUT62_P); also elsewhere on the board
N34_P: SENSOR.E23 (OUT62_N); also elsewhere on the board
N35_N: U6.4 (A4); also elsewhere on the board
N35_P: U6.3 (A3); also elsewhere on the board
N37_N: U5.3 (A3); also elsewhere on the board
N37_P: U5.4 (A4); also elsewhere on the board
N38_N: U6.2 (A2); also elsewhere on the board
N38_P: U6.1 (A1); also elsewhere on the board
N39_N: U5.1 (A1); also elsewhere on the board
N39_P: U5.2 (A2); also elsewhere on the board
unnamed: TP9.TP, U6.9 (B4)
N_SCK: U4.4 (A4); also elsewhere on the board
N_SDI: U4.2 (A2); also elsewhere on the board
N_SDO: U4.3 (A3); also elsewhere on the board
N_SPI_EN: U4.1 (A1); also elsewhere on the board
N_SPI_V: C59.1, U4.5 (DIR3), U4.6 (DIR4), U4.14 (VCCA), U4.15 (DIR1); also elsewhere on the board
N_VE: C67.1, C69.1, C93.1, U4.13 (VCCB), U5.13 (VCCB), U6.13 (VCCB); also elsewhere on the board
N_VN: C68.1, C70.1, U5.5 (DIR3), U5.14 (VCCA), U5.15 (DIR1), U5.16 (DIR2), U6.5 (DIR3), U6.6 (DIR4), U6.14 (VCCA), U6.15 (DIR1); also elsewhere on the board
S04_N: SENSOR.C24 (OUT32_N); also elsewhere on the board
S04_P: SENSOR.C25 (OUT32_P); also elsewhere on the board
S06_N: SENSOR.D23 (OUT30_N); also elsewhere on the board
S06_P: SENSOR.D24 (OUT30_P); also elsewhere on the board
S07_N: SENSOR.B24 (OUT31_N); also elsewhere on the board
S07_P: SENSOR.B25 (OUT31_P); also elsewhere on the board
S08_N: SENSOR.D21 (OUT27_N); also elsewhere on the board
S08_P: SENSOR.D22 (OUT27_P); also elsewhere on the board
S09_N: SENSOR.A23 (OUT29_N); also elsewhere on the board
S09_P: SENSOR.A24 (OUT29_P); also elsewhere on the board
S10_N: SENSOR.C21 (OUT28_N); also elsewhere on the board
S10_P: SENSOR.C22 (OUT28_P); also elsewhere on the board
S11_N: SENSOR.B20 (OUT26_N); also elsewhere on the board
S11_P: SENSOR.B21 (OUT26_P); also elsewhere on the board
S12_N: SENSOR.D19 (OUT24_N); also elsewhere on the board
S12_P: SENSOR.D20 (OUT24_P); also elsewhere on the board
S13_N: SENSOR.A19 (OUT23_N); also elsewhere on the board
S13_P: SENSOR.A20 (OUT23_P); also elsewhere on the board
S14_N: SENSOR.C19 (OUT25_N); also elsewhere on the board
S14_P: SENSOR.C20 (OUT25_P); also elsewhere on the board
S15_N: SENSOR.B18 (OUT22_N); also elsewhere on the board
S15_P: SENSOR.B19 (OUT22_P); also elsewhere on the board
S16_N: SENSOR.C17 (OUT21_N); also elsewhere on the board
S16_P: SENSOR.C18 (OUT21_P); also elsewhere on the board
S17_N: SENSOR.A17 (OUT19_N); also elsewhere on the board
S17_P: SENSOR.A18 (OUT19_P); also elsewhere on the board
S18_N: SENSOR.D17 (OUT20_N); also elsewhere on the board
S18_P: SENSOR.D18 (OUT20_P); also elsewhere on the board
S19_N: SENSOR.B16 (OUT18_N); also elsewhere on the board
S19_P: SENSOR.B17 (OUT18_P); also elsewhere on the board
S20_N: SENSOR.D15 (OUT17_N); also elsewhere on the board
S20_P: SENSOR.D16 (OUT17_P); also elsewhere on the board
S21_N: SENSOR.B14 (OUT16_N); also elsewhere on the board
S21_P: SENSOR.B15 (OUT16_P); also elsewhere on the board
S22_N: SENSOR.D13 (OUT15_N); also elsewhere on the board
S22_P: SENSOR.D14 (OUT15_P); also elsewhere on the board
S23_N: SENSOR.A13 (OUT13_N); also elsewhere on the board
S23_P: SENSOR.A14 (OUT13_P); also elsewhere on the board
S24_N: SENSOR.C13 (OUT14_N); also elsewhere on the board
S24_P: SENSOR.C14 (OUT14_P); also elsewhere on the board
S25_N: SENSOR.B12 (OUT12_N); also elsewhere on the board
S25_P: SENSOR.B13 (OUT12_P); also elsewhere on the board
S26_N: SENSOR.D11 (OUT10_N); also elsewhere on the board
S26_P: SENSOR.D12 (OUT10_P); also elsewhere on the board
S27_N: SENSOR.A11 (OUT9_N); also elsewhere on the board
S27_P: SENSOR.A12 (OUT9_P); also elsewhere on the board
S28_N: SENSOR.C11 (OUT11_N); also elsewhere on the board
S28_P: SENSOR.C12 (OUT11_P); also elsewhere on the board
S29_N: SENSOR.B10 (OUT8_N); also elsewhere on the board
S29_P: SENSOR.B11 (OUT8_P); also elsewhere on the board
S30_N: SENSOR.C9 (OUT7_N); also elsewhere on the board
S30_P: SENSOR.C10 (OUT7_P); also elsewhere on the board
S31_N: SENSOR.B8 (OUT5_N); also elsewhere on the board
S31_P: SENSOR.B9 (OUT5_P); also elsewhere on the board
S32_N: SENSOR.D9 (OUT6_N); also elsewhere on the board
S32_P: SENSOR.D10 (OUT6_P); also elsewhere on the board
S33_N: SENSOR.A7 (OUT2_N); also elsewhere on the board
S33_P: SENSOR.A8 (OUT2_P); also elsewhere on the board
S34_N: SENSOR.C7 (OUT4_N); also elsewhere on the board
S34_P: SENSOR.C8 (OUT4_P); also elsewhere on the board
S35_N: SENSOR.B6 (OUT1_N); also elsewhere on the board
S35_P: SENSOR.B7 (OUT1_P); also elsewhere on the board
S36_N: SENSOR.D7 (OUT3_N); also elsewhere on the board
S36_P: SENSOR.D8 (OUT3_P); also elsewhere on the board
S37_N: SENSOR.A5 (OUTCTR_N); also elsewhere on the board
S37_P: SENSOR.A6 (OUTCTR_P); also elsewhere on the board
SPI_CLK: SENSOR.H29 (SPI_CLK), U4.9 (B4)
SPI_EN: SENSOR.F28 (SPI_EN), U4.12 (B1)
SPI_IN: SENSOR.E28 (SPI_IN), U4.10 (B3)
SPI_OUT: SENSOR.G28 (SPI_OUT), U4.11 (B2)
SYS_RES_N: SENSOR.F30 (SYS_RES_N), U5.10 (B3)
S_I2C_V: U7.8 (VCC); also elsewhere on the board
S_SCL: U7.2 (SCL); also elsewhere on the board
S_SDA: U7.1 (SDA); also elsewhere on the board
TDIG1: SENSOR.G27 (TDIG1), U5.9 (B4)
TDIG2: SENSOR.G26 (TDIG2), U6.11 (B2)
T_EXP1: SENSOR.H30 (T_EXP1), U5.12 (B1)
T_EXP2: SENSOR.E29 (T_EXP2), U6.10 (B3)
VTREF: C65.1, SENSOR.B2 (VTREF); also elsewhere on the board
VTSIG: C66.1, SENSOR.C2 (VTSIG); also elsewhere on the board

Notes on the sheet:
AXIOM Beta CMV12000
Copyright (C) 2014-2020 H.Poetzl Licensed under CERN OHL v.1.2
CMV12000 DIO and LVDS
Including TDIG1/TDIG2
DIR Funct L B -> A H A -> B
VDD18 [1.8V-1.98V]
VDD33 [3.0V-3.6V]


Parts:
FID1, FID2, FID3, FID4: FIDUCIAL; FID_ARROW
FID5, FID6, FID7, FID8: FIDUCIAL-3A; FID_3ARROW

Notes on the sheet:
AXIOM Beta CMV12000
Copyright (C) 2014-2020 H.Poetzl Licensed under CERN OHL v.1.2
Fiducials



Board: 4 copper layers, 57.1 x 57.1 mm, 159 parts (147 on the bottom side), 234 nets.

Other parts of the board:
PARALLELLA: PARALLELLA-FRAME
U$1: µZ-FRAME

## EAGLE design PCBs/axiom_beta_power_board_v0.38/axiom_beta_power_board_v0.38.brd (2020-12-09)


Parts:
FID5, FID6, FID7, FID8: FIDUCIAL; FID_ARROW
JX1B, JX2B: BERGSTAK-61083F; 61083-FAKE
VP+: TPTP16SQ; TP16SQ
VP-: TPTP16SQ; TP16SQ
ZED: µZ-FCI-CONONLY; µZ-CONONLY

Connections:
AB_SCL: ZED.113 (_0); also elsewhere on the board
AB_SDA: ZED.114 (_1); also elsewhere on the board
BANK13_SE_0: ZED.200 (_0); also elsewhere on the board
DXP_0_N: ZED.100 (_N)
DXP_0_P: ZED.98 (_P)
GND: ZED.15 (GND), ZED.16 (GND), ZED.21 (GND), ZED.22 (GND), ZED.27 (GND), ZED.28 (GND), ZED.33 (GND), ZED.34 (GND), ZED.39 (GND), ZED.40 (GND), ZED.45 (GND), ZED.46 (GND), ZED.51 (GND), ZED.52 (GND), ZED.65 (GND), ZED.66 (GND), ZED.71 (GND), ZED.72 (GND), ZED.77 (GND), ZED.85 (GND), ZED.86 (GND), ZED.95 (GND), ZED.96 (GND), ZED.115 (GND), ZED.116 (GND), ZED.121 (GND), ZED.122 (GND), ZED.127 (GND), ZED.128 (GND), ZED.133 (GND), ZED.134 (GND), ZED.139 (GND), ZED.140 (GND), ZED.145 (GND), ZED.146 (GND), ZED.151 (GND), ZED.152 (GND), ZED.165 (GND), ZED.166 (GND), ZED.171 (GND), ZED.172 (GND), ZED.177 (GND), ZED.185 (GND), ZED.186 (GND), ZED.191 (GND), ZED.192 (GND); also elsewhere on the board
SE_0: ZED.9 (_0); also elsewhere on the board
SE_1: ZED.10 (_1); also elsewhere on the board
VBAT: ZED.7 (FPGA_VBAT)
VCCO_13: ZED.198 (VCCO_13); also elsewhere on the board
VCCO_34: ZED.78 (VCCO_34), ZED.79 (VCCO_34), ZED.80 (VCCO_34); also elsewhere on the board
VCCO_35: ZED.178 (VCCO_35), ZED.179 (VCCO_35), ZED.180 (VCCO_35); also elsewhere on the board
VP_0_N: VP-.TP, ZED.99 (_N)
VP_0_P: VP+.TP, ZED.97 (_P)
ZED_5V': ZED.57 (VIN_HDR), ZED.58 (VIN_HDR), ZED.59 (VIN_HDR), ZED.60 (VIN_HDR), ZED.112 (VIN_HDR), ZED.157 (VIN_HDR), ZED.158 (VIN_HDR), ZED.159 (VIN_HDR), ZED.160 (VIN_HDR); also elsewhere on the board

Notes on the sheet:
AXIOM Beta Power Board
Copyright (C) 2014-2020 H.Poetzl Licensed under CERN OHL v.1.2
MicroZed Power [Bottom]
Smart Power
RFE CLK
RFW CLK

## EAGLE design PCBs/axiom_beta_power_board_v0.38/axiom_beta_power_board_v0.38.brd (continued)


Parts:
BETA: µZ-FCI-SOCKET-NOHOLES-R; µZ-SOCKET-NOHOLES-R
FID1, FID2, FID3, FID4: FIDUCIAL; FID_ARROW
JX1T, JX2T: BERGSTAK-61082F; 61082-FAKE

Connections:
BANK13_SE_0: BETA.200 (_0); also elsewhere on the board
CSO_NE_V: BETA.7 (FPGA_VBAT); also elsewhere on the board
CSO_SW_V: BETA.112 (VIN_HDR); also elsewhere on the board
GND: BETA.15 (GND), BETA.16 (GND), BETA.21 (GND), BETA.22 (GND), BETA.27 (GND), BETA.28 (GND), BETA.33 (GND), BETA.34 (GND), BETA.39 (GND), BETA.40 (GND), BETA.45 (GND), BETA.46 (GND), BETA.51 (GND), BETA.52 (GND), BETA.65 (GND), BETA.66 (GND), BETA.71 (GND), BETA.72 (GND), BETA.77 (GND), BETA.85 (GND), BETA.86 (GND), BETA.95 (GND), BETA.96 (GND), BETA.115 (GND), BETA.116 (GND), BETA.121 (GND), BETA.122 (GND), BETA.127 (GND), BETA.128 (GND), BETA.133 (GND), BETA.134 (GND), BETA.139 (GND), BETA.140 (GND), BETA.145 (GND), BETA.146 (GND), BETA.151 (GND), BETA.152 (GND), BETA.165 (GND), BETA.166 (GND), BETA.171 (GND), BETA.172 (GND), BETA.177 (GND), BETA.185 (GND), BETA.186 (GND), BETA.191 (GND), BETA.192 (GND); also elsewhere on the board
NC$1: BETA.113 (_0)
NC$2: BETA.114 (_1)
PCIE_I2C_V: BETA.198 (VCCO_13)
PCIE_N_5V: BETA.59 (VIN_HDR), BETA.60 (VIN_HDR)
PCIE_N_V: BETA.79 (VCCO_34), BETA.80 (VCCO_34); also elsewhere on the board
PCIE_N_VCCIO: BETA.78 (VCCO_34)
PCIE_S_5V: BETA.159 (VIN_HDR), BETA.160 (VIN_HDR)
PCIE_S_V: BETA.179 (VCCO_35), BETA.180 (VCCO_35); also elsewhere on the board
PCIE_S_VCCIO: BETA.178 (VCCO_35)
PEX_N_V: BETA.57 (VIN_HDR), BETA.58 (VIN_HDR)
PEX_S_V: BETA.157 (VIN_HDR), BETA.158 (VIN_HDR)
SE_0: BETA.9 (_0); also elsewhere on the board
SE_1: BETA.10 (_1); also elsewhere on the board

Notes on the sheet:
AXIOM Beta Power Board
Copyright (C) 2014-2020 H.Poetzl Licensed under CERN OHL v.1.2
Beta Main Board Power [Top]



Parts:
BETA: µZ-FCI-SOCKET-NOHOLES-R; µZ-SOCKET-NOHOLES-R
C1, C5, C6, C10: 10u; 0603-B
C2, C4, C7, C9: 10u; 1206-C
C3, C8: 1n; 0402-C
C83, C84: 10u; 0603-C
C93: 4u7; 0402-B
D1: PMEG2010BELD; DFN1006D-2
L18: L0603-C; 0603-C
Q1: NX3008NBKT; SOT416
R110, R114: 147k; 0402-C
R111, R115: 28k; 0402-C
R112: 180k; 0402-B
R113: 20k; 0402-B
R116, R117: 100k; 0402-B
R118: 100k; 0402-C
R126: 10k; 0402-B
R127, R129: 180k; 0402-C
R128, R130: 20k; 0402-C
S/N: 91658; 3X2MM
U1: PIC16F15325-JQ; UQFN65P400X400X100-17N
U2, U3: TPS82130SIL-GM; SIL0008D-GM
U26: SC202A; MLPQ-13
U31: NCP715; DFN150X150X50-6N
X2: PINHD-2X02_2.54-90°; 2X02/90
ZED: µZ-FCI-CONONLY; µZ-CONONLY

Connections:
!X_MCLR: R126.2, U1.3 (RA3); also elsewhere on the board
BETA_5V: C4.1, C5.1, D1.A, R110.1, U3.4 (VOUT), U3.5 (VOUT); also elsewhere on the board
BETA_5V': C83.1, U26.5 (CTL3), U26.6 (CTL0), U26.7 (CTL1), U26.8 (CTL2), U26.9 (VIN); also elsewhere on the board
BETA_5V_EN: R116.2, U1.8 (RC1), U3.1 (EN)
BETA_5V_PG: U1.1 (RA5), U3.7 (PG)
BETA_TCK: BETA.1 (TCK)
BETA_TDI: BETA.4 (TDI)
BETA_TDO: BETA.3 (TDO)
BETA_TMS: BETA.2 (TMS)
BTN: R127.1, X2.1
BTN_SENSE: R127.2, R128.1, U1.6 (RC3)
FAN: Q1.3 (D), X2.3
FAN_PWM: R118.2, U1.4 (RC5)
GND: C1.2, C2.2, C3.2, C4.2, C5.2, C6.2, C7.2, C8.2, C9.2, C10.2, C83.2, C84.2, C93.2, Q1.2 (S), R111.2, R113.2, R115.2, R128.2, R130.2, S/N.1, U1.13 (GND), U1.EP (GND), U2.3 (GND), U2.EPAD (GND), U3.3 (GND), U3.EPAD (GND), U26.10 (GND), U31.3 (GND), X2.4; also elsewhere on the board
unnamed: C8.1, U2.8 (SS/TR)
unnamed: C3.1, U3.8 (SS/TR)
unnamed: Q1.1 (G), R118.1
unnamed: R110.2, R111.1, U3.6 (FB)
unnamed: R114.2, R115.1, U2.6 (FB)
REGOUT: C84.1, L18.1, U26.4 (SNS), U26.11 (VOUT), U26.12 (VOUT), U26.13 (VOUT)
SN_SENSE: S/N.2, U1.10 (RA2)
VCC: L18.2, R116.1, R117.1, R129.1; also elsewhere on the board
VCC_SENSE: R129.2, R130.1, U1.7 (RC2)
VIN: C1.1, C2.1, C6.1, C7.1, D1.C (K), R112.1, U2.2 (VIN), U3.2 (VIN), U31.1 (IN), X2.2
VIN_SENSE: R112.2, R113.1, U1.9 (RC0)
VSB: C93.1, R126.1, U1.16 (VCC), U31.6 (OUT); also elsewhere on the board
X_SCL: U1.11 (RA1); also elsewhere on the board
X_SDA: U1.12 (RA0); also elsewhere on the board
ZED_5V: C9.1, C10.1, R114.1, U2.4 (VOUT), U2.5 (VOUT); also elsewhere on the board
ZED_5V_EN: R117.2, U1.5 (RC4), U2.1 (EN)
ZED_5V_PG: U1.2 (RA4), U2.7 (PG)
ZED_TCK: ZED.1 (TCK)
ZED_TDI: ZED.4 (TDI)
ZED_TDO: ZED.3 (TDO)
ZED_TMS: ZED.2 (TMS)

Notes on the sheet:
AXIOM Beta Power Board
Copyright (C) 2014-2020 H.Poetzl Licensed under CERN OHL v.1.2
Power Conversion and JTAG


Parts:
BETA: µZ-FCI-SOCKET-NOHOLES-R; µZ-SOCKET-NOHOLES-R
ZED: µZ-FCI-CONONLY; µZ-CONONLY

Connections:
BANK13_00_N: BETA.89 (_N), ZED.89 (_N)
BANK13_00_P: BETA.87 (_P), ZED.87 (_P)
BANK13_01_N: BETA.90 (_N), ZED.90 (_N)
BANK13_01_P: BETA.88 (_P), ZED.88 (_P)
BANK13_02_N: BETA.93 (_N), ZED.93 (_N)
BANK13_02_P: BETA.91 (_P), ZED.91 (_P)
BANK13_03_N: BETA.94 (_N), ZED.94 (_N)
BANK13_03_P: BETA.92 (_P), ZED.92 (_P)
BANK13_04_N: BETA.195 (_N), ZED.195 (_N)
BANK13_04_P: BETA.193 (_P), ZED.193 (_P)
BANK13_05_N: BETA.196 (_N), ZED.196 (_N)
BANK13_05_P: BETA.194 (_P), ZED.194 (_P)
BANK13_06_N: BETA.199 (_N), ZED.199 (_N)
BANK13_06_P: BETA.197 (_P), ZED.197 (_P)
JX1_00_N: BETA.13 (_N), ZED.13 (_N)
JX1_00_P: BETA.11 (_P), ZED.11 (_P)
JX1_01_N: BETA.14 (_N), ZED.14 (_N)
JX1_01_P: BETA.12 (_P), ZED.12 (_P)
JX1_02_N: BETA.19 (_N), ZED.19 (_N)
JX1_02_P: BETA.17 (_P), ZED.17 (_P)
JX1_03_N: BETA.20 (_N), ZED.20 (_N)
JX1_03_P: BETA.18 (_P), ZED.18 (_P)
JX1_04_N: BETA.25 (_N), ZED.25 (_N)
JX1_04_P: BETA.23 (_P), ZED.23 (_P)
JX1_05_N: BETA.26 (_N), ZED.26 (_N)
JX1_05_P: BETA.24 (_P), ZED.24 (_P)
JX1_06_N: BETA.31 (_N), ZED.31 (_N)
JX1_06_P: BETA.29 (_P), ZED.29 (_P)
JX1_07_N: BETA.32 (_N), ZED.32 (_N)
JX1_07_P: BETA.30 (_P), ZED.30 (_P)
JX1_08_N: BETA.37 (_N), ZED.37 (_N)
JX1_08_P: BETA.35 (_P), ZED.35 (_P)
JX1_09_N: BETA.38 (_N), ZED.38 (_N)
JX1_09_P: BETA.36 (_P), ZED.36 (_P)
JX1_10_N: BETA.43 (_N), ZED.43 (_N)
JX1_10_P: BETA.41 (_P), ZED.41 (_P)
JX1_11_N: BETA.44 (_N), ZED.44 (_N)
JX1_11_P: BETA.42 (_P), ZED.42 (_P)
JX1_12_N: BETA.49 (_N), ZED.49 (_N)
JX1_12_P: BETA.47 (_P), ZED.47 (_P)
JX1_13_N: BETA.50 (_N), ZED.50 (_N)
JX1_13_P: BETA.48 (_P), ZED.48 (_P)
JX1_14_N: BETA.55 (_N), ZED.55 (_N)
JX1_14_P: BETA.53 (_P), ZED.53 (_P)
JX1_15_N: BETA.56 (_N), ZED.56 (_N)
JX1_15_P: BETA.54 (_P), ZED.54 (_P)
JX1_16_N: BETA.63 (_N), ZED.63 (_N)
JX1_16_P: BETA.61 (_P), ZED.61 (_P)
JX1_17_N: BETA.64 (_N), ZED.64 (_N)
JX1_17_P: BETA.62 (_P), ZED.62 (_P)
JX1_18_N: BETA.69 (_N), ZED.69 (_N)
JX1_18_P: BETA.67 (_P), ZED.67 (_P)
JX1_19_N: BETA.70 (_N), ZED.70 (_N)
JX1_19_P: BETA.68 (_P), ZED.68 (_P)
JX1_20_N: BETA.75 (_N), ZED.75 (_N)
JX1_20_P: BETA.73 (_P), ZED.73 (_P)
JX1_21_N: BETA.76 (_N), ZED.76 (_N)
JX1_21_P: BETA.74 (_P), ZED.74 (_P)
JX1_22_N: BETA.83 (_N), ZED.83 (_N)
JX1_22_P: BETA.81 (_P), ZED.81 (_P)
JX1_23_N: BETA.84 (_N), ZED.84 (_N)
JX1_23_P: BETA.82 (_P), ZED.82 (_P)
JX2_00_N: BETA.119 (_N), ZED.119 (_N)
JX2_00_P: BETA.117 (_P), ZED.117 (_P)
JX2_01_N: BETA.120 (_N), ZED.120 (_N)
JX2_01_P: BETA.118 (_P), ZED.118 (_P)
JX2_02_N: BETA.125 (_N), ZED.125 (_N)
JX2_02_P: BETA.123 (_P), ZED.123 (_P)
JX2_03_N: BETA.126 (_N), ZED.126 (_N)
JX2_03_P: BETA.124 (_P), ZED.124 (_P)
JX2_04_N: BETA.131 (_N), ZED.131 (_N)
JX2_04_P: BETA.129 (_P), ZED.129 (_P)
JX2_05_N: BETA.132 (_N), ZED.132 (_N)
JX2_05_P: BETA.130 (_P), ZED.130 (_P)
JX2_06_N: BETA.137 (_N), ZED.137 (_N)
JX2_06_P: BETA.135 (_P), ZED.135 (_P)
JX2_07_N: BETA.138 (_N), ZED.138 (_N)
JX2_07_P: BETA.136 (_P), ZED.136 (_P)
JX2_08_N: BETA.143 (_N), ZED.143 (_N)
JX2_08_P: BETA.141 (_P), ZED.141 (_P)
JX2_09_N: BETA.144 (_N), ZED.144 (_N)
JX2_09_P: BETA.142 (_P), ZED.142 (_P)
JX2_10_N: BETA.149 (_N), ZED.149 (_N)
JX2_10_P: BETA.147 (_P), ZED.147 (_P)
JX2_11_N: BETA.150 (_N), ZED.150 (_N)
JX2_11_P: BETA.148 (_P), ZED.148 (_P)
JX2_12_N: BETA.155 (_N), ZED.155 (_N)
JX2_12_P: BETA.153 (_P), ZED.153 (_P)
JX2_13_N: BETA.156 (_N), ZED.156 (_N)
JX2_13_P: BETA.154 (_P), ZED.154 (_P)
JX2_14_N: BETA.163 (_N), ZED.163 (_N)
JX2_14_P: BETA.161 (_P), ZED.161 (_P)
JX2_15_N: BETA.164 (_N), ZED.164 (_N)
JX2_15_P: BETA.162 (_P), ZED.162 (_P)
JX2_16_N: BETA.169 (_N), ZED.169 (_N)
JX2_16_P: BETA.167 (_P), ZED.167 (_P)
JX2_17_N: BETA.170 (_N), ZED.170 (_N)
JX2_17_P: BETA.168 (_P), ZED.168 (_P)
JX2_18_N: BETA.175 (_N), ZED.175 (_N)
JX2_18_P: BETA.173 (_P), ZED.173 (_P)
JX2_19_N: BETA.176 (_N), ZED.176 (_N)
JX2_19_P: BETA.174 (_P), ZED.174 (_P)
JX2_20_N: BETA.183 (_N), ZED.183 (_N)
JX2_20_P: BETA.181 (_P), ZED.181 (_P)
JX2_21_N: BETA.184 (_N), ZED.184 (_N)
JX2_21_P: BETA.182 (_P), ZED.182 (_P)
JX2_22_N: BETA.189 (_N), ZED.189 (_N)
JX2_22_P: BETA.187 (_P), ZED.187 (_P)
JX2_23_N: BETA.190 (_N), ZED.190 (_N)
JX2_23_P: BETA.188 (_P), ZED.188 (_P)

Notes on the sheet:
AXIOM Beta Power Board
Copyright (C) 2014-2020 H.Poetzl Licensed under CERN OHL v.1.2
LVDS Passthrough


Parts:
C11, C12, C82, C90: 10n; 0402-B
C91: 1u; 0402-B
C92: 100n; 0402-B
FB1: FB0402-B; 0402-B
PB-NW: DF12(XX)-20DP-0.5V
PB-SE: DF12(XX)-20DP-0.5V
R92, R93, R95, R96, R97, R98, R100, R101, R102, R103, R105, R106, R107, R108, R120, R121: 4k7; 0402-B
R94, R99, R104, R119: 200k; 0402-B
R109: 10k; 0402-B
R122, R123, R124, R125: 50k; 0402-B
SD1: MICRO-SD-2CD; TF-MICRO-SD_PP2
U4, U5, U25, U30: PCA9306GM; PCA9570GMH
U27: TS3A4751; SOP65P640X120-14N
U28: IP4251CZ16-8-TTL; SON40P135X330X55-17N
X1: PICO-SPOX-5
ZED: µZ-FCI-CONONLY; µZ-CONONLY

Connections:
AB_SCL: R93.2, U25.4 (S2); also elsewhere on the board
AB_SCL': R96.2, U25.5 (D2), U27.9 (COM3), U27.10 (COM4), U30.5 (D2)
AB_SDA: R92.2, U25.3 (S1); also elsewhere on the board
AB_SDA': R95.2, U25.6 (D1), U27.2 (COM1), U27.4 (COM2), U30.6 (D1)
A_!RST: PB-NW.1; also elsewhere on the board
A_BUS_EN: U27.12 (EN4), U27.13 (EN1); also elsewhere on the board
A_SCL: PB-NW.2, R101.2, U4.5 (D2)
A_SCL': R98.2, U4.4 (S2), U27.11 (NO4)
A_SDA: PB-NW.4, R100.2, U4.6 (D1)
A_SDA': R97.2, U4.3 (S1), U27.1 (NO1)
BETA_5V: X1.4, X1.4A (4); also elsewhere on the board
B_!RST: PB-SE.1; also elsewhere on the board
B_BUS_EN: U27.5 (EN2), U27.6 (EN3); also elsewhere on the board
B_SCL: PB-SE.2, R106.2, U5.5 (D2)
B_SCL': R103.2, U5.4 (S2), U27.8 (NO3)
B_SDA: PB-SE.4, R105.2, U5.6 (D1)
B_SDA': R102.2, U5.3 (S1), U27.3 (NO2)
CD: SD1.CD1, SD1.CD2, U28.1 (CH1)
CD': R109.2, U28.16 (CH1_2); also elsewhere on the board
CLK: SD1.5, U28.6 (CH6)
CMD: R122.2, SD1.3, U28.5 (CH5)
CTRL: X1.3, X1.3A (3)
DAT0: R123.2, SD1.7, U28.7 (CH7)
DAT1: R124.2, SD1.8, U28.8 (CH8)
DAT2: R125.2, SD1.1, U28.3 (CH3)
DAT3: SD1.2, U28.4 (CH4)
E_VE_CV: PB-SE.20
E_VE_OV: PB-SE.9
E_VE_UV: PB-SE.11
GND: C11.2, C12.2, C82.2, C90.2, C91.2, C92.2, PB-NW.6, PB-SE.6, SD1.6, SD1.MT1 (MT), SD1.MT2 (MT), U4.1 (GND), U5.1 (GND), U25.1 (GND), U27.7 (GND), U28.17 (EP), U30.1 (GND), X1.1, X1.1A (1), X1.5, X1.5A (5); also elsewhere on the board
IOE_V: R104.1, R105.1, R106.1; also elsewhere on the board
IOW_V: R99.1, R100.1, R101.1; also elsewhere on the board
unnamed: C91.1, C92.1, FB1.2, R122.1, R123.1, R124.1, R125.1, SD1.4
unnamed: C90.1, R119.2, U30.7 (DREF), U30.8 (GREF)
unnamed: C11.1, R99.2, U4.7 (DREF), U4.8 (GREF)
unnamed: C12.1, R104.2, U5.7 (DREF), U5.8 (GREF)
unnamed: C82.1, R94.2, U25.7 (DREF), U25.8 (GREF)
N_CHK_V: PB-NW.13
N_VE_CV: PB-NW.18
N_VE_OV: PB-NW.7
N_VE_RS: PB-NW.8
N_VE_UV: PB-NW.19
N_VN_CV: PB-NW.16
N_VN_OV: PB-NW.5
N_VN_RS: PB-NW.12
N_VN_UV: PB-NW.17
N_VW_CV: PB-NW.14
N_VW_OV: PB-NW.3
N_VW_RS: PB-NW.10
N_VW_UV: PB-NW.15
PMOD_D0: U28.9 (CH8_2), ZED.101 (PMOD_D0)
PMOD_D1: U28.10 (CH7_2), ZED.102 (PMOD_D1)
PMOD_D2: U28.12 (CH5_2), ZED.103 (PMOD_D2)
PMOD_D3: U28.11 (CH6_2), ZED.104 (PMOD_D3)
PMOD_D6: U28.14 (CH3_2), ZED.107 (PMOD_D6)
PMOD_D7: U28.13 (CH4_2), ZED.108 (PMOD_D7)
PMOD_SCL: R107.2, ZED.105 (PMOD_D4); also elsewhere on the board
PMOD_SDA: R108.2, ZED.106 (PMOD_D5); also elsewhere on the board
S_CHK_V: PB-SE.13
S_VE_CV: PB-SE.14
S_VE_OV: PB-SE.3
S_VE_RS: PB-SE.10
S_VE_UV: PB-SE.15
S_VS_CV: PB-SE.16
S_VS_OV: PB-SE.5
S_VS_RS: PB-SE.12
S_VS_UV: PB-SE.17
S_VW_CV: PB-SE.18
S_VW_OV: PB-SE.7
S_VW_RS: PB-SE.8
S_VW_UV: PB-SE.19
VCC: FB1.1, R94.1, R95.1, R96.1, R97.1, R98.1, R102.1, R103.1, R107.1, R108.1, R109.1, R119.1, U4.2 (SREF), U5.2 (SREF), U27.14 (VCC); also elsewhere on the board
VCCIO: R92.1, R93.1, U25.2 (SREF); also elsewhere on the board
VSB: R120.1, R121.1, U30.2 (SREF); also elsewhere on the board
W_VW_CV: PB-NW.20
W_VW_OV: PB-NW.9
W_VW_UV: PB-NW.11
X_SCL: R120.2, U30.4 (S2); also elsewhere on the board
X_SDA: R121.2, U30.3 (S1); also elsewhere on the board
ZED_5V: X1.2, X1.2A (2); also elsewhere on the board
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

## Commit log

2014-05-17 new version with redesigned enclosure based on Janoschs ideas
    [Enclosure01 Alternative 01.ipt, Enclosure01.iam, Enclosure02.ipt]
2014-06-19 more progress
    [Enclosure01.iam, Enclosure02.ipt, Nikon Base 02.ipt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]
2014-07-15 more enclosure progress
    [Enclosure-Backplate01.ipt, Enclosure01.iam, Enclosure01.ipt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]
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2014-07-18 updated pcb module CAD and drawings
    [PCBModule01.idw, PCBModule01.ipt, PCBModuleLeft01.idw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]
2014-07-19 several fixes
    [Enclosure-Backplate01.ipt, Enclosure01.ipt, Enclosure02.iam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]
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2014-10-21 added image sensor model
    [CMV12000.ipt]
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2014-10-31 added new backplate variant and top plate riser
    [Enclosure-Backplate-Variant02.ipt, LensBaseTop01_riser.stp]
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2014-12-10 new concept with high speed IO on pcie x4 connector
    [Beta-Board01.ipt, BetaBoard01.ipt, Enclosure02.iam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]
2014-12-14 pcie x1 part added
    [PCB Stack Concept V03 01.iam, PCI-E x1.STEP]
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2015-01-08 added version one of the prototype skeleton 3d print part
    [BetaSkeletonV01.stp]
2015-02-10 IO shield enclosure concepts
    [HighSpeedIOShield01.ipt, IO-Shield-Sideplate01.ipt, IO-Shield-Topplate01.ipt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]
2015-02-17 new top and bend front parts
    [Beta_V2_BendFront01.ipt, Beta_V2_Top01.ipt, SFE-Host01.0002.ipt]
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2015-02-22 added f-mount component from AXIOM Alpha
    [F-mount to CMV12k-V04.ipt]
2015-02-22 updated PCB thickness and added power board PCB
    [HighSpeedIOShield01.ipt, PCBModuleLeft02.ipt, PowerPCB01.ipt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]
2015-02-22 replaced PCIe component with the one actually being used
    [PCI-E x1.STEP]
2015-02-22 zynq and pcie imported components added
    [Samtec-PCIE-036-02-D-F-TH.ipt]
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2015-02-22 removed outdated pcie connector
    [PCI-E x1.ipt]
2015-02-22 removed some outdated files, added DP connector
    [HighSpeedIOShield01.ipt, Kac12040SensorFrontEnd01.idw, LensBase02.idw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]
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2015-02-23 updated modules and assembly
    [HighSpeedIOShield01.ipt, IO-Shield-Sideplate01.ipt, IO-Shield-Topplate01.ipt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]
2015-03-13 Beta Skeleton
    Added Beta Skeleton V02 files
    [BetaSkeletonV01.stp, BetaSkeletonV02.stl, BetaSkeletonV02.stp]
2015-03-13 Beta Skeleton moved
    Skeleton files moved in skeleton folder
    [BetaSkeletonV02.stl, BetaSkeletonV02.stp]
2015-03-13 added nikon mount 3d print part
    [Nikon Mount 02.stl]
2015-03-22 skeleton version 2 finished
    [BetaSkeletonV01.ipt, F-mount to CMV12k-V05.ipt, Skeleton V02.iam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]
2015-03-24 sensor cooler preliminary model added
    [SensorCooler01.ipt]
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2015-04-02 update to fix small gap in assembly
    [BetaSkeletonV01.ipt, Skeleton V03.iam, Skeleton V03.stl]
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2015-04-03 fixed geometry by combining all parts into one
    [Skeleton V03fix.stl]
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2015-04-03 Revert "added new variant"
    This reverts commit 700cb322e26e7451e2671acac1bbda0ab89976b3.
    [1120167872.iam, 1120168000.iam, 1120168128.iam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]
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2015-04-04 add Skeleton_E-mount files
    used to mount a 10mm E-Mount tube in front of the CMV12000 image sensor
    [Beta_sensor_board_CMV12000.stp, CMV12000_E-Mount.stp, CMV12000v1.stp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]
2015-04-04 added Sensormount with higher base
    Base is raised to 50mm from the axis to fit the Nikon and Canon
    lensadapers.
    [Sensormount_CMV12000_XL.stl, Sensormount_CMV12000_XL.stp]
2015-04-28 Added H shaped adapter CMV12000 to E-mount
    Added H shaped adapter CMV12000 to E-mount
    [Sensormount_CMV12000-H.stp]
2015-04-28 added H shaped adapter CMV12000 to E-mount .stl
    added H shaped adapter CMV12000 to E-mount .stl
    [Sensormount_CMV12000_H.stl]
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2015-08-27 updated new version of stack design
    [PCB Stack Concept V03 03.iam]
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2015-09-24 added new simple design for 3d printing
    [PCB Stack Concept V03 04.iam, Simple3DPrintEnclosure01.ipt, SimpleDesignV2 - 01.iam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]
2015-10-08 added final skeleton step files
    [Skeleton-Emount.stp]
2015-10-08 added latest emount skeleton STL
    [Skeleton-Emount.stl]
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2015-10-15 fixed dimensions
    [HDMIPluginModuleHolder01.stl]
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2015-10-15 added hdmi pluging module
    [HDMI Plugin Module.ipt]
2015-10-15 increased size of cooling fan
    [Cooler.ipt]
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2015-10-30 made the part stronger and thicker
    [HDMIPluginModuleHolder02.ipt, HDMIPluginModuleHolder02.stl]
2015-10-30 smoother surfaces and distance fix
    [HDMIPluginModuleHolder02.ipt, HDMIPluginModuleHolder02.stl]
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2016-01-03 added simple design 3d print
    [SimpleDesignV2 - Front.stl]
2016-01-03 moved 3d print parts to own subfolder
    [HDMIPluginModuleHolder01.stl, HDMIPluginModuleHolder02.stl, Nikon Mount 02.stl]
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2016-02-12 added new 3d print parts
    [HDMIPluginModuleHolder01.stl, Nikon Mount 02.stl, SimpleDesignV2-R01-Back.stl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]
2016-02-12 updated 3d print parts
    [Cooler.ipt, Sensormount_CMV12000-H.ipt, Simple3DPrintBackplate01.ipt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]
2016-02-12 moved outdated version to archived folder
    [Beta_sensor_board_CMV12000.stp, CMV12000_E-Mount.stp, E-mount_tube_10mm.stp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]
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2016-02-12 added Skeleton Emount part for 3d print assembly
    [Skeleton-Emount.stl]
2016-04-12 added pcb separator tool
    [PCB-Separator-Tool-V01.stl]
2016-05-18 dimensions corrected, design simplified
    [HDMIPluginModuleHolder03.stl]
2016-05-18 fixed dimensions and simplified design
    [HDMIPluginModuleHolder03.ipt]
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2016-07-31 updated with real world measurements
    [CoolingFan50x50-V01.ipt]
2016-08-01 added e mount cap
    [AXIOM E-Mount Cap V01 R01.3dm, AXIOM E-Mount Cap V01 R01.sldprt, AXIOM E-Mount Cap V01 R01.step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]
2016-08-06 updated simple enclosure with V02
    [Simple3DPrintEnclosure02.ipt]
2016-08-06 added reflow bracket tool
    [AXIOM Beta Mainboard.ipt, Bracket_BOT_V05.ipt, Bracket_BOT_V05.stl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]
2016-08-06 fixed centimeter -> millimeter export mistake
    [Bracket_BOT_V05.stl, Bracket_TOP_V04.stl]
2016-08-10 reduced 1mm overlap to 0.5mm
    [Bracket_TOP_V04.ipt]
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2016-08-13 updated e mount cap
    [AXIOM E-Mount Cap V01 R01.3dm, AXIOM E-Mount Cap V01 R01.sldprt, AXIOM E-Mount Cap V01 R01.step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]
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2016-09-16 added cmv12000 extraction tool
    [CMV12000 Extraction Tool V01.iam, CMV12000 Extraction Tool V01.stp, CMV12000v1.ipt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]
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2016-09-18 updated and ready for first 3d print test
    [CMV12000 Extraction Tool V01.iam, Knob.stl, Knob01.ipt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]
2016-09-18 fixed problem
    [CMV12000 Extraction Tool V01.iam, Knob.stl, Knob01.ipt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]
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

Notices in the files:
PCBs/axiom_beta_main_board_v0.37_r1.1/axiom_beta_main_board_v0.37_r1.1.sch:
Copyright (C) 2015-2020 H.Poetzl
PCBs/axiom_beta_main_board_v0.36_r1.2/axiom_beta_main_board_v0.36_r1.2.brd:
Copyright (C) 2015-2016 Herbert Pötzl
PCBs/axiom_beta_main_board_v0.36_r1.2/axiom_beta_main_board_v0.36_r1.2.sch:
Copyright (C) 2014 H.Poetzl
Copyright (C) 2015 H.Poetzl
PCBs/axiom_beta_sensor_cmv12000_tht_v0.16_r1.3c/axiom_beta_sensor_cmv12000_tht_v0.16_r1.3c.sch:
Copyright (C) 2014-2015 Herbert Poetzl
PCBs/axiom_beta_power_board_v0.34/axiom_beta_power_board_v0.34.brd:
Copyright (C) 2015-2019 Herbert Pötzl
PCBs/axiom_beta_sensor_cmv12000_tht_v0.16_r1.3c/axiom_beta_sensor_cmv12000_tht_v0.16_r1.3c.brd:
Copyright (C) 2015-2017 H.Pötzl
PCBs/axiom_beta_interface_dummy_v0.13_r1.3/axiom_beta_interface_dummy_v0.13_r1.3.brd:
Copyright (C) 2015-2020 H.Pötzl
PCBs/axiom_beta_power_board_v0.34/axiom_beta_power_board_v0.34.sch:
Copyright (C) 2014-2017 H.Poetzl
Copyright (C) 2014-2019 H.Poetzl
